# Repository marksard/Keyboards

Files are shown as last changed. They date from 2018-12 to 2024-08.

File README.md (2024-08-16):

# Keyboards

This repository is warehouse of my keyboard architecture.  

## About Firmware

[Release firmware](https://github.com/marksard/qmk_firmware_hex/releases)  
[Keymap editing web service REMAP](https://remap-keys.app/)  

## WARNING
<b>Note that for these keyboards, the design is older and also less likely to support the latest firmware and architecture.<b>  
<b>Also, KICAD files may be incomplete, they are not going to be perfect.<b>

## Rhymestone

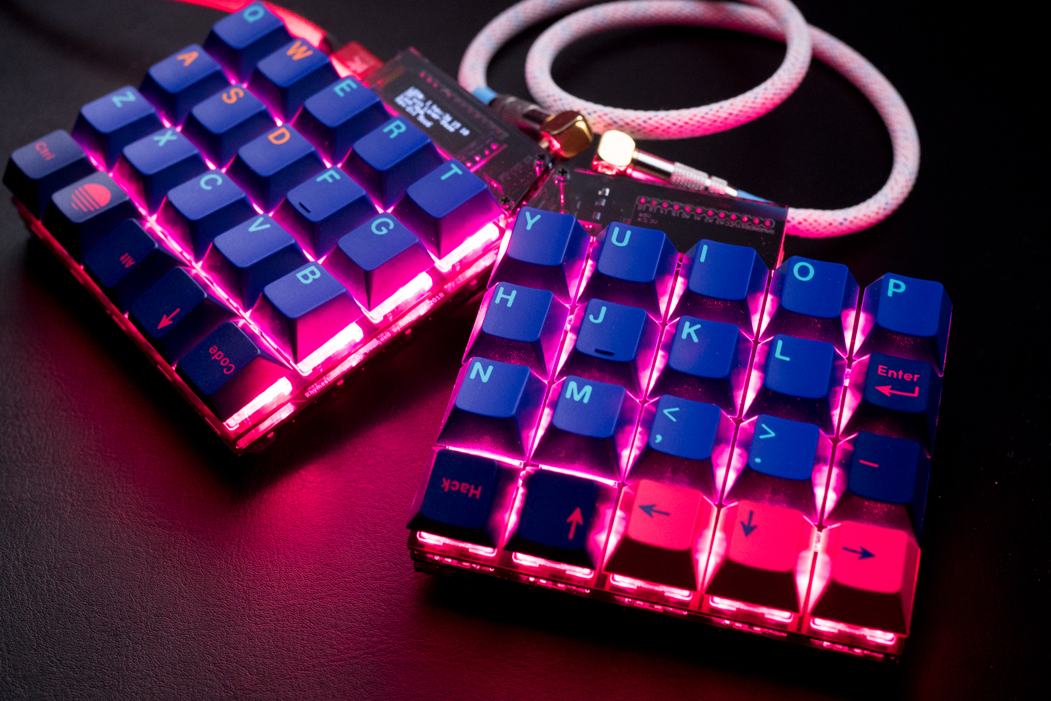
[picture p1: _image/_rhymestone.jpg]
  

### About Rhymestone

The Rhymestone is 40-key (40%) ortholinear keyboard. It is based on [The crkbd](https://github.com/foostan/crkbd) and [The Helix keyboard](https://github.com/MakotoKurauchi/helix). Thank you so much makoto kurauchi-san and foostan-san.😊  

[Build guide](./rhymestone/documents/rhymestone_buildguide.md)  
[Firmware](https://github.com/marksard/qmk_firmware/tree/own_build/keyboards/marksard/)  
[Hardware data](https://github.com/marksard/Keyboards/tree/master/rhymestone/)  

## Treadstone48

rev1  
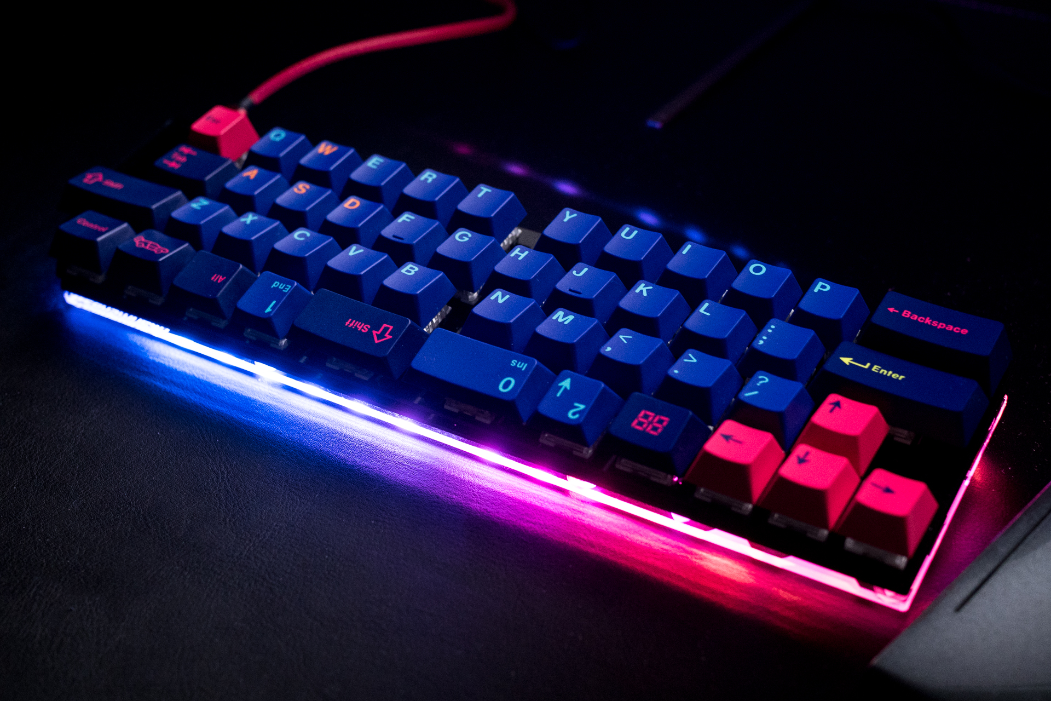
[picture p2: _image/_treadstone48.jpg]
  

rev2  
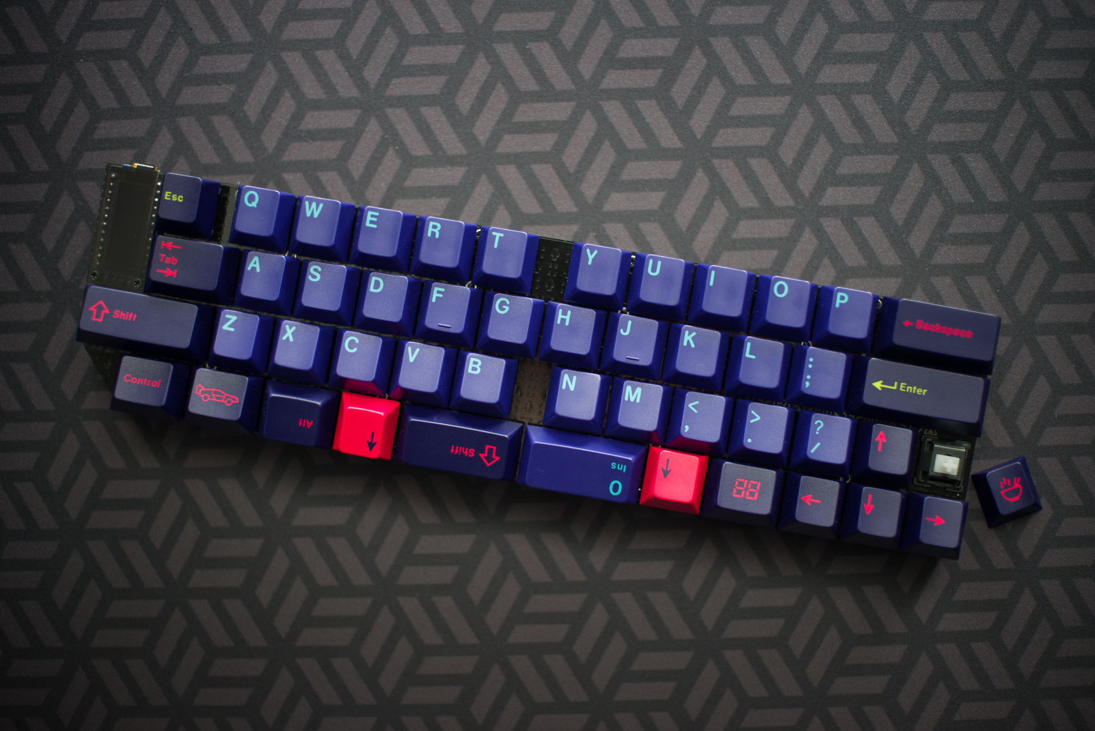
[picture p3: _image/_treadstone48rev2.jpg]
  

### About Treadstone48

The Treadstone48 is 47 or 48-key (50%) Symmetric staggered keyboard. It is based on the Rhymestone. Therefore, The Rhymestone can connect to the Treadstone48 as Numpad or lefthand keyboard. (rev1 only)  

This Symmetrical Staggered is designed to be easy to use in a natural posture and easy for your fingers to reach.  
And more one topic, this key arrangement can use general ansi 104 keycaps.

[Build guide (rev.2)](./treadstone48/documents/treadstone48rev2_buildguide.md)  

[Build guide](./treadstone48/documents/treadstone48_buildguide.md)  
[Build guide (En)](./treadstone48/documents/treadstone48_buildguide_en.md)  
[Firmware](https://github.com/qmk/qmk_firmware/tree/master/keyboards/treadstone48)  
[Hardware data](https://github.com/marksard/Keyboards/tree/master/treadstone48/)  
[About Treadstone48](https://marksard.github.io/2018/12/17/about-treadstone48/)  
[Case design sample](https://marksard.github.io/2019/04/11/wood-case/)  

## Stonehenge30 (deprecated)

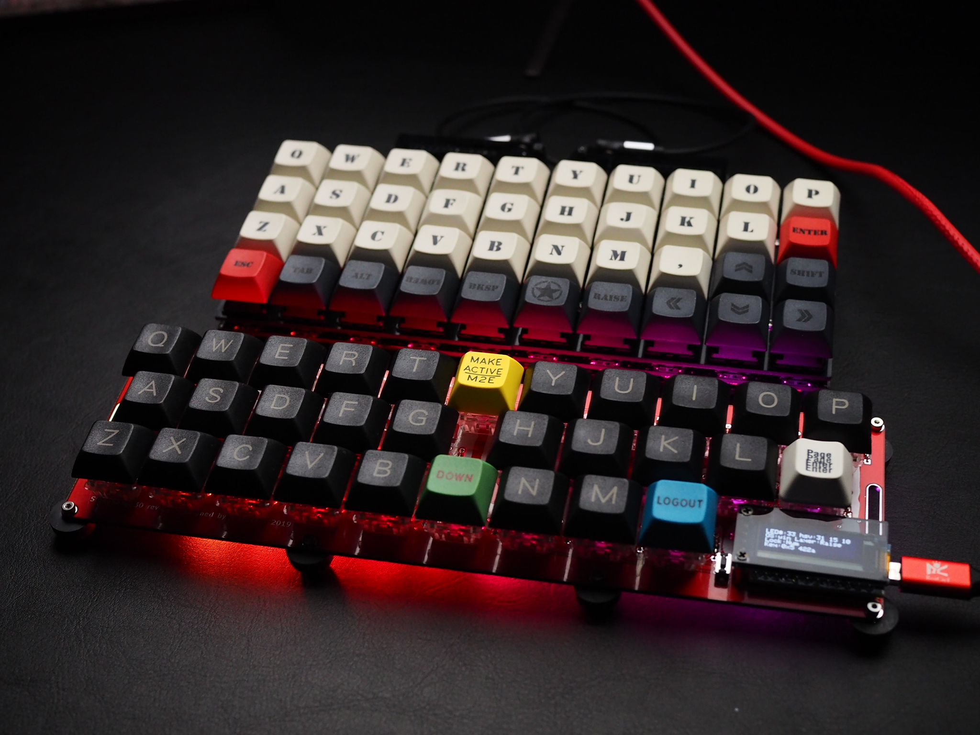
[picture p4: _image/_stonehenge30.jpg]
  

### About Stonehenge30

The Stonehenge30 is 30-key (30%) Symmetric staggered keyboard. It is based on the Treadstone48. And it is thumb-less (not use thumb) keyboard of prototype.  

[Build guide](./stonehenge30/documents/stonehenge30_buildguide.md)  
[Firmware](https://github.com/marksard/qmk_firmware/tree/own_build/keyboards/marksard/)  
[Hardware data](https://github.com/marksard/Keyboards/tree/master/stonehenge30/)  
[About Stonehenge30](https://marksard.github.io/2019/02/13/make-stonehenge30/)  
[Case design sample](https://marksard.github.io/2019/04/11/wood-case/)  

## Treadstone32

rev1  
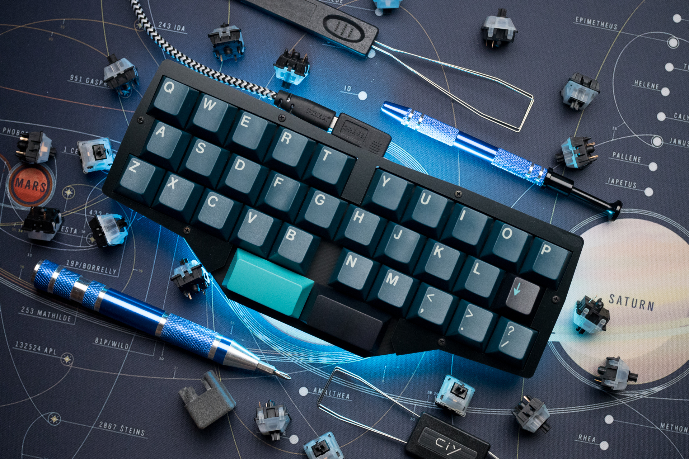
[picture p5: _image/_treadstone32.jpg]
  

lite  
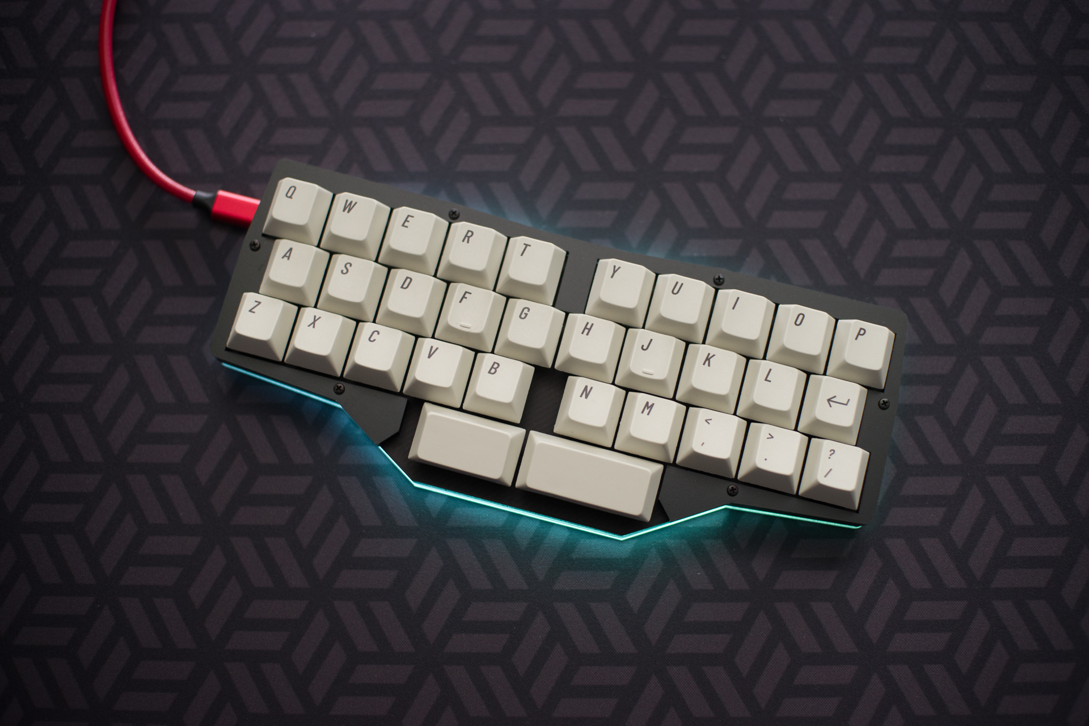
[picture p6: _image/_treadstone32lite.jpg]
  

### About Treadstone32

The Treadstone32 is 32-key (30%) Symmetric staggered keyboard. It is based on the Treadstone48 and the Stonehenge30.  
This keyboard is removing dedicated modifire-key from the Treadstone48 for more compact. But 2 thumb-key is left same as Treadtone48.  

[Build guide (lite)](./treadstone32/documents/treadstone32lite_buildguide.md)  
[Build guide](./treadstone32/documents/treadstone32_buildguide.md)  

[Build guide (En)](./treadstone32/documents/treadstone32_buildguide_en.md)  
[Firmware](https://github.com/qmk/qmk_firmware/tree/master/keyboards/treadstone32)  
[Hardware data](https://github.com/marksard/Keyboards/tree/master/treadstone32/)  
[About Treadstone32](https://marksard.github.io/2019/04/25/about-treadstone32/)  

## Treadstone60

  

### About Treadstone60

The Treadstone60 is 59-62key (60%) Symmetric staggered keyboard. It is based on the Treadstone48 and the Treadstone32.  

[Build guide](./treadstone60/documents/treadstone60_buildguide.md)  

[Firmware](https://github.com/marksard/qmk_firmware/tree/own_build/keyboards/marksard/)  
[About Treadstone60](https://marksard.github.io/2019/12/13/about-treadstone60/)  

## Leftover30

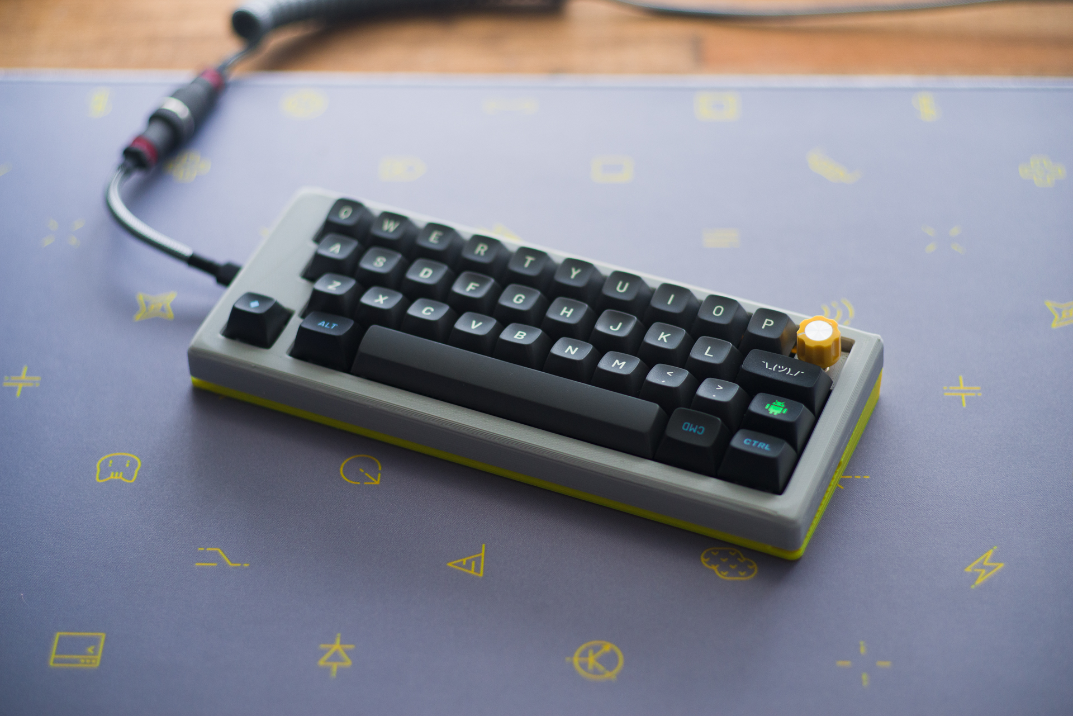
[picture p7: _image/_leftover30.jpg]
  

### About Leftover30

The Leftover30 is 34-36key (30%) Row staggered keyboard. This project was created by marksard, yohewi and hdbx.  

[Build guide](./leftover30/documents/leftover30_buildguide.md)  

[Firmware](https://github.com/marksard/qmk_firmware/tree/own_build/keyboards/marksard/)  

## Troubleshooting

[Troubleshooting](./troubleshooting.md)

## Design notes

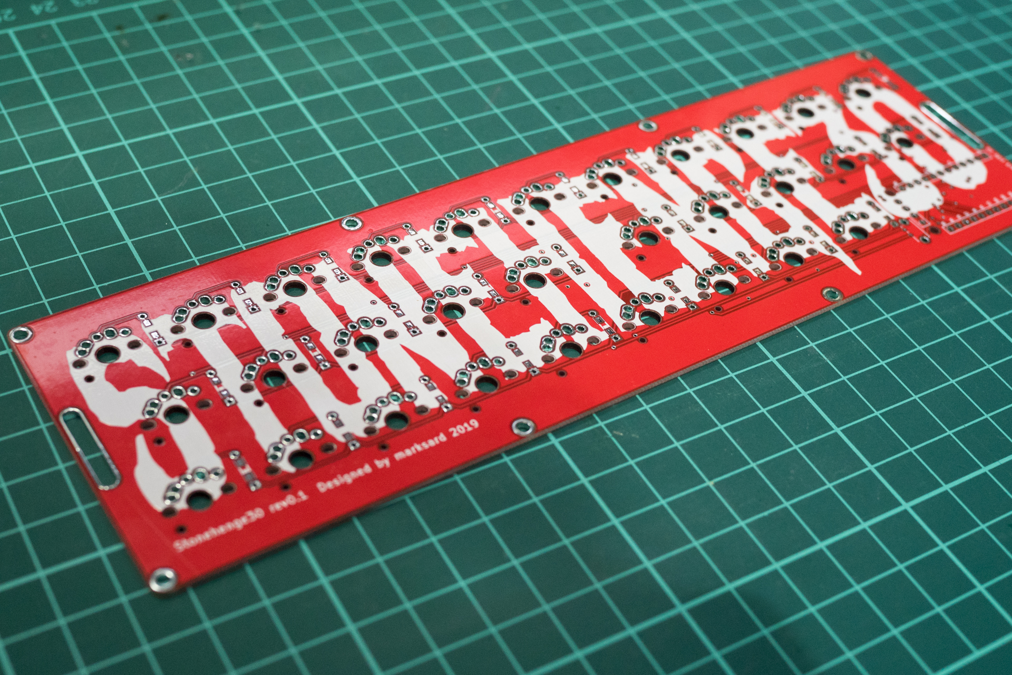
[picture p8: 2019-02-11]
stonehenge30/documents/_image/20190202-P2020237.jpg

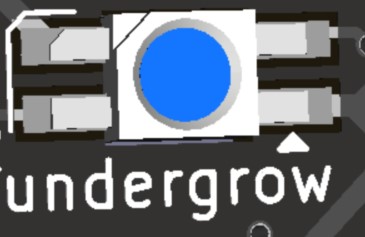
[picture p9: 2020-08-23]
leftover30/documents/_image/undergrow.jpg

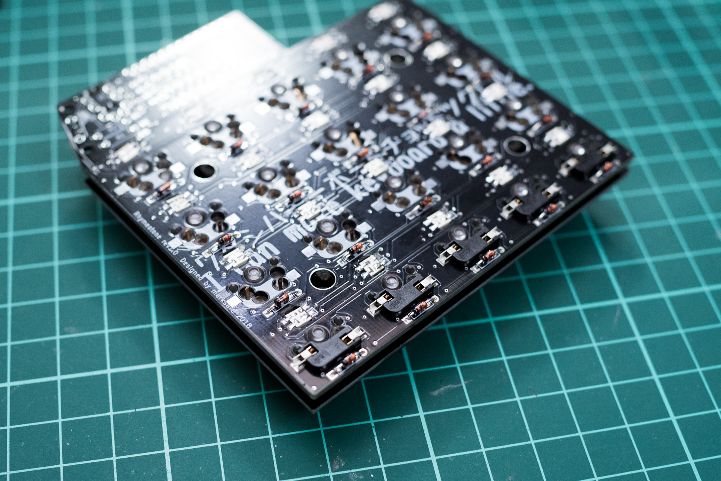
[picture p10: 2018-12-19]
rhymestone/documents/_image/20181213-PC130109.jpg

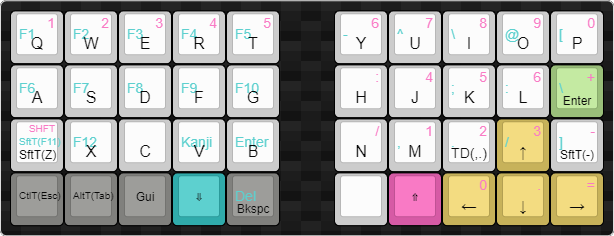
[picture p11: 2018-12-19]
rhymestone/documents/_image/rhymestone.png

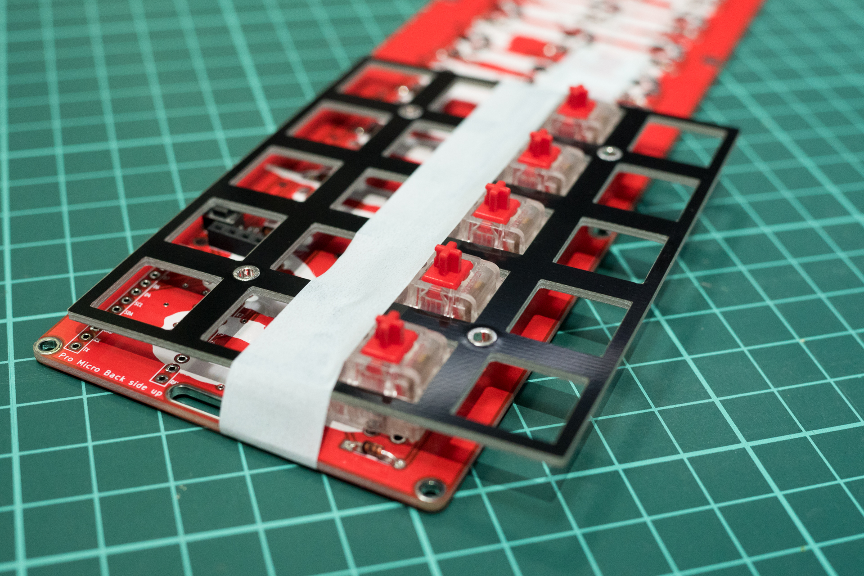
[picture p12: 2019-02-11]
stonehenge30/documents/_image/20190202-P2020240.jpg

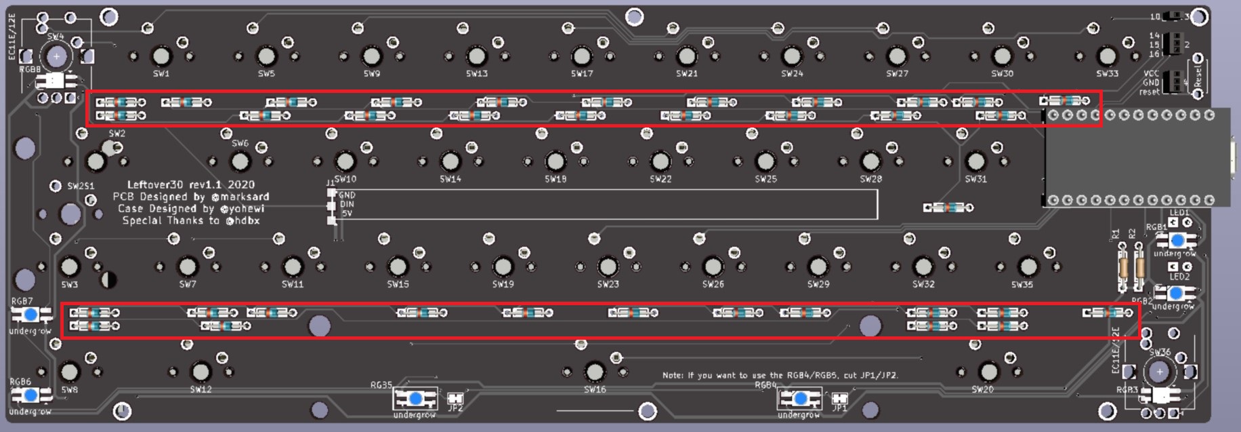
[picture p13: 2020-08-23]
leftover30/documents/_image/diode.jpg

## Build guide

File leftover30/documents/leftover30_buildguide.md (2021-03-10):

# Leftover30 ビルドガイド

## キット付属品

| 基板番号 | 数 | 名前 | 備考 |
| ---- | ---- | ---- | ---- |
| - | 1 | PCB | 基板 |
| - | 36 | 1SS178 | 1SS178（緑と黒のライン） |
| Reset | 1 | タクトスイッチ | リセットスイッチ |
| LED** | 2 | 3mm砲弾型LED | 青色と赤色 |
| R** | 2 | 抵抗 | LED用。1kΩ |
| RGB** | 6 | SK6812mini-E | アンダーグロー/バックライト用 |
| - | 1 | ケースパーツ | トップケース</br>ボトムケース</br>ロータリーエンコーダーカバー（左下用、右上用）</br>サイドアクリルパネル |
| - | 6 | M2 4mm | PCB用 |
| - | 10 | インサートナット | (Round1)ケース取り付け用 |
| - | 2 | M2 6mm | (Round1)ケース手前用 |
| - | 2 | M2 12mm | (Round1)ケース奥側用 |
| - | 12 | インサートナット | (Round2)ケース取り付け用 |
| - | 6 | M2 6mm | (Round2)ケース用 |
| - | 1 | - | ポリイミドテープ(Round2) |
| - | 4 | - | ゴム脚 |

## キット以外に必要なもの

| 名前 | 数 | 備考 |
| ---- | ---- | ---- |
| MicroUSBケーブル | 1本 | キーボードとPC接続用 |
| キースイッチ | 33～36個 | Cherry MXもしくは互換品で5pin仕様のものが必須 |
| キーキャップ | - | Cherry MXスイッチ対応品。ANSI104セット対応 |
| スタビライザー | 1～2個 | 6.25Uが1個。ISOエンターを選択した場合は2Uが1個 |
| ProMicro | 1個 | |
| コンスルー（スプリングピンヘッダ） 12P | 2個 | 推奨 |
| ロータリーエンコーダー | 0～1個 | Alps EC11/12系もしくは互換品 |
| ロータリーエンコーダー用つまみ | 0～1個 | 外径が19mm程度以下のもの（大きいとキーキャップや内枠に干渉する場合があります） |

## 注意：パーツ選択について

### MX互換スイッチについて

必ず5pinのものを用意してください。3pinのものだとそれぞれのスイッチが直角並行に並ばず、キーキャップを付けた時の見た目が悪くなります。  

### ロータリーエンコーダーについて

AlpsEC11/12互換のプッシュスイッチ付き垂直ロータリーエンコーダーに対応しています。  
互換品でよく出回っているBourns社のPEC12Rにも対応しています。  

## レイアウトの選択

### ロータリーエンコーダーとスイッチの選択

最初にレイアウトを決めます。赤枠にはMXスイッチと、AlpsEC11系シリーズ互換のロータリーエンコーダーのどちらかを選択できます。  
この位置に光を透過するタイプのMX互換スイッチを選び、バックライトLEDを取り付け、透過するアルチザンキーキャップを置いて輝かせることが可能です。  
ロータリーエンコーダーはどちらか一か所に取り付け可能です。二つ同時には取り付けられません（もし付けても両方のつまみは同じ動作となります）。  

よって選択肢は

- 左下、右上ともスイッチ
- 左下ロータリーエンコーダー、右上スイッチ
- 左下スイッチ、右上ロータリーエンコーダー

の3パターンが選択可能です。

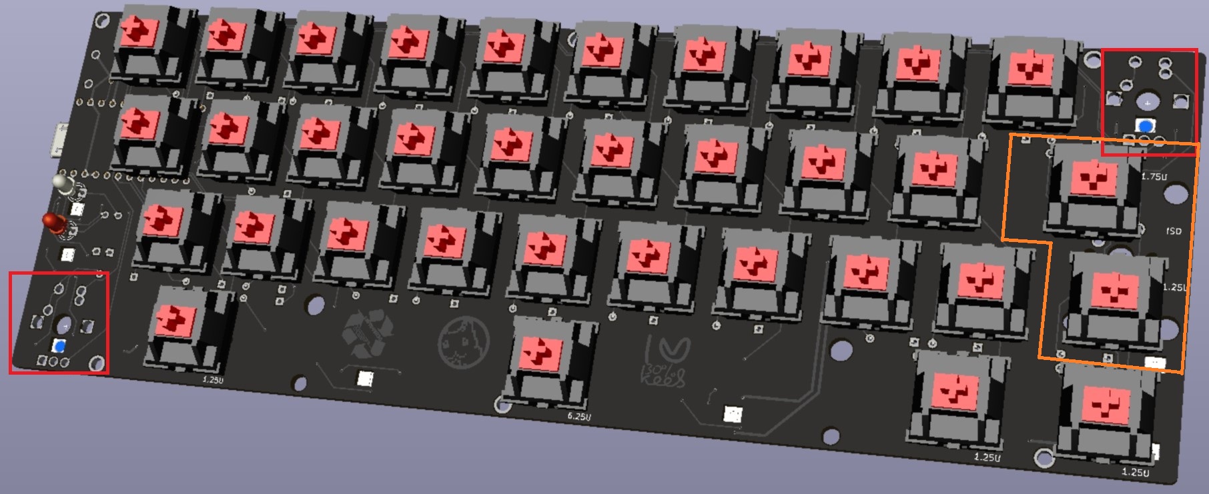
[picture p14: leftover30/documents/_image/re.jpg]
  

### エンターキーキャップの選択

橙枠は1.75Uキーと1.25Uキーの2キーを配置するか、ISOエンターの1キーを配置するかを選択出来ます。  
ISOエンターを選択した場合、LキーとISOエンターの間が0.25U隙間が出来ます。また、2Uスタビライザーが必要となります。  

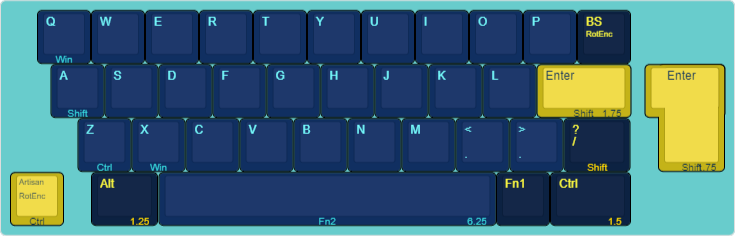
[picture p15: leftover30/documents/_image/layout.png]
  

## promicroの準備

　promicroのコネクタ補強、コンスルーピンのはんだ付けを行ってください。  
　promicroは実装されている面がキーボード基板に向くようにコンスルーを取り付けてください。  
 - promicroのコネクタ補強：[ProMicroのモゲ防止ついでにQMK_Firmwareを書き込む](https://qiita.com/hdbx/items/2f3e4ddfcadda2a5578e)
 - コンスルーピンのはんだ付け：[Helixベータ ビルドガイド](https://github.com/MakotoKurauchi/helix/blob/master/Doc/buildguide_jp.md)

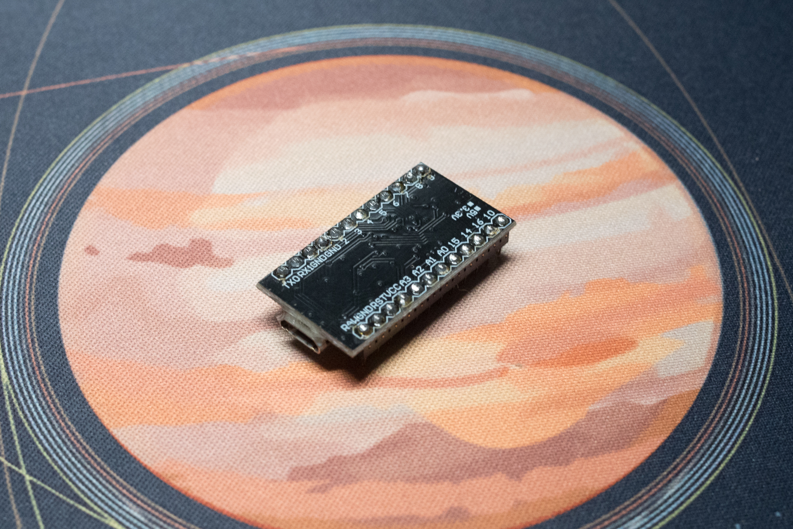
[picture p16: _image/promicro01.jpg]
  
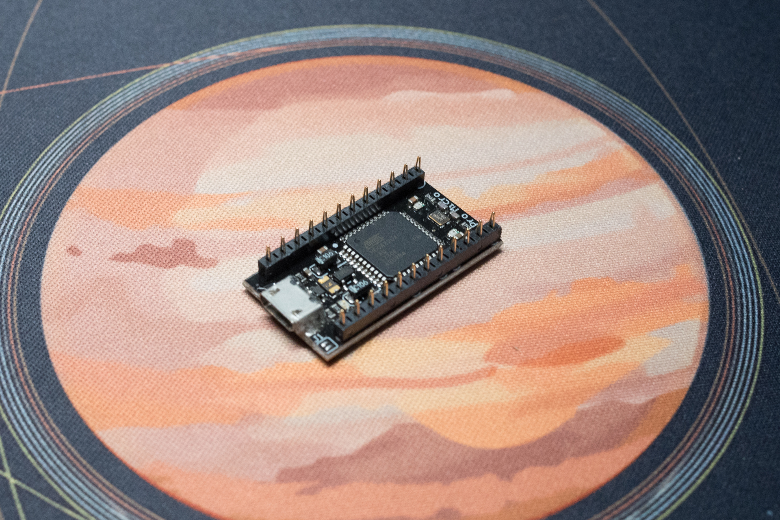
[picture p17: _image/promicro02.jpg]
  

### キーボード用ソフトウェアをpromicroに書き込む

　このキーボードはQMKというキーボード用のソフトウェアで動作します。お買い上げの時点ではこのソフトウェアが入っていない状態ですので、書き込む必要があります。  

1. [QMK Toolbox](https://github.com/qmk/qmk_toolbox/releases)をダウンロードし、インストールします
2. [marksard/qmk_firmware_hex](https://github.com/marksard/qmk_firmware_hex/releases)にある最新のhexファイルからmarksard_leftover30_via.zipをダウンロード、zipを展開します
3. QMK Toolboxの「open」ボタンをクリックして、先程展開しhexファイルを選択します
4. QMK Toolboxの「Auto-Flash」チェックボックスにチェックを入れてpromicro(直付けの場合は基板)をPCに接続し、リセットボタンを押して書き込みます。
   1. （リセットボタンをダブルクリックしないと書き込めないパターン、初回のみリセットボタンを押下しなくても書き込みが始まるのものもあります）

書き込み方法などはサリチル酸さんの[（初心者編）自作キーボードにファームウェアを書き込む](https://salicylic-acid3.hatenablog.com/entry/qmk-toolbox)の記事が参考になります。  

#### REMAPを使用する

　上記で書き込んだファイルはVIA対応ファームウェアで、ファームウェアを書き直さなくてもアプリケーション上からキー設定を変更することが出来ます。  
　ここでは国産のVIA対応キーマップ変更アプリケーションとして、WEB上からキーボードの設定が出来る[REMAP](https://remap-keys.app/)を紹介します。  
対応したキーボードを接続した状態で、「START REMAP FOR YOUR KEYBOARD」→「+KEYBOARD」ボタンを押下するとキーボード名が出ます。それを押下することでカスタマイズ画面が出てきます。  

詳しい操作方法などについてはサリチル酸さんの[（初心者編）Remapを使ってキーマップを書き換えよう](https://salicylic-acid3.hatenablog.com/entry/remap-manual)の記事が参考になります。  

　この初期状態はUSキーボード（＋日本語JISキーボードのキー配置あり）mac向けとなっていますので、適宜変更する必要があります。  
Win/Mac切り替えは(Layer3キー + E位置のキーでmac向け、Layer3キー + R位置のキー)になっています。  
漢字/英字切り替えは(Layer2キー + B位置のキー)になっています。
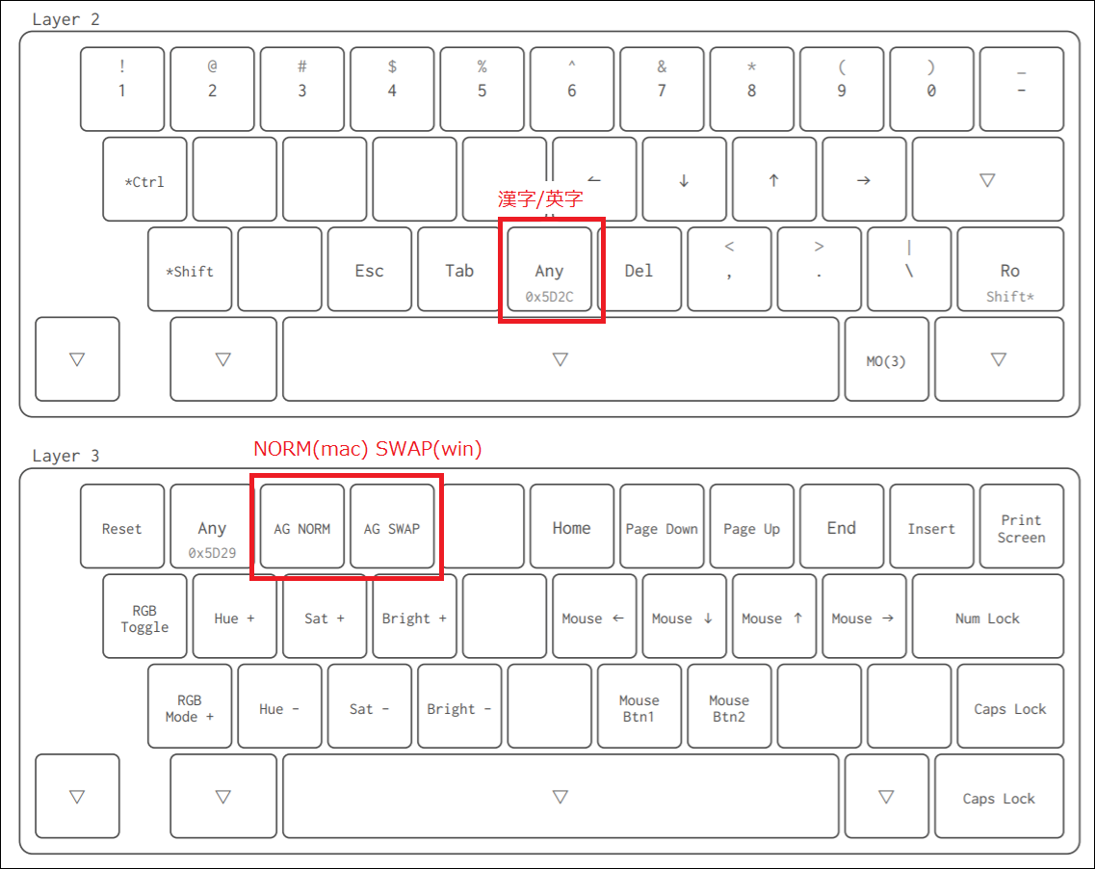
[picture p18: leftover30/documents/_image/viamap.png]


#### ビルド環境を作成する

　現状、以下のようなカスタムはソースファイルからビルドする必要があります。  

- ロータリエンコーダーの動作のカスタマイズ
- タップと長押しの判定タイミングを調整する
- OLED表示の内容を変更

　ソースからビルドが出来るようになると他の多彩な機能を扱え、細かい動作まで自在にカスタムすることが出来ます。  

[QMK　ビルド環境を準備する](https://docs.qmk.fm/#/ja/newbs_getting_started)  

　leftover30のデフォルトキーマップは  
```qmk compile -kb marksard/leftover30 -km default```
で可能です。書き込む場合は
```qmk flash -kb marksard/leftover30 -km default```  
とすると、コンパイルが完了次第書き込み待ちになるので、その状態で基板にあるリセットボタンをクリック、もしくはダブルクリックで書き込みが始まります。  

## ダイオードのはんだ付け

赤枠の位置にダイオードを向きを合わせてはんだづけします。  
向きについては以下に従ってください。  
![img](./_image/diode.jpg)  
![img](./_image/diode2.jpg)  

## 抵抗のはんだ付け（オプション）

インジケータLEDを取り付ける場合は赤枠の位置に抵抗を取り付けてください。  

![img](./_image/register.jpg)  
![img](./_image/register2.jpg)  

## フルカラーLED(SK6812mini-E)のはんだ付け（オプション）

この基板は付属のチップLEDを標準で6個取り付けることが出来ます。  
赤枠部分はアンダーグローで、ケースサイドのアクリル点灯用です。  
橙枠部分はバックライトで、BackSpace位置、アルチザン置き場位置のキーキャップ点灯用です。  
薄青枠部分は取り付けません。  
![img](./_image/sk6812mini-e.jpg)  
![img](./_image/sk6812mini-e2.jpg)  

### アンダーグロー側のはんだ付け

SK6812mini-Eは取り付ける向きがあります。点灯部分をこちらに向けて、基板に書かれた切り欠きあわせ表示（┏）にSK6812mini-Eの切り欠きを合わせてはんだ付けしてください。  
![img](./_image/undergrow.jpg)  

### バックライト側のはんだ付け

SK6812mini-Eは取り付ける向きがあります。点灯部分を反対側に向けて、基板に書かれた切り欠きあわせ表示（┏）にSK6812mini-Eの切り欠きを合わせてはんだ付けしてください。  
![img](./_image/backlight.jpg)  

### リセットボタンのはんだ付け

　リセットボタンは取り付けに向きはありません。写真のようにはんだ付けてください。  
![img](./_image/reset.jpg)  

## スイッチのはんだ付け

スイッチをはんだ付けしていきます。最初は四隅に近いところを先にはんだ付けすると作業がしやすいです。  
穴が大きめに開いている都合上はんだをドバドバ吸い込むのである程度で留めるのが吉です。  

![img](./_image/switch.jpg)  

### ロータリーエンコーダーとの選択部分にスイッチをはんだ付けする場合の注意点

ロータリーエンコーダーと選択可能な左下と右上は、基板の穴が大きいため5pinのスイッチを使っても斜めについてしまう場合があるかもしれません。  
まっすぐはんだ付け出来るように、マスキングテープなどでまっすぐな状態を維持して少量のはんだで仮固定、キャップを付けて隣同士が水平になっているか確認して大丈夫そうならスイッチをちゃんとハンダ付してください。  

### promicro上のスイッチのはんだ付けする場合の追加処理

赤枠はpromicroの上にスイッチが1キー被ります。スイッチのピンがpromicroにあたって動作が不安定になる可能性がありますので、はんだ付けした後に出っ張っているスイッチの金属ピンをカットしてください。  

![img](./_image/sw_promicro.jpg)  
![img](./_image/sw_promicro2.jpg)  

## ロータリーエンコーダーのはんだ付け（オプション）

ロータリーエンコーダーを付けたい位置に合わせてはんだ付けしてください。  

## インジケータLED(3mm砲弾型LED)のはんだ付け（オプション）

赤色と青色（LEDプラ自体は透明ですが青く光ります）LEDを付属しています。デフォルトのファームウェアではLED1はNumLock、LED2はCapsLockで点灯するようになっています。好みのほうに好みの色で取り付けてください。ケースカラーによってLEDの色が判別しにくいため、どっちでもあまり変わらないかもしれません。  
LEDは取り付ける向きがあります。脚の長いほう（アノード、＋）を丸い銀枠の穴（基板端側）に差し込みます。  

基板から、LEDの発光部のプラスチック底面までを4mm程度浮かせてはんだ付けしてください（LEDのリード線の太さがちょっと違う所あたりで約4mm程度です）。  
はんだ付けが終わったら写真のように少し傾きを付けて、トップフレームのインジケータLEDが収まるくぼみの位置を合わせておきます。  
![img](./_image/led.jpg)  
![img](./_image/led2.jpg)  
![img](./_image/led3.jpg)  
![img](./_image/led4.jpg)  

## スタビライザーの取り付け

　赤枠の位置にスタビライザーを針金が黄色い線側になるように取り付けます。  
　ISOエンターのレイアウトを選択した場合は青枠内の位置に同様にスタビライザーを取り付けてください。  
![img](./_image/stab.jpg)  
![img](./_image/stab2.jpg)  

## インサートナットの埋め込み

　はんだごての熱を利用して、ケースのビス留め位置にインサートナットを埋め込みます。取り付け位置は赤丸位置で10個所あります。  

- PCBとケースのネジ留め：6個所
- ケース同士のネジ留め：4個所
- (Round2ケースはケース同士のネジ止め箇所が中央手前と奥が増えて全部で6個所になっています)

![img](./_image/case_top.jpg)  
![img](./_image/case_bottom.jpg)  

　PCBとケースのネジ留めに使うインサートナットは、ケースの挿入面に対して垂直に。  
　ケース同士のネジ留めに使うインサートナットは下図を観てもわかるように少し傾いていますので、気持ちケース手前方向に傾けてインサートナットを挿入してください。  

![img](./_image/case.png)  

　はんだごてのこて先ははんだごてを買うと付属してくる円錐状のものを利用します。もし温度調整可能なはんだごてを利用している場合は一番低い温度に設定してください。  
　インサートナットの向きは穴の広いほう（座グリされてるほう）からネジを入れるので、そちらがケースから顔をのぞかせる方向になるように注意してください。  
　ピンセットも必要ですのですぐに使えるように準備してください。

　やりかたは以下の通りです。頭でシミュレーションしてから実施してください。  

- あらかじめケースの穴にはんだごてを直接差し込んで、穴をほんの少し広げておく（ネジ穴にケース材が入るのを防ぐ）
- インサートナットの穴の狭い方に黄色いポリイミドテープを小さく切って穴をふさぐ（ネジ穴にケース材が入るのを防ぎますが、ポリイミドテープは400度付近で溶けますので温度設定には注意してください）
- 穴位置を確認して、インサートナットを穴の広いほう（座グリされてるほう）を上に向けて置く
- こて先をキレイにして、温度調節可能なら270度などの低い温度に設定して、インサートナットにはんだごてをあてる（3Dプリントケースは200度程度で溶けだします）
- 上からゆっくりとケースの穴の周りを溶かしながら入れる
- ケース面まで埋めたらはんだごてをはずす
- 冷えるまで30～60秒は待つ

![img](./_image/case_ins1.jpg)  
![img](./_image/case_ins2.jpg)  

[![insertnut](http://img.youtube.com/vi/4Yi3AIbshDU/0.jpg)](http://www.youtube.com/watch?v=4Yi3AIbshDU)

　ケースの素材がナットの周辺に盛り上がってしまった場合、冷えてからニッパーなどで切り落としてください。  
　もし斜めだったり、穴位置がずれていたりする場合はもう一度はんだごてを当てて修正してください。  
　修正しすぎて穴が広がった場合、穴の周辺にはんだごてをあてて穴を少し狭めてからやりなおしてください。  

　インサートナットを取り付けたら一度トップケースとボトムケースを合わせてネジ留め出来るか仮組確認してください。ケース奥側は12mm、ケース手前側は6mmのネジで留めます。  

## ロータリーエンコーダーカバーの取り付け

　ロータリーエンコーダーを取り付けた場合はカバーを取り付けてください。  
　左下用はケースにハメ込めるようになっています。  
　右上用はロータリーエンコーダーの外装にハメ込めるようになっています。  

![img](./_image/re_cover.jpg)  
![img](./_image/re_cover2.jpg)  

## ケースの組み立て

### PCBをボトムケースに取り付ける

　PCBをボトムケースのネジ穴に合わせて置き、4mmのネジで留めてください。  

### トップケースをボトムケースに取り付ける

　トップケースをボトムに合わせます。ケース手前にはスリットが設けられており、ここにアクリルを挟みます。挟んだら6mmのネジで留めます。ケース奥側は12mmのネジで留めます。  

![img](./_image/sidegrow.jpg)  

### ゴム脚について

　このキーボードはソフトな打鍵感を意識して設計しています。ゴム脚を装着するとケースとデスクの間に空間が生まれさらに柔らかくなりますので、特にデスクマット上での使用を前提とする場合は取り付けないほうが良い打鍵感を得られる場合があります。ゴム脚を付ける前に打鍵感をチェックしてみてください。  

## キーキャップ、つまみを取り付けて完成です

　お好きなキーキャップと、ロータリーエンコーダーを取り付けている場合は好きなつまみを取り付ければ完成です！

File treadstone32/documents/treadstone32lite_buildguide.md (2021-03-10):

# Treadstone32 Liteビルドガイド

## キット付属品

| 基板番号 | 定数 | 数 | 名前 | 備考 |
| ---- | ---- | --- | --- | --- |
| - | - | 1 | PCB | 基板 |
| - | - | 32 | 1N4148 or 1SS178 | ロットにより1N4148（黒ライン）か1SS178（緑と黒のライン）どちらか |
| - | - | 1 | リセットスイッチ |  |
| - | - | 1 | マウントプレート | スイッチをはめ込むプレート |
| - | - | 1式 | アクリルケースパーツ | </br>2mmボトムプレート</br>2mmボトムミドル</br>5mmボトムミドル</br>5mmトップカバー |
| - | M2 8mm | 6 | 低頭ネジ |
| - | M2 4mm | 6 | 低頭ネジ |
| - | M2 スペーサー 7mm | 6 | 丸型 全ねじスペーサー |
| - | 2mm | 5 | ゴム脚 |  |

## キット以外に必要なもの

| 名前 | 数 | 備考 |
| ---- | ---- | --- |
| MicroUSBケーブル | 1本 | キーボードとPC接続用 |
| キースイッチ | 32個 | MX互換のもの |
| キーキャップ | 1U 30個、2U 2個 | MX互換のもの |
| ProMicro | 1個 | |
| コンスルー（スプリングピンヘッダ） 12P | 2個 | 推奨 |

### オプション

オプションでイルミネーション用LEDを取り付け可能です。  

| 名前 | 数 | 備考 |
| ---- | ---- | --- |
| LEDストリップ（WS2812B 6個付き） | 1個 | Underglow用（オプション） |

## 必要な道具

| 名前 | 備考 |
| ---- | ---- |
| はんだごて | |
| 糸ハンダ | 0.8mm程度のものを推奨します |
| ハンダ吸い取り線 | 失敗したとき用 |
| ニッパー | ダイオードのリード線などの切断用です |
| ピンセット | ProMicroリセットしたりチップLEDのはんだづけで使用します |
| フラックス除去剤 | 必須ではありませんがはんだ付け後のベタつきを除去出来、はんだによる黄色い変色も拭き取れてキレイな仕上がりになります |
| マスキングテープ | しるし付け、仮固定に使用。100均の柄付きでもOK |

　mteiさんの[Helix キーボードキットの製作に必要な工具メモ](https://gist.github.com/mtei/6957107a676ddfa85bde0ae41f8fa849)
やhdbxさんの[自作キーボードを始めるにあたって用意すべきツール](https://hdbx.hateblo.jp/entry/2018/06/01/215401)も参考になります。  

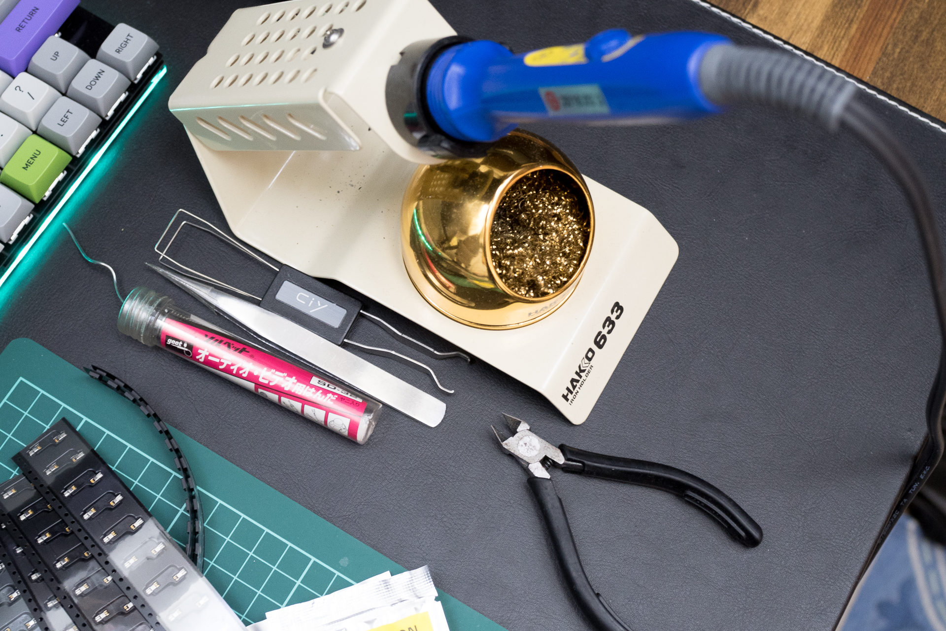
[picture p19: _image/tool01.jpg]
  
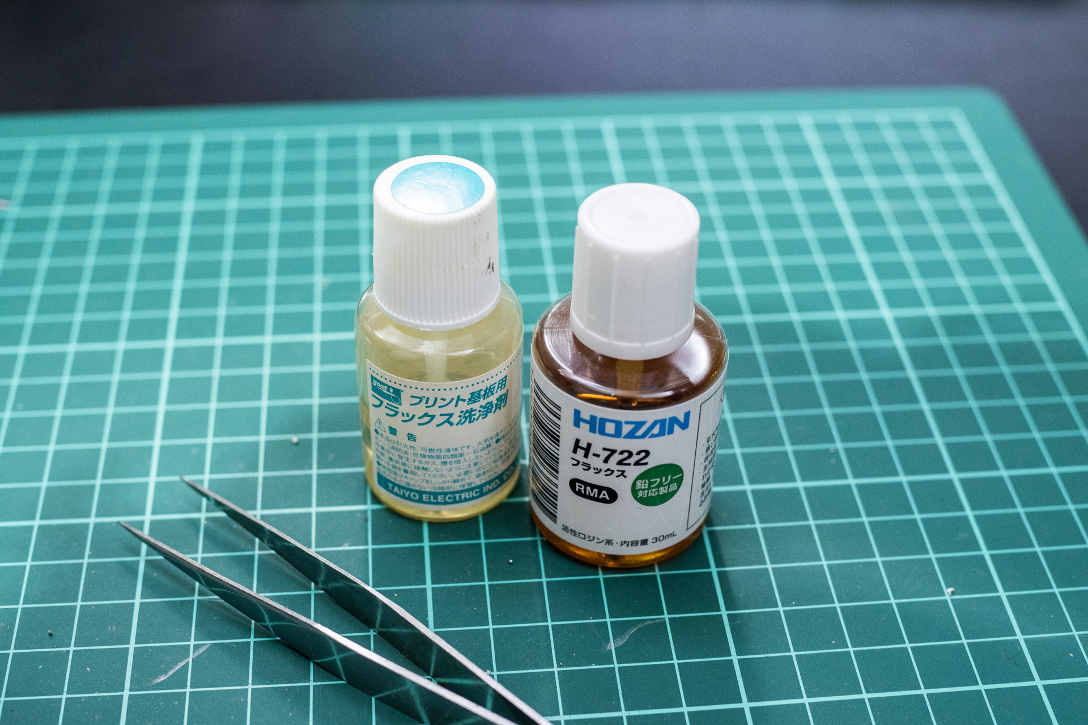
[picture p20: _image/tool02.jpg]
  

## promicroの準備

　promicroのコネクタ補強、コンスルーピンのはんだ付けを行ってください。  
　promicroは実装されている面がキーボード基板に向くようにコンスルーを取り付けてください。  
 - promicroのコネクタ補強：[ProMicroのモゲ防止ついでにQMK_Firmwareを書き込む](https://qiita.com/hdbx/items/2f3e4ddfcadda2a5578e)
 - コンスルーピンのはんだ付け：[Helixベータ ビルドガイド](https://github.com/MakotoKurauchi/helix/blob/master/Doc/buildguide_jp.md)

  
  

### キーボード用ソフトウェアをpromicroに書き込む

　このキーボードはQMKというキーボード用のソフトウェアで動作します。お買い上げの時点ではこのソフトウェアが入っていない状態ですので、書き込む必要があります。  

1. [QMK Toolbox](https://github.com/qmk/qmk_toolbox/releases)をダウンロードし、インストールします
2. [marksard/qmk_firmware_hex](https://github.com/marksard/qmk_firmware_hex/releases)にある最新のhexファイルからtreadstone32_lite_via.zipをダウンロード、zipを展開します
3. QMK Toolboxの「open」ボタンをクリックして、先程展開しhexファイルを選択します
4. QMK Toolboxの「Auto-Flash」チェックボックスにチェックを入れてpromicro(直付けの場合は基板)をPCに接続し、リセットボタンを押して書き込みます。
   1. （リセットボタンをダブルクリックしないと書き込めないパターン、初回のみリセットボタンを押下しなくても書き込みが始まるのものもあります）

書き込み方法などはサリチル酸さんの[（初心者編）自作キーボードにファームウェアを書き込む](https://salicylic-acid3.hatenablog.com/entry/qmk-toolbox)の記事が参考になります。  

#### REMAPを使用する

　上記で書き込んだファイルはVIA対応ファームウェアで、ファームウェアを書き直さなくてもアプリケーション上からキー設定を変更することが出来ます。  
　ここでは国産のVIA対応キーマップ変更アプリケーションとして、WEB上からキーボードの設定が出来る[REMAP](https://remap-keys.app/)を紹介します。  
対応したキーボードを接続した状態で、「START REMAP FOR YOUR KEYBOARD」→「+KEYBOARD」ボタンを押下するとキーボード名が出ます。それを押下することでカスタマイズ画面が出てきます。  

詳しい操作方法などについてはサリチル酸さんの[（初心者編）Remapを使ってキーマップを書き換えよう](https://salicylic-acid3.hatenablog.com/entry/remap-manual)の記事が参考になります。  

　この初期状態はUSキーボード（＋日本語JISキーボードのキー配置あり）mac向けとなっていますので、適宜変更する必要があります。  
Win/Mac切り替えは(Layer3キー + E位置のキーでmac向け、Layer3キー + R位置のキー)になっています。  
漢字/英字切り替えは(Layer1キー + B位置のキー)になっています。
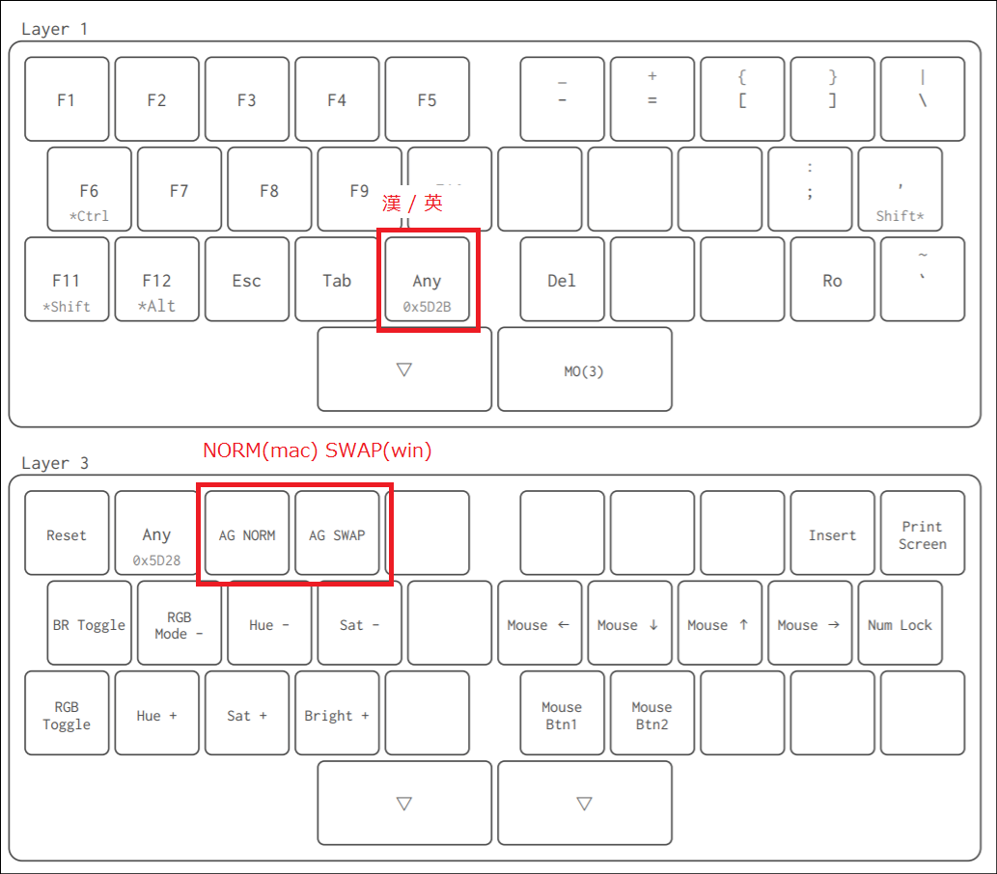
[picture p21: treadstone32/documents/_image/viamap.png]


#### ビルド環境を作成する

　現状、以下のようなカスタムはソースファイルからビルドする必要があります。  

- ロータリエンコーダーの動作のカスタマイズ
- タップと長押しの判定タイミングを調整する
- OLED表示の内容を変更

　ソースからビルドが出来るようになると他の多彩な機能を扱え、細かい動作まで自在にカスタムすることが出来ます。  

[QMK　ビルド環境を準備する](https://docs.qmk.fm/#/ja/newbs_getting_started)  

　treadstone32liteのデフォルトキーマップは  
```qmk compile -kb treadstone32/lite -km default```
で可能です。書き込む場合は
```qmk flash -kb treadstone32/lite -km default```  
とすると、コンパイルが完了次第書き込み待ちになるので、その状態で基板にあるリセットボタンをクリック、もしくはダブルクリックで書き込みが始まります。  

## 基板の裏と表について

　キースイッチが乗り、通常使用する際上を向く面を表、逆を裏とします。  
　Treadstone32Liteはロゴマークがシルク印刷されているほうが裏面です。  

## ダイオードをはんだ付けする

### ダイオードの脚を曲げる

　基板に付ける前にダイオードの脚を全部曲げてしまいます。基板の穴の間隔を見極めて曲げるための冶具を探してみてください。繋がったままの割りばしなどでも良いと思います。  

![img](../../_image/diode01.jpg)  

### ダイオードのはんだ付け

　ダイオードの取り付け向きは同じ方向なので、一つ確認して取り付けたら残りはすべて同じ方向で取り付けられます。ダイオードの黒や緑の帯側を基板のダイオード取り付け穴の四角いほうに向けて取り付けてください。  

![img](../../_image/diode02.png)  

　基板のウラ面からダイオードを差し込んでいきます。差し込んだらダイオードの足同士をネジって仮留めします。横一列ずつ差し込んでまとめてハンダ付けするとラクに速く出来ます。ハンダ付けしたら足を根元からカットしてください。  

## リセットボタンのはんだ付け

　スイッチがシルク印刷に収まる方向にはんだ付けしてください。  

![img](_image/lite_reset.jpg)  

## スイッチのはんだ付け

　スイッチの向きに注意してマウントプレートにはめこみます。そのあと、写真のように合わせてはんだ付けしてください。  
※写真は動作検証のためソケット化するカスタムをしています。

![img](_image/20200509-P5090001.jpg)  

## *(オプション)UnderglowLEDをはんだ付けする*

　テープLEDの剥離紙の両端数cmだけハサミなどでカットします。これはテープLEDの背面の端子と、キーボード基板のスルーホールなどの端子が接触して動作不良を起こすことを防ぐ意味合いがあります。  

![img](../../_image/led_tape.jpg)  

　テープLEDは向きがありテープLEDの端子と基板の端子が合う向きにします。
![img](_image/20200509-P5090001.jpg)  

## 動作確認をこの時点で行う

　あとはケースを組み立ててキーキャップをつけるだけですが、ケースを組み立てるのと分解するのが若干面倒なのと、ダイオードがキチンと半田付けされているかの動作確認を済ませておくとケース組み立てが一回で済むので「ファームウェアの準備と書き方」を見てファームウェアを書き込んで動作確認をしてください。  

### 動作確認

　デフォルトキーマップの場合、Lower、Raise（左親指キー、右親指キー）の順で押下するとAdjustレイヤーになります。押下したまま、Aキーを押下するとLEDのON/OFFです。光らない場合はLEDの取り付け向きやはんだ箇所をチェックしてください。  

## キーキャップの取り付け

　ケースの組み立て時、トップレイヤーとキーキャップが干渉しないように取り付ける必要があるので、先にキーキャップをハメ込んでください。  

## ケースの組み立て

　ケースのパーツは2mm厚のものと、5mm厚のものがあります。  
　2mmボトムプレートと2mmボトムレイヤーを合わせてみて、ボトムレイヤーにスペーサーをはめ込む場所が6箇所あります。その位置にボトムプレートへM2 4mmのネジで取り付けてください。  
　ProMicro用の切り欠きがあるので、写真のように2mmのフレームを合うように組み合わせてください。  

![img](_image/20200509-P5090002.jpg)  

以下の順番で乗せていきます。  

| 層名 | 厚み | 上 |
| --- | --- | --- |
| トップレイヤー | 5mm |  |
| マウントプレート(PCB付) | 1.2mm |  |
| ミドルレイヤー | 5mm |  |
| ボトムレイヤー | 2mm |  |
| ボトムプレート | 2mm | 下 |

　全部乗せたら、トップレイヤーの位置をキーキャップに干渉しないように位置を合わせながらM2 8mmネジで6箇所留めてください。  
　ゴム脚は四隅と、2つの親指キーの間手前に一つ貼ってください。  
　添付のゴム脚の厚みは1.6mmのものです。気になるようでしたら追加でゴム脚を貼ってみてください。  
　左奥側はProMicroに干渉するので、ゴム脚をカットして貼り付けてください。  
　また、ProMicroのピン部分が机に干渉する場合があるので、ニッパーでキレイにカットしておいてください。  

![img](_image/20200509-P5090002a.jpg)  

## 完成

　チェックして問題なさそうなら完成です！あなただけの一台に仕上げてください！  

![img](_image/20200119-P1190029.jpg)  

## キースイッチの交換方法

　手では取り外しにくいため、amazonなどで販売されているキースイッチ引き抜き工具を使用して交換してください。

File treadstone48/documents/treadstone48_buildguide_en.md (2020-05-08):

# Treadstone48 Build Guide

## List of parts

### Parts included when buying the TS48 kit

| Name | Quantity | Note |
| ---- | ---- | --- |
| PCB | 1 | |
| Mount Plate | 1 | FR4(PCB plate) |
| Acrylic Bottom Plate | 1 | |
| Acrylic Pro Micro Cover | 1 | |
| M2 spacer 8mm | 2 | use with Acrylic Pro Micro Cover |
| M2 spacer 7mm | 8 | use with Acrylic Bottom Plate |
| Plastic spacer 2mm | 8 | use with Acrylic Bottom Plate |
| M2 Screw 4mm | 18 | |
| M2 Black Screw 4mm| 2 | Top use with Acrylic Pro Micro Cover |
| Rubber Feet | 8 |  |
| 1N4148 diode | 48 |  |
| TRRS Jack | 1 | not use |
| Reset Switch | 1 | |

### Please purchase separately (not included)

| Name | Quantity | Note |
| ---- | ---- | --- |
| MicroUSB cable | 1 | |
| Key Switches | 47～48 | Compatible for MX |
| Key Caps | 47～48 | compatible for MX stem, Better than ANSI104 keysets |
| Pro Micro | 1 | |
| Pin  12P | 2 | For use with Pro micro |
| Kailh MX Socket | 47〜48 | Kailh socket |
| *Stabilizer* | *1～2* | *PlateMount* |
| *LED strip（WS2812B x6）* | *2* | *Underglow* |

### Firmware

[Treastone48 QMK Directory](https://github.com/qmk/qmk_firmware/tree/master/keyboards/treadstone48)

Make example for this keyboard (after setting up your build environment):

    make treadstone48:default

See the [build environment setup](https://docs.qmk.fm/#/getting_started_build_tools) and the [make instructions](https://docs.qmk.fm/#/getting_started_make_guide) for more information. Brand new to QMK? Start with our [Complete Newbs Guide](https://docs.qmk.fm/#/newbs).

## Soldering of Diodes

Steps.  

 - Lead Forming
 - Insert in the through hole (Be careful of the direction of the diode)
 - Soldering

  
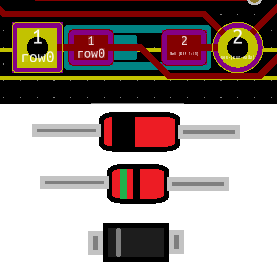
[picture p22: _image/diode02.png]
  

## Insert key switches to Mount Plate

The parts of the picture can be installed according to your preference.  

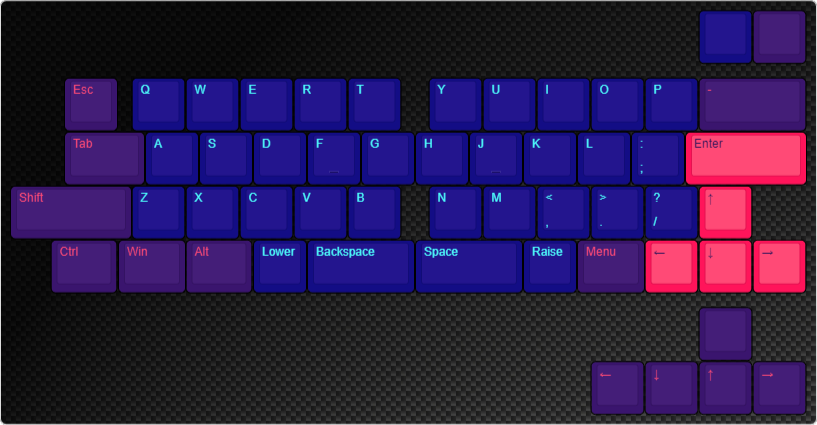
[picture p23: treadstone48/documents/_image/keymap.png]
  
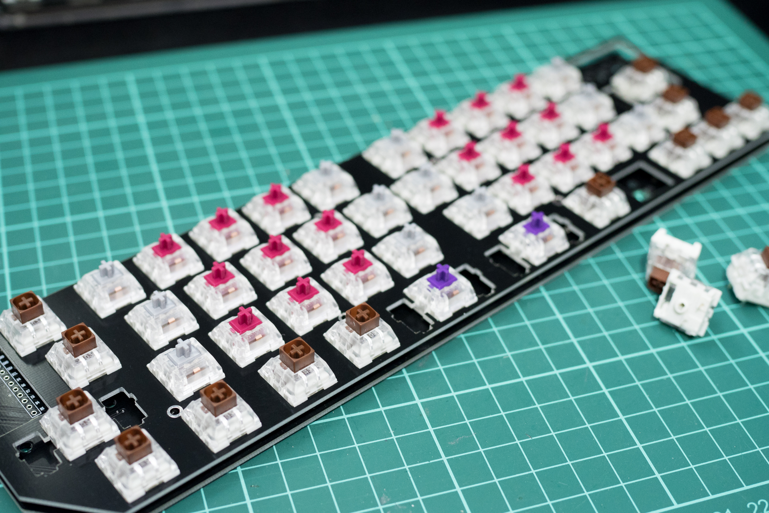
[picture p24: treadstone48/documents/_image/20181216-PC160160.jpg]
  
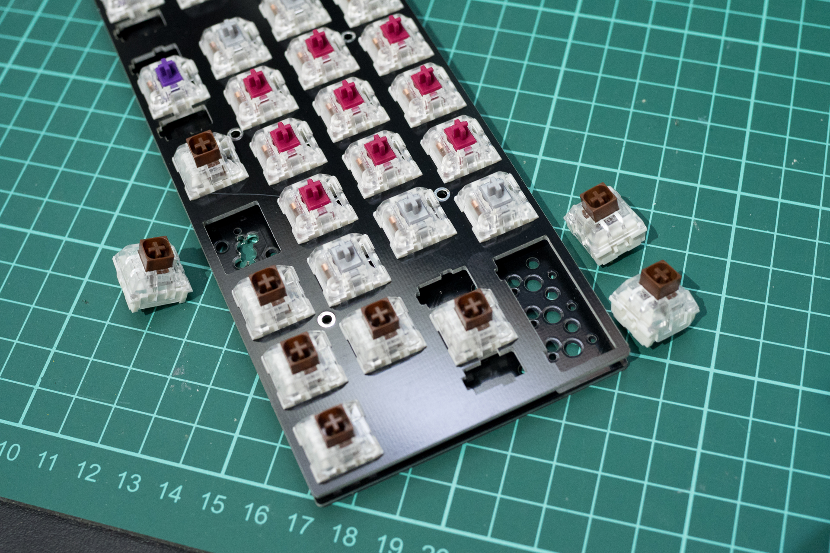
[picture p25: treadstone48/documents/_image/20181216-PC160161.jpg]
  

## Soldering of Sockets

 A first, Combine the PCB and the mounting plate.  
 And then Insert the socket into the pin of the switch protruding from the PCB. (be careful with the orientation)  
 Solder the terminal and PCB of both ends of the socket.  

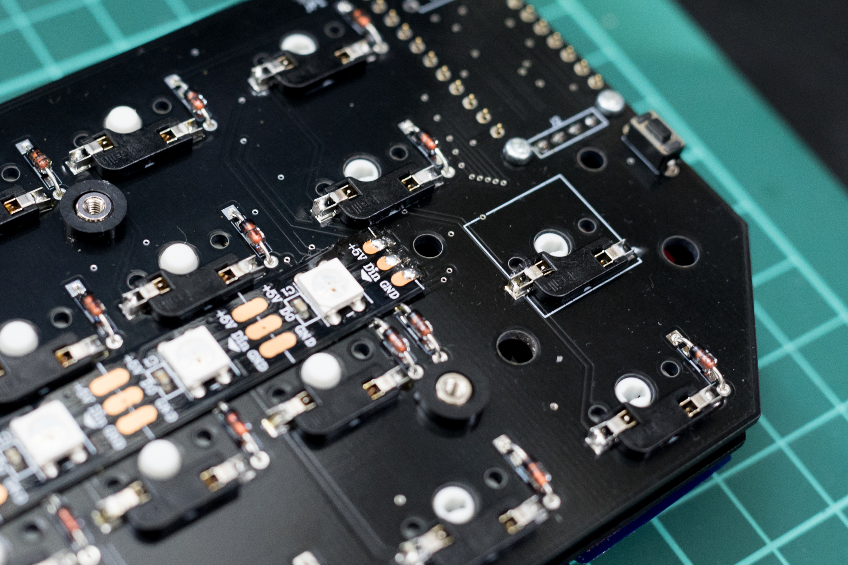
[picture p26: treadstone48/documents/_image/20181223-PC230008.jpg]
  

### Soldering of Pro micro

　Be careful with the orientation.  

  
  

### Soldering of Reset Switch

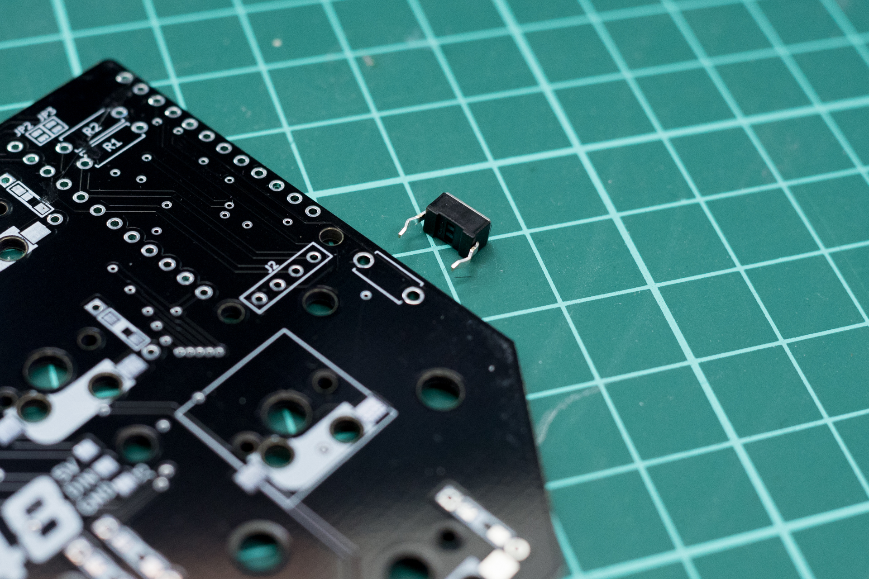
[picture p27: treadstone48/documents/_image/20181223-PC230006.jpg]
  

### SOldering of LED Strip

　Be careful with the orientation.  

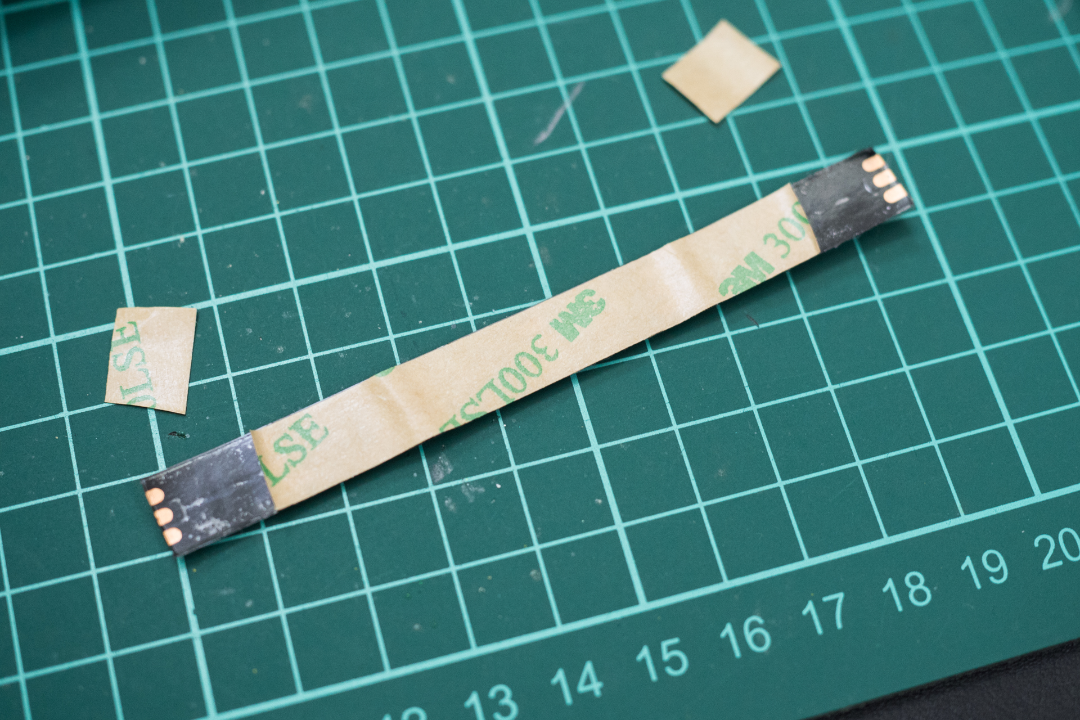
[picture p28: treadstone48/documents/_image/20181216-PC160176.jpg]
  
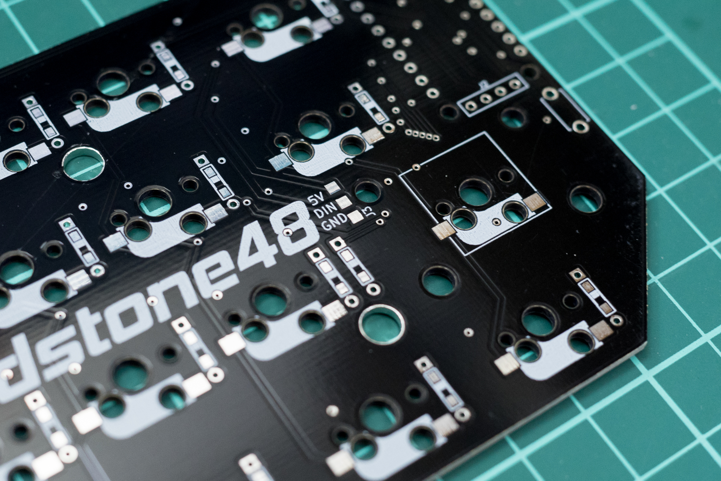
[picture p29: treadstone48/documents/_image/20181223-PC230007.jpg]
  
  

## Attach the Acrylic Cover

Use an 8 mm spacer, 2 4 mm screws and 2 4 mm black screws. Attach the cover to the PCB.

## Install Acrylic Bottom Plate

　Use 8 spacers of 7 mm, 8 spacers of plastic and 16 screws of 4 mm. Remove the bottom plate protective paper and attach the PCB.

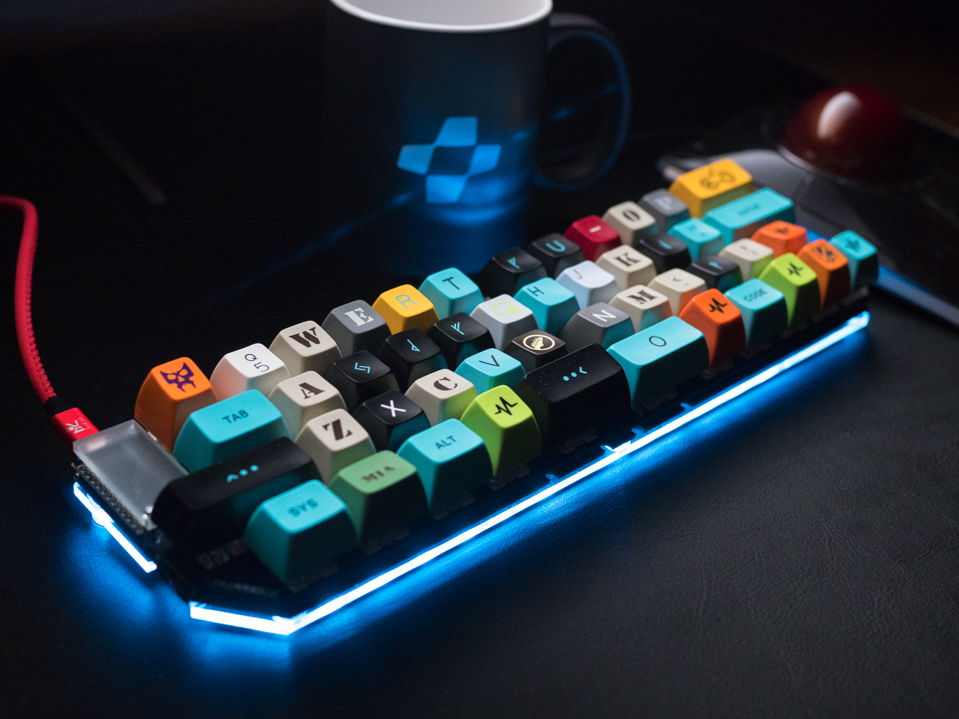
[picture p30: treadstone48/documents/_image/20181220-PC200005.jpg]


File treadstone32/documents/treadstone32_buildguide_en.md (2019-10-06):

# Treadstone32 Build Guide

## List of parts

### Parts included when buying the TS48 kit

Small surface mount components are include spares.  

| Name | Quantity | Note |
| ---- | ---- | --- |
| PCB | 1 | |
| Mount Plate | 1 | FR4(PCB plate) |
| Acrylic Bottom Plate | 1 | 2mm Frost |
| Acrylic Middle Layer | 1set | 2mm Frost |
| Acrylic Middle Layer | 1set | 5mm Mat Black |
| Acrylic Top Cover | 1 | 5mm Mat Black |

| Name | Quantity | Note |
| ---- | ---- | --- |
| Screw | 6 | M2 8mm |
| Screw | 6 | M2 4mm |
| Spacer | 6 | M2 7mm |
| Rubber Feet | 5 | |

| Name | Quantity | Note |
| ---- | ---- | --- |
| C1 | 2 | Capacitor 0.1uF 1206size (In Plastic case) |
| C2-C3 | 3 | Capacitor 1uF 1206size  |
| C4-C5 | 3 | Capacitor 22pF 1206size (Thin height) |
| R1-R2 | 3 | Resister 22ohm 1206size (22R0) |
| R3-R4 | 3 | 10Kohm 1206size (1002) |
| F1 | 1 | Fuse 500mA 0805size ("4" is written on the body) |
| X1 | 1 | Crystal FA-238 16MHz ("1600" is written on the body) |
| U1 | 1 | MCU atmel ATMEGA32U4-AU |
| J1 | 1 | micro USB Connector |
| (D1-D32) | 33 | 1N4148 SOD-123 |
| (SW1-SW32) | 32 | Kailh MX Socket |
| Reset1 | 1 | ResetSw |

### Please purchase separately (not included)

| 名前 | 数 | 備考 |
| ---- | ---- | --- |
| Key Switches | 32 | Compatible for MX |
| Key Caps | 32 | compatible for MX stem, Better than ANSI104 keysets |
| MicroUSB cable | 1 | |
| *LED strip（WS2812B x6）* | *1* | *Underglow* |

### Firmware

[Treastone32 QMK Directory](https://github.com/qmk/qmk_firmware/tree/master/keyboards/treadstone32)

Make example for this keyboard (after setting up your build environment):

    make treadstone32:default

See the [build environment setup](https://docs.qmk.fm/#/getting_started_build_tools) and the [make instructions](https://docs.qmk.fm/#/getting_started_make_guide) for more information. Brand new to QMK? Start with our [Complete Newbs Guide](https://docs.qmk.fm/#/newbs).

## Soldering of micro USB connector

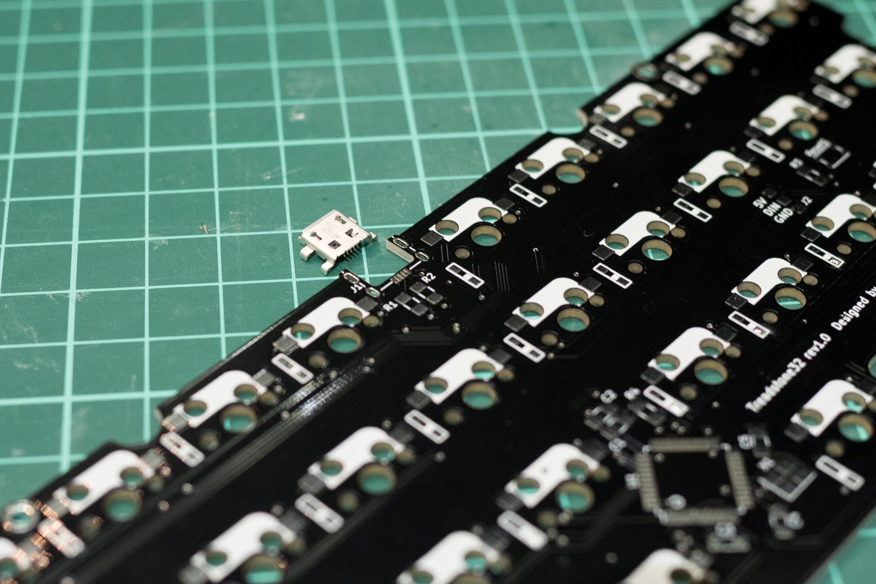
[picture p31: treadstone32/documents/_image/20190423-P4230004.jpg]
  

## Soldering of atmega32u4

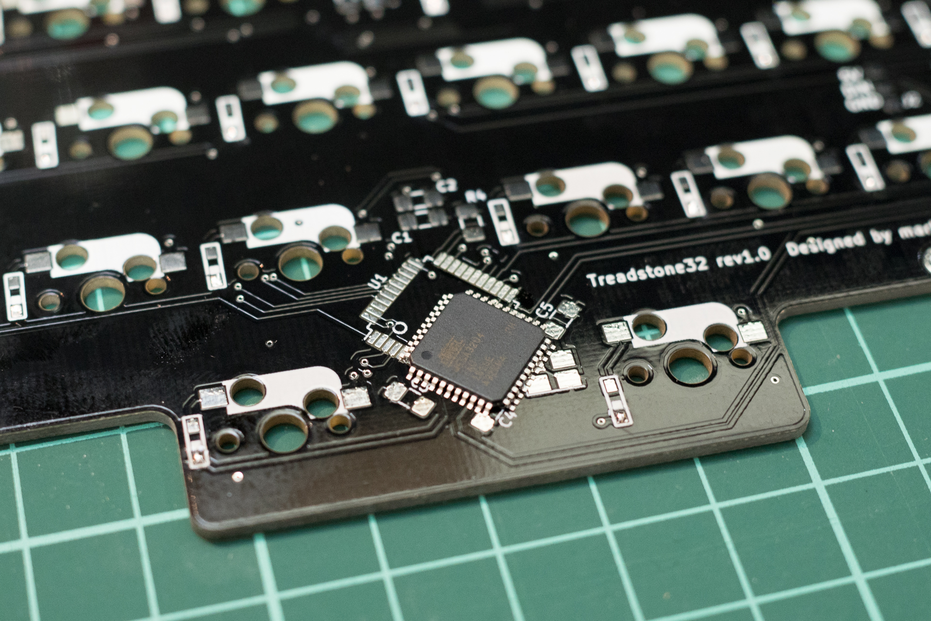
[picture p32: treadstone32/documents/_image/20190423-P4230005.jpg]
  

## Soldering of Crystal

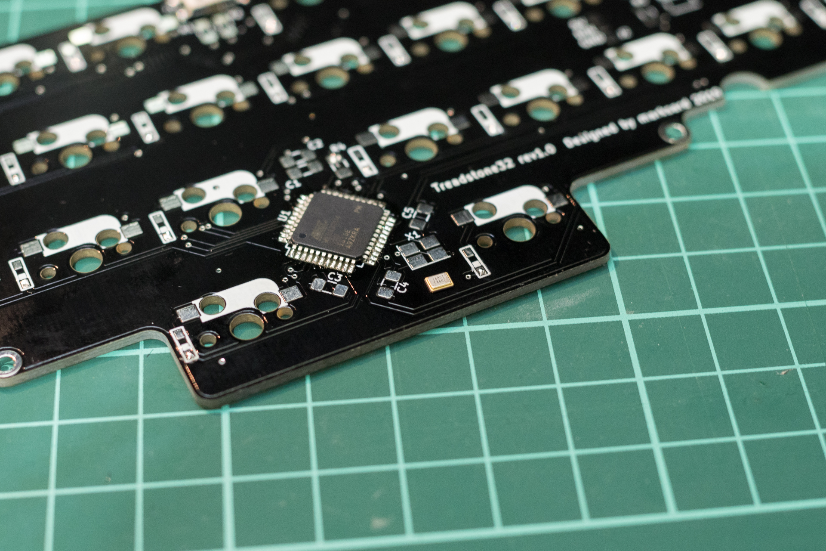
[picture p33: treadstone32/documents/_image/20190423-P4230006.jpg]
  

## Soldering of Capacitor

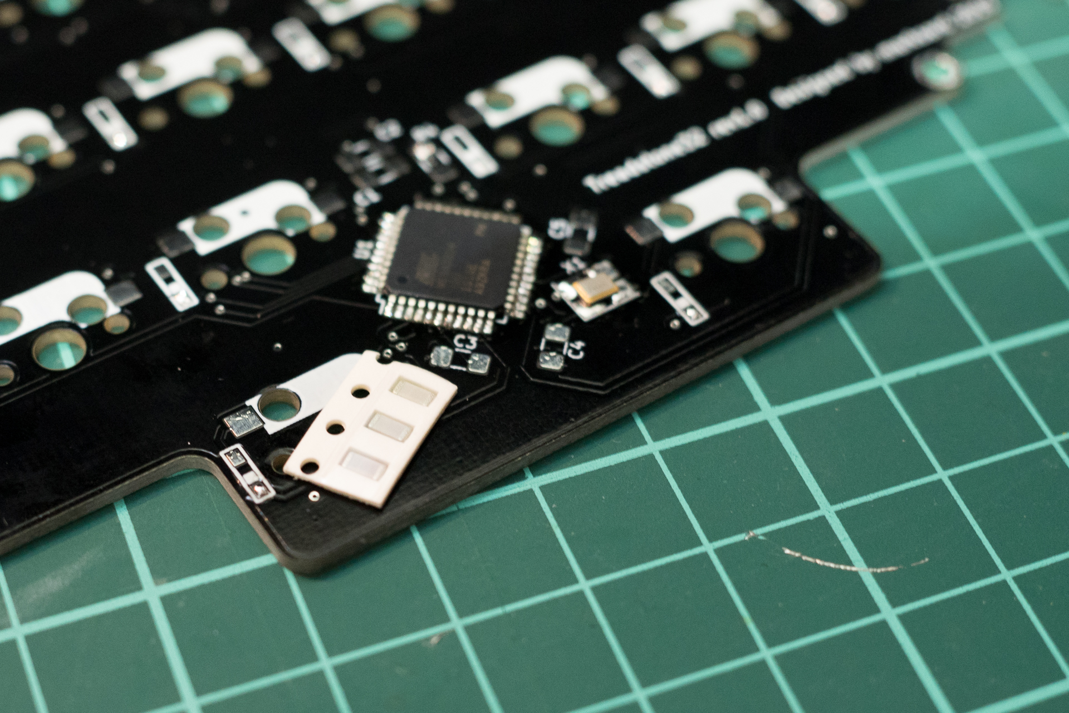
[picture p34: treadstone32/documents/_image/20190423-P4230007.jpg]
  

## Soldering of Resister

## Soldering of Reset Button

## Soldering of Fuse

## Soldering of Diode

## Soldering of MX Socket

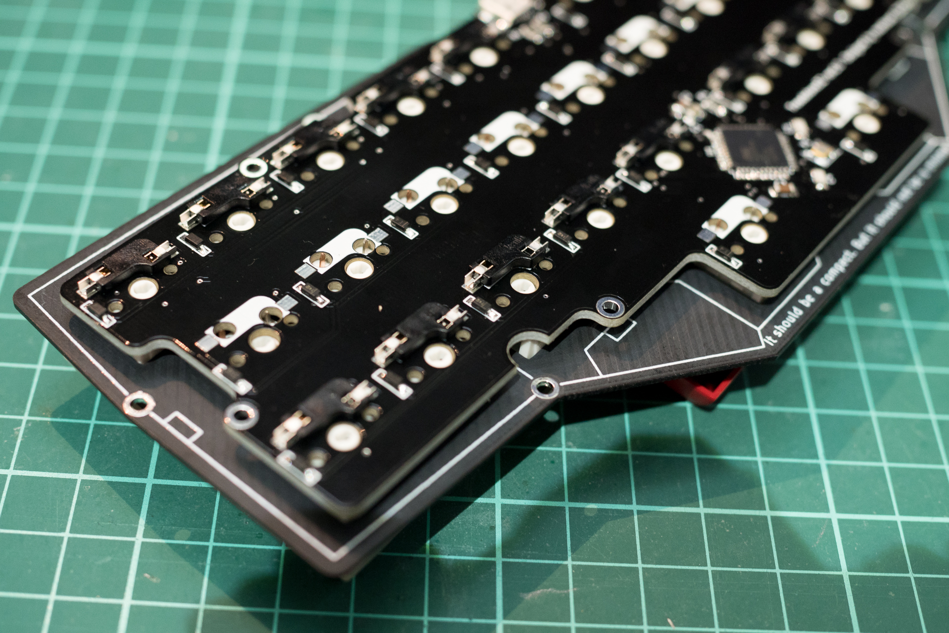
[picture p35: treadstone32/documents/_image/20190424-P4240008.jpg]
  
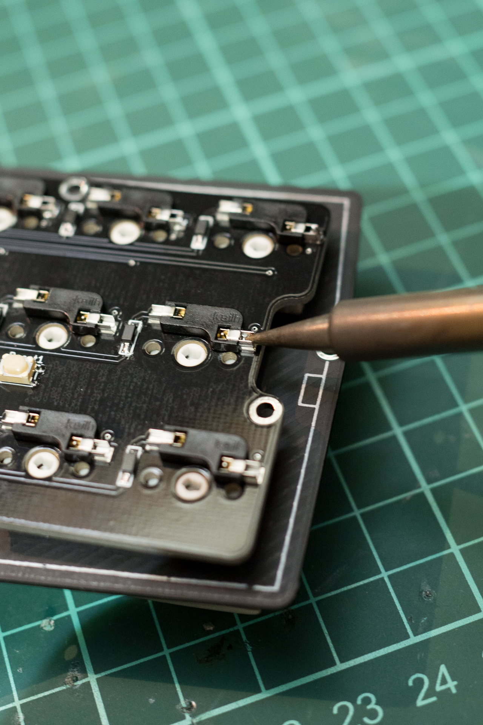
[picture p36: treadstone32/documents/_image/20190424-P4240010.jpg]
  
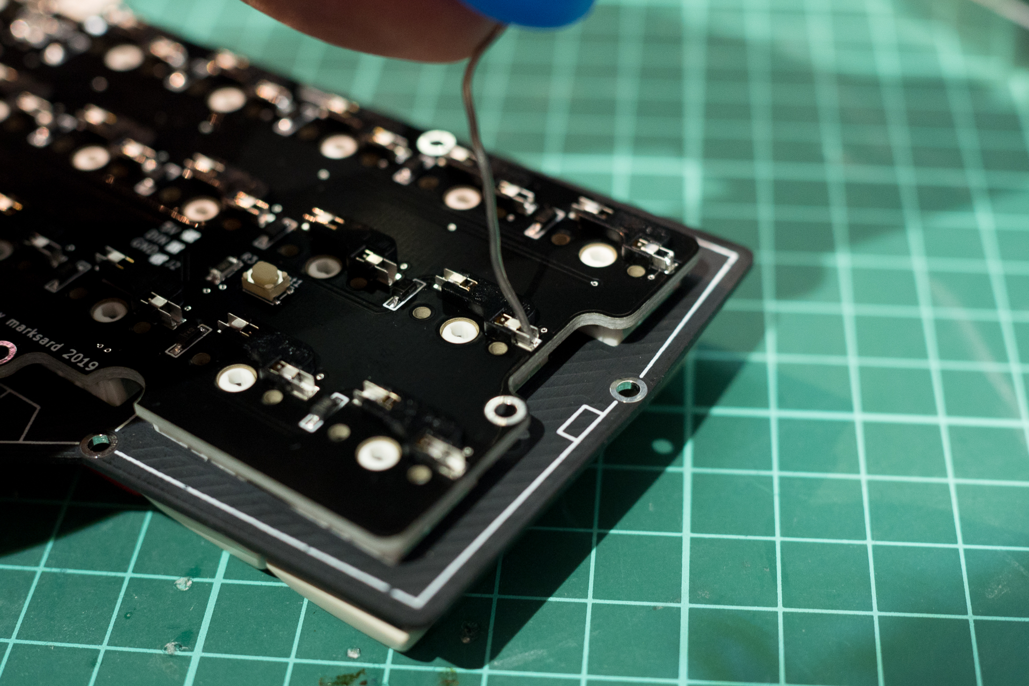
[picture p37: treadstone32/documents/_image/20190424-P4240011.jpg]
  

## Confirm of ATm32U4DFU in PC

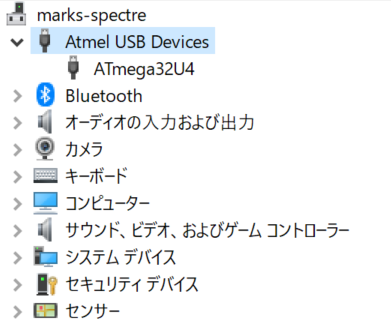
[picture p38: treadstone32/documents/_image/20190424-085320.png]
  
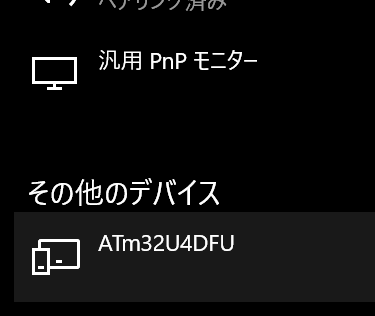
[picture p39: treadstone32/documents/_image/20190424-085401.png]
  

## *Soldering of UnderglowLED*

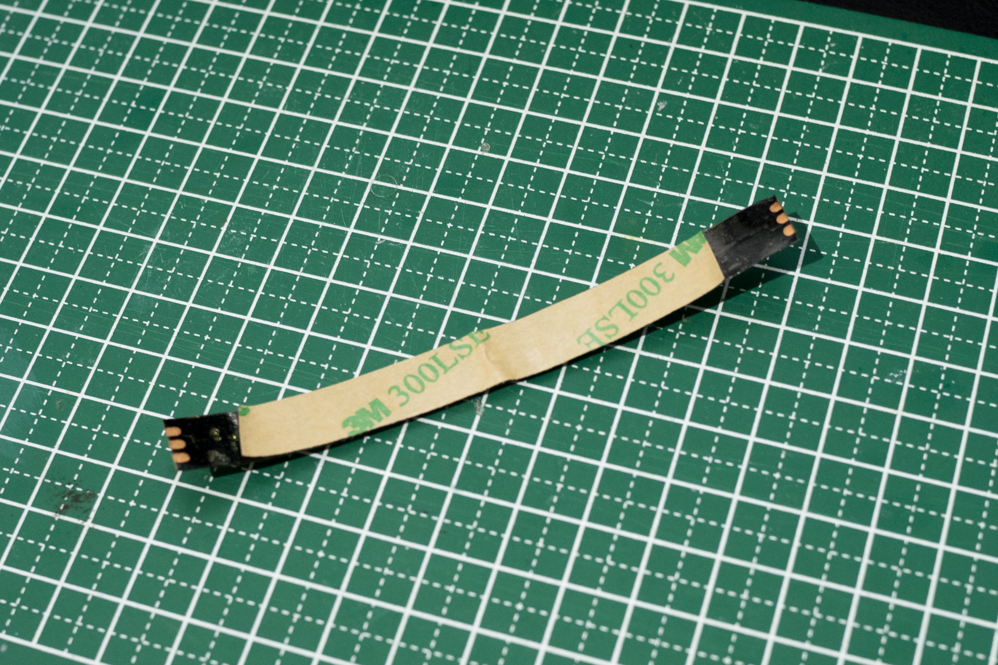
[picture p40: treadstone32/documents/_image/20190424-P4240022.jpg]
  
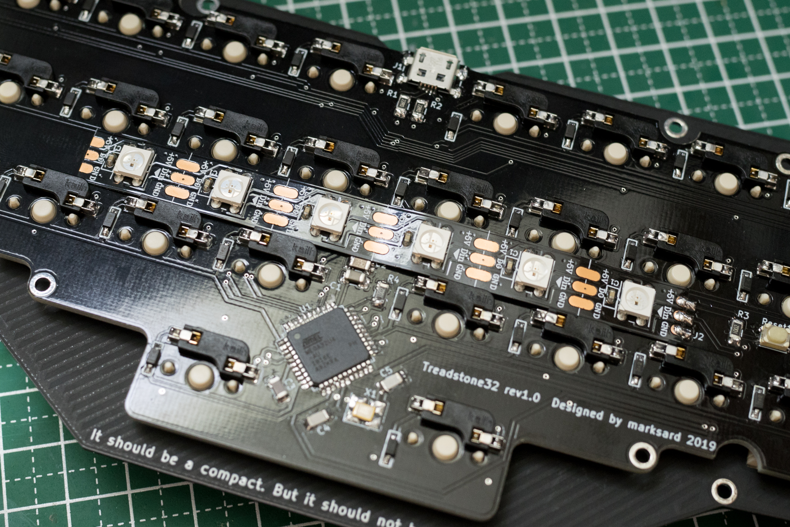
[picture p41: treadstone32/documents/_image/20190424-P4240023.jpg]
  

## Build of case

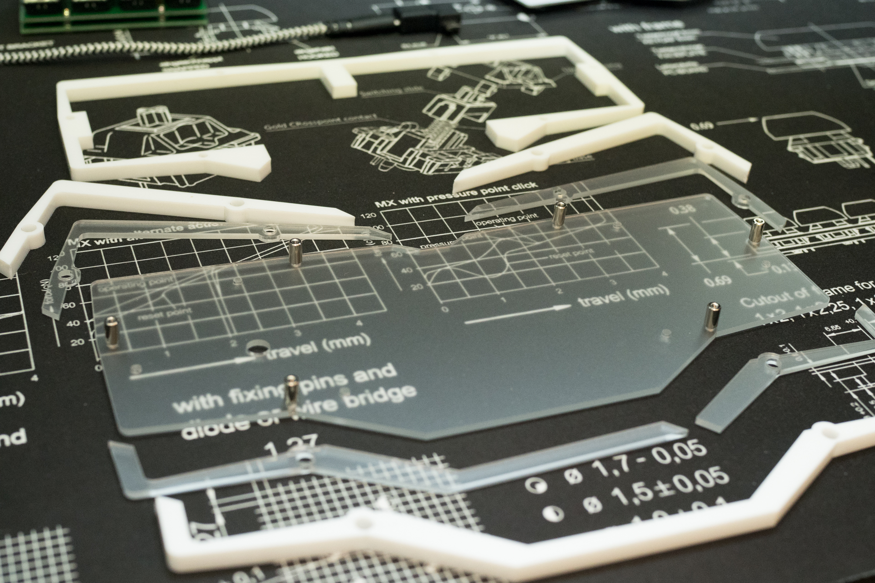
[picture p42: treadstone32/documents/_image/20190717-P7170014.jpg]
  
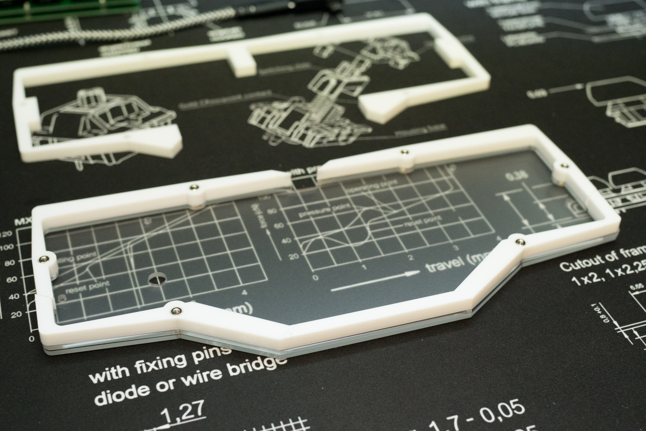
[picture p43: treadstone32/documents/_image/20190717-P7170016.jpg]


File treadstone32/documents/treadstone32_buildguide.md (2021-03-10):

# Treadstone32ビルドガイド

## はじめに

　Treadstone32はすべてチップ部品を使っており、ピッチの細かい部品のはんだ付けがあるため自作キーボードの中でも難易度は高いです。まず使用する道具はちゃんとそろえてくださいますようお願いいたします。  
　また特にmicroUSBのピンとMCUのピンはピッチが狭いため、慣れないとハンダで隣のピンをブリッジすることがあります。これを気づかずに電源を入れると最悪部品をを破損しますので重ねてご注意くださいますようお願いいたします。  

## キット付属品

| 基板番号 | 定数 | 数 | 名前 | 備考 |
| ---- | ---- | --- | --- | --- |
| C1 | 0.1uF | 2 | コンデンサ(1206size) | プラスチックのリールケースに入っていて1uFよりも色が薄く、一番厚みがある |
| C2-C3 | 1uF | 3 | コンデンサ(1206size) | 一番色が濃い |
| C4-C5 | 22pF | 3 | コンデンサ(1206size) | 一番色が薄く、厚みも薄い |
| R1-R2 | 22ohm | 3 | 抵抗(1206size) | 22R0と書いてある |
| R3-R4 | 10Kohm | 3 | 抵抗(1206size) | 1002と書いてある |
| F1 | 500mA | 1 | リセッタブルヒューズ(0805size) | 4て書いてるもの |
| X1 | 16MHz | 1 | 水晶振動子 EPSON FA-238 | 裏にパッドが4つあって、表に薄く1600とか書いてある |
| U1 | - | 1 | MCU atmel ATMEGA32U4-AU |  |
| J1 | - | 1 | micro USB MOLEX 47642-0001 |  |
| (D1-D32) | - | 33 | 1N4148 SOD-123 | うっすらとシルク印刷されている |
| (SW1-SW32) | - | 32 | Kailh MX ソケット |  |
| Reset1 | - | 1 | リセットスイッチ |  |
| - | M2 8mm | 6 | 低頭ネジ（黒または銀） |
| - | M2 4mm | 6 | 低頭ネジ（銀） |
| - | M2 スペーサー 7mm | 6 | 丸型 全ねじスペーサー |
| - | 2mm | 5 | ゴム脚 |  |
| - | - | 1 | PCB | 基板 |
| - | - | 1 | マウントプレート | スイッチをはめ込むプレート |
| - | - | 1式 | アクリルケースパーツ | </br>2mmボトムプレート</br>2mmボトムミドル</br>5mmボトムミドル</br>5mmトップカバー |

※以下はアーリーバード版に含まれるネジとボルトです

| 基板番号 | 定数 | 数 | 名前 | 備考 |
| ---- | ---- | --- | --- | --- |
| - | M2 1.6mm | 6 | ナット |  |
| - | M2 17mm- | 6 | ボルト |  |

## キット以外に必要なもの

| 名前 | 数 | 備考 |
| ---- | ---- | --- |
| キースイッチ | 32個 | MX互換のもの |
| キーキャップ | 32個 | MX互換のもの |
| MicroUSBケーブル | 1個 |  |

### オプション

オプションでイルミネーション用LEDを取り付け可能です。  

| 名前 | 数 | 備考 |
| ---- | ---- | --- |
| LEDストリップ（WS2812B 6個付き） | 1個 | Underglow用（オプション） |

## 必要な道具

| 名前 | 備考 |
| ---- | ---- |
| 温調はんだごて | チップ部品は熱に弱いので温調はんだごてが必須です |
| 細めのこて先 | C型やD型で2φ以下のものを推奨。慣れている人ならなんでも |
| 糸ハンダ | 半田ブリッジを低減するため0.5mm程度の細いものを推奨します |
| フラックス | 必須です |
| フラックス除去剤 | フラックスを塗るのでそれの除去に使用します |
| ハンダ吸い取り線 | 失敗したとき、ハンダブリッジしたときに吸い取ります |
| ピンセット | 必須です |
| テスター | 接続確認、ブリッジしていないかの確認に必須です |
| キズミ、ルーペなど | MicroUSBやAtmega32U4のハンダブリッジを目視で確認する際に必要 |

## 組み立て

　組み立ての順序は出来れば難しいパーツから取り掛かります（最後に難しいパーツを取り付けて失敗したときの徒労感が半端ないので）。ただ最初からは厳しいと思いますので、素振りとしてダイオードを数個付けて身体と半田ごてを慣らしてからでも良いかと思います。  
　もし失敗してパーツや基板をダメにしてどうしようもない場合はBoothやTwitter、Discord等からご連絡ください。補修部品を販売いたします。  

## micro USBのはんだ付け

  

　写真の向きで取り付けてください。  
　ハンダ付けするピンのピッチがかなり狭く、屋根の内側にピンがあるため難易度は高めです。  
　ここがショートしているとPCのUSBポートやUSBハブにダメージが出るおそれがあるので、ルーペやキズミでの目視確認し、テスターでの検査の両方で隣のピンと導通していないことを確認してください。（回路の設計上、隣同士のピンが導通しているのははんだをミスしています）  
　もし隣のピンと半田ブリッジている場合は半田吸い取り線などで除去してください。  

## atmega32u4のはんだ付け

  

　写真の向きのように、atmega32u4のくぼんだ丸印と基板のシルクの丸印を同じ位置にします。  
　次にatmega32u4のピンが綺麗に載るように調整します。このとき、基板の銀色のパッドのどこか一辺にフラックスを軽く塗布しておくとちょっと吸いつくようになるので位置決めがしやすいと思います。  
　電源ピン回りがショートしているとPCのUSBポートやUSBハブにダメージが出るおそれがあるので、ルーペやキズミでの目視確認し、テスターでの検査の両方で隣のピンと導通していないことを確認してください。（回路の設計上、隣同士のピンは導通していないため、導通しているとハンダミスを疑ってください）  

　もし隣のピンとはんだブリッジている場合は半田吸い取り線などで除去してください。吸い取りにくい場合は、はんだを敢えて少し盛ってから一気に吸わせることで吸いやすくなる場合もあります。  

## 水晶振動子のはんだ付け

  

　水晶振動子の印刷と、基板のX1が双方正しく読める位置にあわせてハンダ付けしてください。  

## コンデンサのはんだ付け

  

　何も字が書いてなくて、グレーまたは茶色っぽい地味色なのがコンデンサです。  
　コンデンサはすべて積層セラミックで方向はありません。  

　22pFは色が薄く一番平たいものです。水晶振動子の両サイドC4,C5の二か所に取り付けます。  
　0.1uFはプラスチックケースに2個入っているものです。C1に取り付けます。
　残ったのは1uFです。C2,C3に取り付けます。  

## 抵抗のはんだ付け

　黒地に白で何か書いてあるのが抵抗です。これも方向はありません。  
　22R0(22Ω)はmicro USBの下にあるR1,R2に取り付けます。  
　1002(10kΩ)はリセットボタン付近とAtmega32U4付近にあるR3,R4に取り付けます。  

## リセットボタンのはんだ付け

　スイッチがReset1下の四角に収まる方向に取り付けてください。  

## リセッタブルヒューズのはんだ付け

　他と同様、方向はありません。F1に取り付けてください。  

## ダイオードのはんだ付け

　チップダイオードのシルクが薄く見えにくいですが、線が入っている方を基板の線が入っている方に向きを合わせて取り付けてください。  
　取り付け向きはすべて一定なので、一つ取り付けたら残りも同じ方向で取り付けていってください。  

  

## MXソケットのはんだ付け

　先にトッププレートにスイッチをすべてはめこみます。つぎにトッププレートとPCBを合わせます。スイッチ裏の中央の出っ張りをPCBの穴に合わせて取り付けてください。  
　MXソケットをPCBのシルクの白いマークに合わせて取り付けます。スイッチのピンがMXソケットにちゃんと刺さっている事を確認しながらパチパチと全部付けてください。  
　こうすることでMXソケットが浮かずに確実にはんだ付け出来ます。  

  

　はんだごてを270℃程度に設定し、写真のようにMXソケットの端子に当てて3秒ほど温めます。  
  

　はんだを写真のように差し込んで、横から同じ温度ではんだごてを差し込んで、はんだを溶かします。はんだが基板とMXソケットの間にスーッと入ったらはんだごてを離します。

  

## ATm32U4DFUとして認識することを確認する

　ここまで出来たらもう一度、ルーペやキズミでの目視確認、テスターでの検査の両方で隣のピンと導通していないことmicroUSBとATMEGA32U4を対象によく確認してください。  
　確認出来たらPCとUSBケーブルで接続します。接続すると最初は(PCのOS問わず)ATm32U4という名前で認識します。  

windows10 デバイスマネージャでの表示  
  

windows10 設定→デバイス→Bluetoothとその他のデバイスでの表示  
  

　認識出来たらファームウェアを書き込むことが出来ます。  

　認識しない場合はどこかがハンダ不良で接続されていない可能性が高いです。以下を目視でチェックしてください。  

- 水晶振動子(X1)、コンデンサ(C1-C5)、抵抗(R1-R4)がキチンとはんだ付けされているか
- microUSBのピンがキチンとはんだ付けされているか
- ATMEGA32U4のピンがキチンとはんだ付けされているか

　付いていると思ってもいわゆるイモはんだっぽくなっていて接合されていないかもしれませんので、はんだを温めなおす、はんだを吸い取ってやり直してみてください。  

## *(オプション)UnderglowLEDをはんだ付けする*

　写真のようにテープLEDの剥離紙の両端数cmだけハサミなどでカットします。これはテープLEDの背面の端子と、キーボード基板のスルーホールなどの端子が接触して動作不良を起こすことを防ぐ意味合いがあります。  

  

　テープLEDは向きがありテープLEDの端子と基板の端子が合う向きにします。
  

### キーボード用ソフトウェアをatmega32u4に書き込む

　このキーボードはQMKというキーボード用のソフトウェアで動作します。お買い上げの時点ではこのソフトウェアが入っていない状態ですので、書き込む必要があります。  

1. [QMK Toolbox](https://github.com/qmk/qmk_toolbox/releases)をダウンロードし、インストールします
2. [marksard/qmk_firmware_hex](https://github.com/marksard/qmk_firmware_hex/releases)にある最新のhexファイルからtreadstone32_rev1_via.zipをダウンロード、zipを展開します
3. QMK Toolboxの「open」ボタンをクリックして、先程展開しhexファイルを選択します
4. QMK Toolboxの「Auto-Flash」チェックボックスにチェックを入れてpromicro(直付けの場合は基板)をPCに接続し、リセットボタンを押して書き込みます。
   1. （リセットボタンをダブルクリックしないと書き込めないパターン、初回のみリセットボタンを押下しなくても書き込みが始まるのものもあります）

書き込み方法などはサリチル酸さんの[（初心者編）自作キーボードにファームウェアを書き込む](https://salicylic-acid3.hatenablog.com/entry/qmk-toolbox)の記事が参考になります。  

#### REMAPを使用する

　上記で書き込んだファイルはVIA対応ファームウェアで、ファームウェアを書き直さなくてもアプリケーション上からキー設定を変更することが出来ます。  
　ここでは国産のVIA対応キーマップ変更アプリケーションとして、WEB上からキーボードの設定が出来る[REMAP](https://remap-keys.app/)を紹介します。  
対応したキーボードを接続した状態で、「START REMAP FOR YOUR KEYBOARD」→「+KEYBOARD」ボタンを押下するとキーボード名が出ます。それを押下することでカスタマイズ画面が出てきます。  

詳しい操作方法などについてはサリチル酸さんの[（初心者編）Remapを使ってキーマップを書き換えよう](https://salicylic-acid3.hatenablog.com/entry/remap-manual)の記事が参考になります。  

　この初期状態はUSキーボード（＋日本語JISキーボードのキー配置あり）mac向けとなっていますので、適宜変更する必要があります。  
Win/Mac切り替えは(Layer3キー + E位置のキーでmac向け、Layer3キー + R位置のキー)になっています。  
漢字/英字切り替えは(Layer1キー + B位置のキー)になっています。


#### ビルド環境を作成する

　現状、以下のようなカスタムはソースファイルからビルドする必要があります。  

- ロータリエンコーダーの動作のカスタマイズ
- タップと長押しの判定タイミングを調整する
- OLED表示の内容を変更

　ソースからビルドが出来るようになると他の多彩な機能を扱え、細かい動作まで自在にカスタムすることが出来ます。  

[QMK　ビルド環境を準備する](https://docs.qmk.fm/#/ja/newbs_getting_started)  

　treadstone32のデフォルトキーマップは  
```qmk compile -kb treadstone32 -km default```
で可能です。書き込む場合は
```qmk flash -kb treadstone32 -km default```  
とすると、コンパイルが完了次第書き込み待ちになるので、その状態で基板にあるリセットボタンをクリック、もしくはダブルクリックで書き込みが始まります。  

## 動作確認を行う

　あとはケースを組み立ててキーキャップをつけるだけですが、ケースを組み立てるのと分解するのが若干面倒なのと、MXソケットやダイオードがキチンと半田付けされているかの動作確認を済ませておくとケース組み立てが一回で済むので、この時点でキースイッチやオプションのLEDが動作することを確認してください。  

### 動作確認

　デフォルトキーマップの場合、Lower、Raise（左親指キー、右親指キー）の順で押下するとAdjustレイヤーになります。押下したまま、Aキーを押下するとLEDのON/OFFです。光らない場合はLEDの取り付け向きやはんだ箇所をチェックしてください。  

## キーキャップの取り付け

　ケースの組み立て時、トップレイヤーとキーキャップが干渉しないように取り付ける必要があるので、先にキーキャップをハメ込んでください。  

## ケースの組み立て

　ケースのパーツは2mm厚のものと、5mm厚のものがあります。  
　2mmボトムプレートと2mmボトムレイヤーを合わせてみて、ボトムレイヤーにスペーサーをはめ込む場所が6箇所あります。その位置にボトムプレートへM2 4mmのネジで取り付けてください。  

![img](_image/20190717-P7170014.jpg)  

以下の順番で乗せていきます。  

| 層名 | 厚み | 上 |
| --- | --- | --- |
| トップレイヤー | 5mm |  |
| マウントプレート(PCB付) | 1.2mm |  |
| ミドルレイヤー | 5mm |  |
| ボトムレイヤー | 2mm |  |
| ボトムプレート | 2mm | 下 |

![img](_image/20190717-P7170016.jpg)  

　全部乗せたら、トップレイヤーの位置をキーキャップに干渉しないように位置を合わせながらM2 8mmネジで6箇所留めてください。
　ゴム脚は四隅と、2つの親指キーの間手前に一つ貼ってください。  
　添付のゴム脚の厚みは1.6mmのものです。気になるようでしたら追加でゴム脚を貼ってみてください。  

## 完成

　チェックして問題なさそうなら完成です！あなただけの一台に仕上げてください！  

![img](_image/20190424-P4240024.jpg)  

## キースイッチの交換方法

　手では取り外しにくいため、amazonなどで販売されているキースイッチ引き抜き工具を使用して交換してください。

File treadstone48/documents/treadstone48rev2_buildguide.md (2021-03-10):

# Treadstone48 rev2 ビルドガイド

## パーツ一覧

## キット付属品

| 名前 | 数 | 備考 |
| ---- | ---- | --- |
| PCB | 1枚 | 基板 |
| マウントプレート | 1枚| スイッチをはめ込むプレート |
| ボトムプレート | 1枚| アクリル製 |
| OLED・ProMicro保護プレート | 1枚 | アクリル製 |
| M2スペーサー 8mm | 2個 | 基板・保護プレート接続用 |
| M2スペーサー 7mm | 8個 | トップ・ボトムプレート接続用 |
| M2ネジ 4mm| 20個 |  |
| ゴム足 | 8個 | 小8個 |
| ダイオード | 48個 | ロットにより1N4148（黒ライン）か1SS178（緑と黒のライン）どちらか |
| タクトスイッチ | 1個 | リセットスイッチ用 |

## キット以外に必要なもの

| 名前 | 数 | 備考 |
| ---- | ---- | --- |
| MicroUSBケーブル | 1本 | キーボードとPC接続用 |
| キースイッチ | 48個 | MX互換のもの |
| キーキャップ | 48個 | MX互換のもの |
| MXソケット | 48個 | MXスイッチ用ソケット |
| ProMicro | 1個 | |
| コンスルー（スプリングピンヘッダ） 12P | 2個 | 推奨 |
| スタビライザー | 5個 | PCBマウント用のもの。シフト、分割スペースx2、エンター、バックスペース用 |

### オプション

オプションでイルミネーション用LEDと情報表示用のOLEDが取り付け可能です。  

| 名前 | 数 | 備考 |
| ---- | ---- | --- |
| LEDストリップ（WS2812B 6個付き） | 2個 | Underglow用（オプション） |
| OLEDモジュール | 1個 | OLED用（オプション）取り付け高難易度のため非推奨 |
| ピンソケット 4P | 1個 | OLED用（オプション）取り付け高難易度のため非推奨<br/>2.54mmピッチ、ロープロファイル（低背）基板取り付け高さ3.5mm、1x4のもの<br/>秋月電子かヒロスギネットで購入可能 |
| ピンヘッダ 4P | 1個 | OLED用（オプション）取り付け高難易度のため非推奨 |

## 必要な道具

| 名前 | 備考 |
| ---- | ---- |
| はんだごて | |
| 糸ハンダ | 0.8mm程度のものを推奨します |
| ハンダ吸い取り線 | 失敗したとき用 |
| ニッパー | ダイオードのリード線などの切断用です |
| ピンセット | ProMicroリセットしたりチップLEDのはんだづけで使用します |
| フラックス除去剤 | 必須ではありませんがはんだ付け後のベタつきを除去出来、はんだによる黄色い変色も拭き取れてキレイな仕上がりになります |
| マスキングテープ | しるし付け、仮固定に使用。100均の柄付きでもOK |

　mteiさんの[Helix キーボードキットの製作に必要な工具メモ](https://gist.github.com/mtei/6957107a676ddfa85bde0ae41f8fa849)
やhdbxさんの[自作キーボードを始めるにあたって用意すべきツール](https://hdbx.hateblo.jp/entry/2018/06/01/215401)も参考になります。  

  
  

## promicroの準備

　promicroのコネクタ補強、コンスルーピンのはんだ付けを行ってください。  
　promicroは実装されている面がキーボード基板に向くようにコンスルーを取り付けてください。  
 - promicroのコネクタ補強：[ProMicroのモゲ防止ついでにQMK_Firmwareを書き込む](https://qiita.com/hdbx/items/2f3e4ddfcadda2a5578e)
 - コンスルーピンのはんだ付け：[Helixベータ ビルドガイド](https://github.com/MakotoKurauchi/helix/blob/master/Doc/buildguide_jp.md)

  
  

### キーボード用ソフトウェアをpromicroに書き込む

　このキーボードはQMKというキーボード用のソフトウェアで動作します。お買い上げの時点ではこのソフトウェアが入っていない状態ですので、書き込む必要があります。  

1. [QMK Toolbox](https://github.com/qmk/qmk_toolbox/releases)をダウンロードし、インストールします
2. [marksard/qmk_firmware_hex](https://github.com/marksard/qmk_firmware_hex/releases)にある最新のhexファイルからtreadstone48_rev2_via.zipをダウンロード、zipを展開します
3. QMK Toolboxの「open」ボタンをクリックして、先程展開しhexファイルを選択します
4. QMK Toolboxの「Auto-Flash」チェックボックスにチェックを入れてpromicro(直付けの場合は基板)をPCに接続し、リセットボタンを押して書き込みます。
   1. （リセットボタンをダブルクリックしないと書き込めないパターン、初回のみリセットボタンを押下しなくても書き込みが始まるのものもあります）

書き込み方法などはサリチル酸さんの[（初心者編）自作キーボードにファームウェアを書き込む](https://salicylic-acid3.hatenablog.com/entry/qmk-toolbox)の記事が参考になります。  

#### REMAPを使用する

　上記で書き込んだファイルはVIA対応ファームウェアで、ファームウェアを書き直さなくてもアプリケーション上からキー設定を変更することが出来ます。  
　ここでは国産のVIA対応キーマップ変更アプリケーションとして、WEB上からキーボードの設定が出来る[REMAP](https://remap-keys.app/)を紹介します。  
対応したキーボードを接続した状態で、「START REMAP FOR YOUR KEYBOARD」→「+KEYBOARD」ボタンを押下するとキーボード名が出ます。それを押下することでカスタマイズ画面が出てきます。  

詳しい操作方法などについてはサリチル酸さんの[（初心者編）Remapを使ってキーマップを書き換えよう](https://salicylic-acid3.hatenablog.com/entry/remap-manual)の記事が参考になります。  

　この初期状態はUSキーボード（＋日本語JISキーボードのキー配置あり）mac向けとなっていますので、適宜変更する必要があります。  
Win/Mac切り替えは(Layer3キー + E位置のキーでmac向け、Layer3キー + R位置のキー)になっています。  
漢字/英字切り替えは(Layer1キー + B位置のキー)になっています。
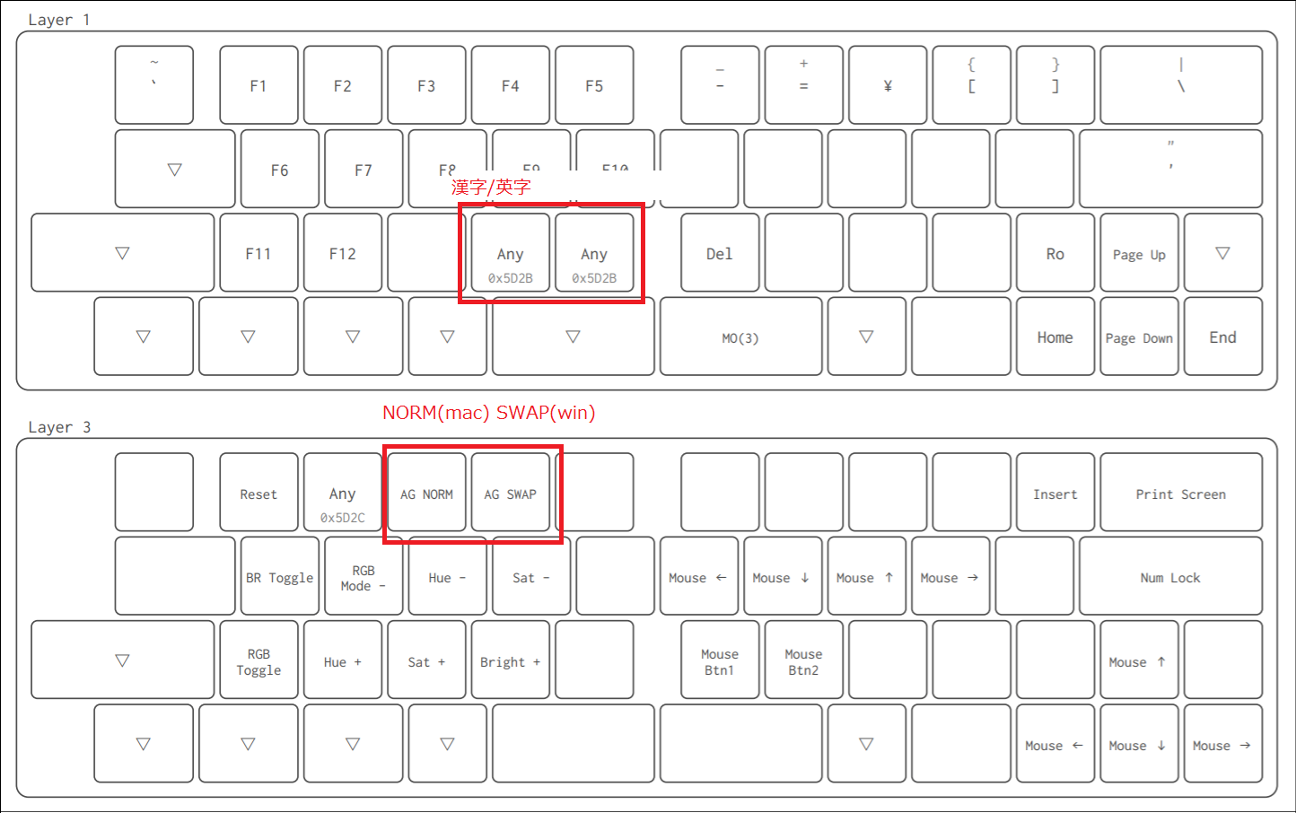
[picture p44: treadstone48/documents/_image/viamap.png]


#### ビルド環境を作成する

　現状、以下のようなカスタムはソースファイルからビルドする必要があります。  

- ロータリエンコーダーの動作のカスタマイズ
- タップと長押しの判定タイミングを調整する
- OLED表示の内容を変更

　ソースからビルドが出来るようになると他の多彩な機能を扱え、細かい動作まで自在にカスタムすることが出来ます。  

[QMK　ビルド環境を準備する](https://docs.qmk.fm/#/ja/newbs_getting_started)  

　treadstone48のデフォルトキーマップは  
```qmk compile -kb treadstone48/rev2 -km default```
で可能です。書き込む場合は
```qmk flash -kb treadstone48/rev2 -km default```  
とすると、コンパイルが完了次第書き込み待ちになるので、その状態で基板にあるリセットボタンをクリック、もしくはダブルクリックで書き込みが始まります。  

## 基板の裏と表について

　キースイッチが乗り、通常使用する際上を向く面を表、逆を裏とします。  
　Treadstone48は基板中心付近に横長に四角くシルクが刷られているほうが裏面です。  

## ダイオードをはんだ付けする

### ダイオードの脚を曲げる

　基板に付ける前にダイオードの脚を全部曲げてしまいます。基板の穴の間隔を見極めて曲げるための冶具を探してみてください。繋がったままの割りばしなどでも良いと思います。  

![img](../../_image/diode01.jpg)  

### ダイオードのはんだ付け

　ダイオードの取り付け向きは同じ方向なので、一つ確認して取り付けたら残りはすべて同じ方向で取り付けられます。ダイオードの黒や緑の帯側を基板のダイオード取り付け穴の四角いほうに向けて取り付けてください。  

![img](../../_image/diode02.png)  

　基板のウラ面からダイオードを差し込んでいきます。差し込んだらダイオードの足同士をネジって仮留めします。横一列ずつ差し込んでまとめてハンダ付けするとラクに速く出来ます。ハンダ付けしたら足を根元からカットしてください。  

## リセットスイッチをはんだ付けする

　リセットスイッチをウラ面に取り付けます。パチッとはめ込んで裏返してはんだ付けします。  

![img](_image/20200426-P1010005.jpg)  

## スタビライザーの取り付け

　スタビライザーを写真の向きに取り付けてください。  
※写真はバンドエイドMODというスタビ下面にテーピングを貼るカスタムをしています。  

![img](_image/20200508-P5080006.jpg)  

## MXソケットをはんだ付けする

　先にトッププレートにスイッチをすべてはめこみます。つぎにトッププレートとPCBを合わせます。スイッチ裏の中央の出っ張りをPCBの穴に合わせて取り付けてください。  
　MXソケットをPCBのシルクの白いマークに合わせて取り付けます。スイッチのピンがMXソケットにちゃんと刺さっている事を確認しながらパチパチと全部付けてください。  
　こうすることでMXソケットが浮かずに確実にはんだ付け出来ます。  

![img](_image/20200508-P5080004.jpg)  

　さいごにハンダ付けです。MXソケットを取り付けるとスイッチの交換は可能になりますが、ソケットと基板の保持をハンダに頼っているため交換後スイッチが効かないなどのハンダ不良が発生する可能性があります。ただ厚く盛っても意味がないので、基板のパッドとソケットの間にしっかりハンダを流します。  
　コツは、ソケットの脚と基板の境目にコテを3～5秒程度あてて温めて、半田を上部からMXソケットの脚に開いているスリットに押し当てて溶かします。そうすると溶けたハンダがスリットから基板のパッドに流れます。溶けたなと思ったらハンダごてと半田をはなして1～3秒程度で固着します。良し悪しの目安はソケットのハンダ部分を側面から観て、基板のパッドとソケットが接合されていることです。  

## *(オプション)UnderglowLEDをはんだ付けする*

　テープLEDの剥離紙の両端数cmだけハサミなどでカットします。これはテープLEDの背面の端子と、キーボード基板のスルーホールなどの端子が接触して動作不良を起こすことを防ぐ意味合いがあります。  

![img](../../_image/led_tape.jpg)  

　テープLEDは向きがありテープLEDの端子と基板の端子が合う向きにします。
![img](_image/20200426-P1010006.jpg)  
![img](_image/20200426-P1010007.jpg)  

　ProMicroに近い一枚目はテープLED両端をはんだ付けする必要があるので、基板の両端のランドに少し被るくらいの位置にテープLEDを貼り付けてはんだ付けしてください。  

![img](_image/20200426-P1010010.jpg)  

　二枚目は片側だけですが、同じように向きに注意して貼り付けてはんだ付けしてください。  

## *(オプション)OLED用のピンソケット・ピンヘッダをはんだ付けする*

　オモテ面に取り付けます。ラクにまっすぐ取り付けるため、マスキングテープでまっすぐつくように仮押さえしてから裏返してはんだ付けします。  

![img](_image/20200426-P1010002.jpg)  

## *(オプション)OLEDの取り付け*

　Treadstone48ではProMicro取り付け部周辺に余裕がなく、OLEDの基板の一部をカットして取り付ける必要があります。  

### OLED基板のカット

　ProMicro直下に取り付けるスペーサーと、OLEDの基板が左右1mm x 3mmくらい干渉しますので、写真のようにカットしてください。左が加工後です。
![img](../../_image/oled01.jpg)  

　スペーサーをゆるく仮止めしつつ現物合わせで削り込んでいってください。  
![img](_image/20181223-PC230004.jpg)  

## 保護パネルの取り付け

　ProMicro周りの目隠しとOLEDを保護するためのプレートを取り付けます。8mmスペーサー2つをネジでProMicroの下にある穴に取り付けます。  
　プレートの保護紙を両方剥がして、ネジでPCBに付けたスペーサーに取り付けてください。  
　少し遊びがありますので、キーキャップを取り付けた時にキーキャップと干渉する場合は少しずらしてください。  

## スペーサーの取り付け

　ボトムプレートの彫刻の入ってるの保護紙を剥がします。彫刻の細かい部分の保護紙はピンセットなどで剥がします。剥がした方にゴム脚を取り付けてください。標準でチルトするように大きいものと小さいものが入っていますので、小さいほう４つを手前に、大きいほう４つを奥に貼り付けてください。  

　残りの保護紙も剥がして、**7mm**スペーサー8つとネジを8つ使ってボトムプレートにねじ止めしてください。次にPCBの付いたマウントプレートを載せてネジ留めしてください。  

![img](_image/20200426-P1010011.jpg)  

## キーキャップの取り付け

　お好みのキーキャップを取り付けてください。  

## テスト

　PCに接続して動作チェックしてください。[QMK Keytest](https://config.qmk.fm/#/test)やキーボードテスターアプリでキーが認識されているかチェックしてください。OLEDを取り付けている場合は、OLEDの四段目の表示がスイッチのステータスです。何かしら変化していればOKです。  

## 完成

　チェックして問題なさそうなら完成です！あなただけの一台に仕上げてください！

![img](_image/20200118-P1180017.jpg)  

## キースイッチの交換方法

　手では取り外しにくいため、amazonなどで販売されているキースイッチ引き抜き工具を使用して交換してください。  

## トラブルシューティング

[トラブルシューティング](../../troubleshooting.md)ページを参考にしてください。

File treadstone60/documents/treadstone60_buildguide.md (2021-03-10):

# Treadstone60 ビルドガイド(γ版)

## キット付属品

| 名前 | 数 | 備考 |
| ---- | ---- | --- |
| PCB | 1枚 | いわゆる基板です |
| トッププレート | 1枚 | スイッチを取り付ける穴があいてます |
| MXソケット | 59～62個 | MXスイッチ用ソケット |

## キット以外に必要なもの

| 名前 | 数 | 備考 |
| ---- | ---- | --- |
| 60%トレイケース | 1台 | GH60系の60%キーボードケース |
| キースイッチ | 59～62個 | MX互換のもの |
| キーキャップ | 59～62個 | MX互換のもの |
| USB-Cケーブル | 1本 |  |

　トレイケースについてはGH60系の60%キーボードケースに装着可能です。ただしHキーのMXソケットを加工する必要があります。設計者が動作確認したものはKBDFans TOFUアルミニウムケースです。詳しくは後述します。  
　ソケット、スイッチ、キャップについてはレイアウトの選択により変化します。詳しくは後述します。  

## 必要な道具

| 名前 | 備考 |
| ---- | ---- |
| はんだごて | |
| 糸ハンダ | 0.8mm程度のものを推奨します |
| ハンダ吸い取り線 | 失敗したとき用 |
| ピンセット | ダイオードをつまむときなどに使います |
| フラックス除去剤 | 必須ではありませんがはんだ付け後のベタつきを除去出来、はんだによる黄色い変色も拭き取れてキレイな仕上がりになります |

　mteiさんの[Helix キーボードキットの製作に必要な工具メモ](https://gist.github.com/mtei/6957107a676ddfa85bde0ae41f8fa849)
やhdbxさんの[自作キーボードを始めるにあたって用意すべきツール](https://hdbx.hateblo.jp/entry/2018/06/01/215401)も参考になります。  

  
  

### キーボード用ソフトウェアをatmega32u4に書き込む

　このキーボードはQMKというキーボード用のソフトウェアで動作します。お買い上げの時点ではこのソフトウェアが入っていない状態ですので、書き込む必要があります。  

1. [QMK Toolbox](https://github.com/qmk/qmk_toolbox/releases)をダウンロードし、インストールします
2. [marksard/qmk_firmware_hex](https://github.com/marksard/qmk_firmware_hex/releases)にある最新のhexファイルからtreadstone32_rev1_via.zipをダウンロード、zipを展開します
3. QMK Toolboxの「open」ボタンをクリックして、先程展開しhexファイルを選択します
4. QMK Toolboxの「Auto-Flash」チェックボックスにチェックを入れてpromicro(直付けの場合は基板)をPCに接続し、リセットボタンを押して書き込みます。
   1. （リセットボタンをダブルクリックしないと書き込めないパターン、初回のみリセットボタンを押下しなくても書き込みが始まるのものもあります）

書き込み方法などはサリチル酸さんの[（初心者編）自作キーボードにファームウェアを書き込む](https://salicylic-acid3.hatenablog.com/entry/qmk-toolbox)の記事が参考になります。  

#### REMAPを使用する

　上記で書き込んだファイルはVIA対応ファームウェアで、ファームウェアを書き直さなくてもアプリケーション上からキー設定を変更することが出来ます。  
　ここでは国産のVIA対応キーマップ変更アプリケーションとして、WEB上からキーボードの設定が出来る[REMAP](https://remap-keys.app/)を紹介します。  
対応したキーボードを接続した状態で、「START REMAP FOR YOUR KEYBOARD」→「+KEYBOARD」ボタンを押下するとキーボード名が出ます。それを押下することでカスタマイズ画面が出てきます。  

詳しい操作方法などについてはサリチル酸さんの[（初心者編）Remapを使ってキーマップを書き換えよう](https://salicylic-acid3.hatenablog.com/entry/remap-manual)の記事が参考になります。  

　この初期状態はUSキーボード（＋日本語JISキーボードのキー配置あり）mac向けとなっていますので、適宜変更する必要があります。  
Win/Mac切り替えは(Layer3キー + E位置のキーでmac向け、Layer3キー + R位置のキー)になっています。  
漢字/英字切り替えは(Layer1キー + B位置のキー)になっています。
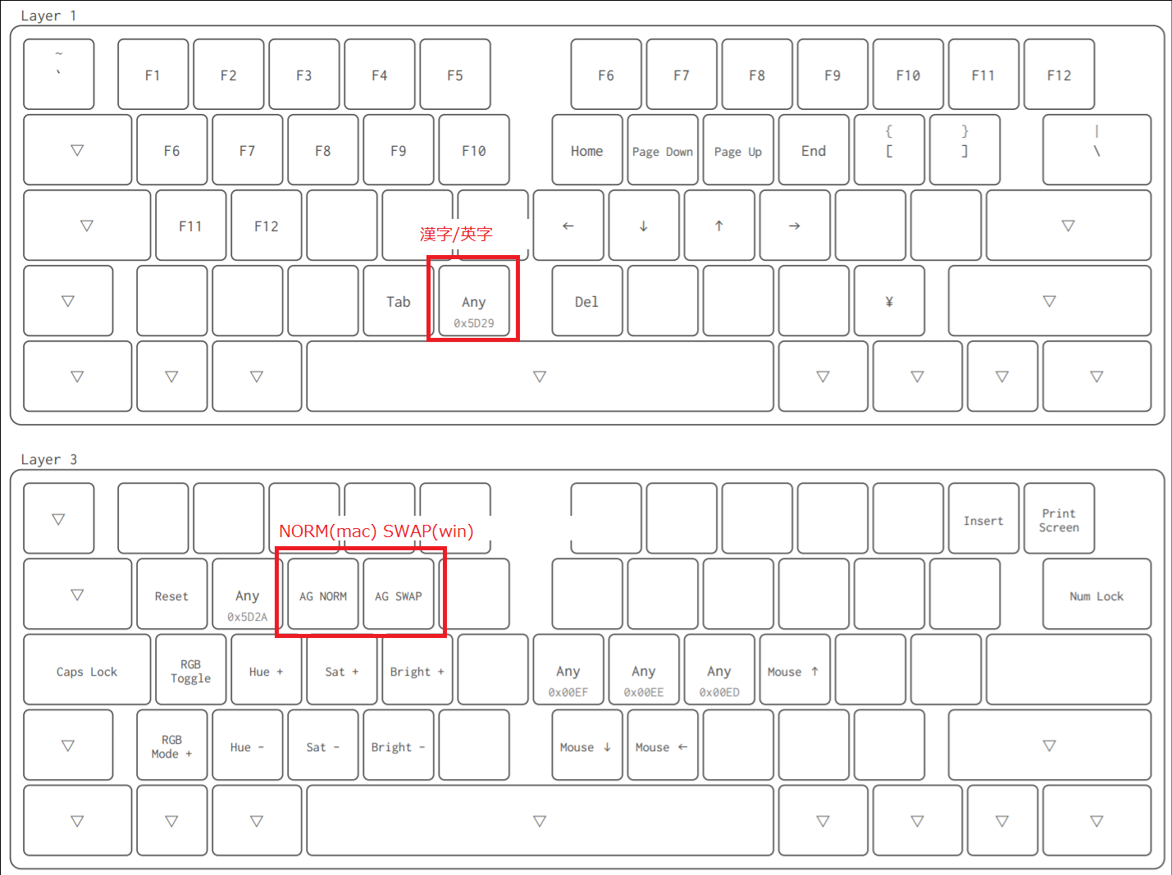
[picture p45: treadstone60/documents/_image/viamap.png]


#### ビルド環境を作成する

　現状、以下のようなカスタムはソースファイルからビルドする必要があります。  

- ロータリエンコーダーの動作のカスタマイズ
- タップと長押しの判定タイミングを調整する
- OLED表示の内容を変更

　ソースからビルドが出来るようになると他の多彩な機能を扱え、細かい動作まで自在にカスタムすることが出来ます。  

[QMK　ビルド環境を準備する](https://docs.qmk.fm/#/ja/newbs_getting_started)  

　treadstone60のデフォルトキーマップは  
```qmk compile -kb marksard/treadstone60 -km default```
で可能です。書き込む場合は
```qmk flash -kb marksard/treadstone60 -km default```  
とすると、コンパイルが完了次第書き込み待ちになるので、その状態で基板にあるリセットボタンをクリック、もしくはダブルクリックで書き込みが始まります。  

## 基板の裏と表について

　キースイッチが乗り、通常使用する際上を向く面を表、逆を裏とします。  
　Treadstone60の場合、名前とリビジョンが書かれた方が裏面となります。  

## レイアウトとキーキャップ

![img](_image/keymap.png)  

　γ基板ではいくつかのレイアウトを選択できます。

- CapsLock：SteppedかNormalかをどちらか選択可能（どちらもSocket対応）
- 右シフト：通常（Socket対応）分割右シフト(Socket未対応)を選択可能
- スペースバー：通常、スプリットスペースバーを選択可能（どちらもSocket対応）

　基本的にMXソケットに対応していますが、分割右シフトの場合は場所の都合上ソケットに対応していません。分割右シフトにする場合は基板にスイッチを直付けしてください。  
**1.25UのCtrlとWinキーのためのスイッチ穴がありますが、γ基板での配布分ではマウントプレートが対応していないため不可です。**  

　キーキャップで若干特殊なのが左シフトキーに使用する1.25Uキーです。  
　Ctrlが1.5U、Winが1U、Backspaceキーが1.5Uですので、ANSI104キーセットではカバー出来ません。60%に対応しているキーキャップセットを購入してください。  
　Shiftの刻印のある1.25Uキーが採用されているのはISOキーボードで、そのため販売されているキーセットによっては含まれていない可能性もありますのでよく確認してください。  
**刻印と打鍵したキーが多少一致しなくても良い、隙間が空いてもいい、という場合はこの限りではありません**

## スタビライザーを取り付ける

　2U以上のキーにはPCBマウントのスタビライザーを取り付けられる穴が空いていますので取り付けてください。  

## MXソケットをはんだ付けする

　レイアウトが決まったら、トッププレートとPCBを重ね合わせて、スイッチの取り付け向きを確認します。Escと数字の1キー、CapslockのNormal位置、スペースバーなどが他のキーと違って逆向きになっています。注意しながら取り付けてください。  
　次にPCBをスイッチを取り付けたマウントプレートとスイッチの向きがあっているかどうか注意深く観ながら合わせます。スイッチ裏の中央の出っ張りをPCBの穴に合わせて取り付けてください。  
　MXソケットをPCBのシルクの白いマークに合わせて取り付けます。スイッチのピンがMXソケットにちゃんと刺さっている事を確認しながらパチパチと全部付けてください。  
　こうすることでMXソケットが浮かずに確実にはんだ付け出来ます。  
　ハンダごてのこて先に気持ち多めにハンダを付けて、ソケットの金具の隙間に見えるPCBに付ける気持ちで、ソケットの隙間を少しこじ開ける感じで熱を与えながら流し込みます。  

## 分割右シフトキーの場合の注意点

MXソケット未対応ですので、基板にスイッチを直付けするか、mill-maxソケットなどを使って装着してください。また2.75UのKailhMXソケットと干渉する位置にあるため 1.75U + 1Uを選択する場合はkailh mxソケットを取り付けないでください。

![img](_image/right_shift.jpg)  

## ケースへの取り付けとHキーのソケット加工

　USB-Cのコネクタをさきにケースのコネクタ口に入れる感じでケースに置いてください。トレイケースには6個所のビス留め用の台座がありますが、Hキー位置のソケットのパーツと、トレイケースの脚が干渉するものがありますので、ケースに合わせて削ってください。  

![img](_image/hkey_socket1.jpg)  

試作なので穴形状が違いますが、ソケットのカットは以下も参考にしてみてください。

![img](_image/hkey_socket2.jpg)  

## キーキャップの取り付け

　お好みのキーキャップを取り付けてください。  

## テスト

　PCに接続して動作チェックしてください。[QMK Keytest](https://config.qmk.fm/#/test)やキーボードテスターアプリでキーが認識されているかチェックしてください。

## 完成！

　チェックして問題なさそうなら完成です！あなただけの一台に仕上げてください！

## キースイッチの交換方法

　手では取り外しにくいため、amazonなどで販売されているキースイッチ引き抜き工具を使用して交換してください。

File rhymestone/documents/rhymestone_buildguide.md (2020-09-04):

# Rhymestone ビルドガイド

## パーツ一覧

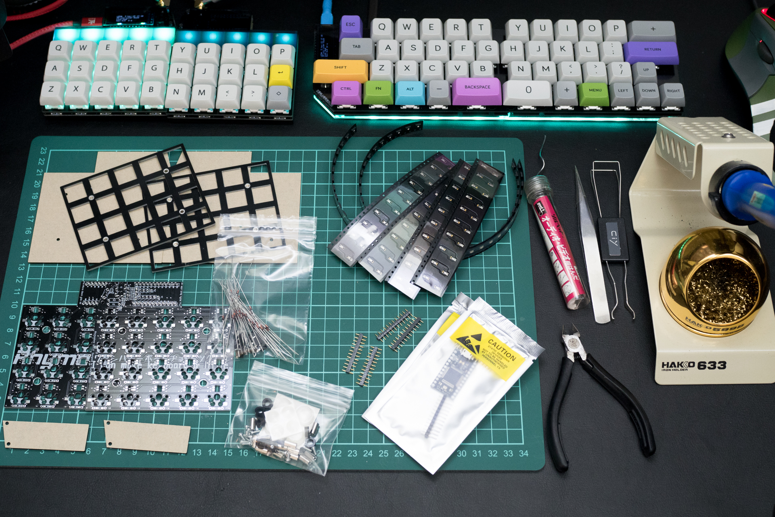
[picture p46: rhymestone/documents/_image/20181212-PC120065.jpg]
  

## キット付属品

| 名前 | 数 | 備考 |
| ---- | ---- | --- |
| PCB | 2枚 | |
| トッププレート | 2枚 | 四角い穴がいっぱい空いたほうです |
| ボトムプレート | 2枚 | ビス穴しかあいてないほう |
| OLED・Pro Micro保護プレート | 2枚 | |
| *30キーチャレンジ用OLED・Pro Micro保護プレート* | *2枚* | *オプション* |
| M2スペーサー 8mm | 12個 | |
| プラスペーサー 3mm | 8個 | M2スペーサーと組み合わせて使います |
| M2ネジ 5mm | 20個 | |
| M2黒皿ネジ 4mm| 4個 | 保護プレートに取り付けるネジです |
| ゴム足 | 8個 | 大小4個ずつ |
| ダイオード | 40個 |  |
| TRRSジャック | 2個 | |
| タクトスイッチ | 2個 | |

## キット以外に必要なもの

| 名前 | 数 | 備考 |
| ---- | ---- | --- |
| 3.5mmステレオケーブル(3極) | 1本 | キーボード間接続用 |
| MicroUSBケーブル | 1本 | キーボードとPC接続用 |
| キースイッチ | 40個 | MX互換のもの |
| キーキャップ | 40個 | MX互換のもの |
| Pro Micro | 2個 | |
| スプリングピンヘッダ 12P | 4個 | 交換や確認にも便利なので必須と言っていいくらい推奨 |
| MXソケット | 40個 | MXスイッチ用ソケット |
| *SK6812mini* | *40個* | *バックライト用（オプション）* |
| *OLEDモジュール* | *1～2個* | *OLED用（オプション）* |
| *ピンソケット 4P* | *1～2個* | *OLED用（オプション）* |
| *ピンヘッダ 4P* | *1～2個* | *OLED用（オプション）* |

### 補足

#### pro micro

　大抵ProMicro買うとピンヘッダが付属しているから買わなくてもいいやって考えがちですが、ちょっとお高いコンスル―用スプリングピンヘッダにすると

- キーボード基板の裏表間違ってはんだ付けしてしまった時のリカバリ
- もげマイクロ対策
- Pro Microの文鎮化(異常なデータを書いた時)の交換、復元対策
- Pro Microを再利用可能

など、メリットしかないので超オススメします。どうしても直付けしたい玄人さんでOLEDを取り付ける場合は先に「OLED取り付けのためのPCBのランドショート」の項を先に済ませておいてください。  

#### OLEDとOLED用ピンソケット

　OLEDは両手に付けることが出来ます。左手側に各種動作確認用のステータスを表示しますので、片側だけの購入でも十分機能します。  

　AliExpressや遊舎工房でOLEDだけ買った場合はピンソケットが無いので別途秋月電子かヒロスギネットなどで別途購入してください。色々種類があるのですが、ソケットは

- 2.54mmピッチ  
- ロープロファイル（低背）基板取り付け高さ3.5mm  
- ピンソケット  
- 1x4(4P)  

　のものが必要です。

#### SK6812mini

　バックライト用SK6812miniはハンダ熱に弱く温度調節機能付きのハンダごてでないと失敗が多く時間がかかり部品をダメにしてしまいます。中華製の温度調節機能付きのハンダごては安いのですが、モノによっては温度が正確でなく部品を壊す場合もありますので、可能な限りHAKKOなど日本のメーカーが出している温調ハンダごてを使ってください。またハンダのチップ（こて先）も標準で付いてくる鉛筆上のものではなく、斜めにカットされたタイプを別途購入するとめちゃくちゃ捗りますのでオススメです。  

## 必要な道具

| 名前 | 備考 |
| ---- | ---- |
| はんだごて | バックライトLEDを取り付ける場合は温度調整が出来るものが必須です<br/>(温度調整が出来ないとLED破損率がかなり高いです) |
| フラックス | バックライトLEDを取り付ける場合はあるとメッチャ捗るので必須です |
| 糸ハンダ | 0.8mm程度のものを推奨します |
| ハンダ吸い取り線 | 失敗したとき用 |
| ニッパー | ダイオードのリード線などの切断用です |
| ピンセット | ProMicroリセットしたりチップLEDのはんだづけで使用します |
| フラックス除去剤 | 必須ではありませんがはんだ付け後のベタつきを除去出来、はんだによる黄色い変色も拭き取れてキレイな仕上がりになります |
| マスキングテープ | しるし付け、仮固定に使用。100均の柄付きでもOK |

　mteiさんの[Helix キーボードキットの製作に必要な工具メモ](https://gist.github.com/mtei/6957107a676ddfa85bde0ae41f8fa849)
やhdbxさんの[自作キーボードを始めるにあたって用意すべきツール](https://hdbx.hateblo.jp/entry/2018/06/01/215401)も参考になります。  

  
  

## promicroの準備

　promicroのコネクタ補強、コンスルーピンのはんだ付けを行ってください。  
　promicroは実装されている面がキーボード基板に向くようにコンスルーを取り付けてください。  
 - promicroのコネクタ補強：[ProMicroのモゲ防止ついでにQMK_Firmwareを書き込む](https://qiita.com/hdbx/items/2f3e4ddfcadda2a5578e)
 - コンスルーピンのはんだ付け：[Helixベータ ビルドガイド](https://github.com/MakotoKurauchi/helix/blob/master/Doc/buildguide_jp.md)

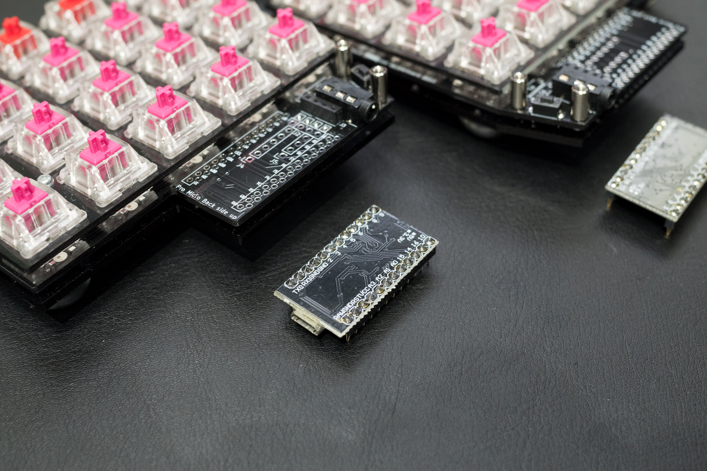
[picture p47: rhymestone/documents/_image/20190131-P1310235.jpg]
  

### QMKを準備する

　このキーボードはQMKというキーボード用のソフトウェアで動作するようにプログラミングしています。あらかじめ登録してあるdefaultキーマップは作者が実際に使用しているもので、ほぼ何不自由なく使えるように工夫しています。

1. 下記リンクのQMK Toolboxをインストールします
2. QMK Toolboxの「Keyboard from qmk.fm」の下のリストからrhymestoneを選びます
   1. （もし見つからなければ以下のリンクのデフォルトhexファイルをDLして、「Local File」で選択してください）
3. promicro(直付けの場合は基板)をPCに接続し、リセットボタンを押して書き込みます。
   1. （リセットボタンをダブルクリックしないと書き込めないパターンのものもあります）

書き込み方法などはサリチル酸さんの[（初心者編）自作キーボードにファームウェアを書き込む](https://salicylic-acid3.hatenablog.com/entry/qmk-toolbox)の記事が参考になります。  

[デフォルトhexファイル](https://qmk.fm/compiled/marksard_rhymestone_default.hex)  
[QMK Toolbox](https://github.com/qmk/qmk_toolbox/releases)

#### キーマップを自分好みにする

　もしあなたがプログラミング未経験者なら、QMK Configuratorを使うのが早いでしょう。  

[QMK Configurator](https://docs.qmk.fm/#/ja/newbs_building_firmware_configurator)  

#### ビルド環境を作成する

　自分でソースからビルドが出来るようになるとキーを一つ一つ細かい動作まで自在にカスタムすることが出来ます。  

[QMK　ビルド環境を準備する](https://docs.qmk.fm/#/ja/newbs_getting_started)  

　rhymestoneのデフォルトキーマップは  
```qmk compile -kb marksard/rhymestone -km default```
で可能です。書き込む場合は
```qmk flash -kb marksard/rhymestone -km default```  
とすると、コンパイルが完了次第書き込み待ちになるので、その状態で基板にあるリセットボタンをクリック、もしくはダブルクリックで書き込みが始まります。  

## 基板の裏と表について

　キースイッチが乗り、通常使用する際上を向く面を表、逆を裏とします。  

## 基板の左右を決める

![img](_image/20181212-PC120073.jpg)  

　付属の基板は左右どちらでも使用できるリバーシブル基板になっています。作成途中で左右を忘れないようにマステに左右と書いて、貼ったがわをオモテ（キースイッチを付けるほう）と決めておくと迷いがなくて良いです。  

## ダイオードをはんだ付けする

### ダイオードの脚を曲げる

　基板に付ける前にダイオードの脚を全部曲げてしまいます。基板の穴の間隔を見極めて曲げるための冶具を探してみてください。  繋がったままの割りばしなどでも良いと思います。  

![img](_image/20181212-PC120071.jpg)  

　私はUSB-C to USB-Aの変換コネクタが丁度いい感じに使えたので、ダイオードを2,3個いっぺんに曲げていきました。  

![img](_image/20181212-PC120072.jpg)  

### ダイオードのはんだ付け

　ダイオードの取り付け向きは基板ごとに同じ方向なので、一つ確認して取り付けたら残りはすべて同じ方向で取り付けられます。ダイオードの黒い帯側を基板のダイオード取り付け穴の四角いほうに向けて取り付けてください。  

![img](_image/diode.png)  

![img](_image/20181212-PC120074_2.jpg)  

　左手側基板のウラ面からダイオードを差し込んでいきます。差し込んだらダイオードの足同士をネジって仮留めします。横一列ずつ差し込んでまとめてハンダ付けするとラクに速く出来ます。ハンダ付けしたら足を根元からカットしてください。  

![img](_image/20181212-PC120074.jpg)  
![img](_image/20181212-PC120075.jpg)  

　一列ずつ差し込み、ハンダ付け、カットを繰り返してください。右手側基板も同様に行ってください。  

![img](_image/20181212-PC120077.jpg)  

## *(オプション)LEDをはんだ付けする*

　フルカラーのチップLEDをキースイッチ裏に取り付けていきます。

### LEDの仕組みと接続順序

　このチップLEDは4つの端子（ランド）があり、それぞれVCC,GND,DIN,DOUTです。VCCとGNDは中学でやりましたね？それぞれ電池＋とーという認識でも良いと思います。DINとDOUTはLEDの点灯パターンを制御する線で、DINが入力、DOUTが出力になっています。このDIN、DOUTを数珠繋ぎすることによって複数のLEDを制御するようになっています。  

　Rhymestoneの接続順ですが、リセットボタンの取り付け場所のある端を起点に外側から内側へぐるっと渦巻状に配線しています。数個取り付け→点灯確認→数個取り付け…としたほうが確実で速いので、この順番で取り付けてください。  

![img](_image/ledmap.png)  

### 向きを合わせる

　基板のオモテにLEDのオモテ面が向くように取り付けます。  
　取り付ける向きは基板ごとに一定ですので、最初の一つをちゃんと間違えずにつければあとはそれを真似すれば大丈夫です。  

左手側  
![img](_image/20181212-PC120088_2.jpg)  
![img](_image/led_leftback.png)  

右手側  
![img](_image/20181213-PC130103_2.jpg)  
![img](_image/led_rightback.png)  

### 左手でピンセットでチップLEDつまんでPCBの穴にはめ込んで位置合わせ

![img](_image/20181212-PC120087.jpg)  

### つまんだまま右手でフラックスを塗る

　写真は撮影上つまんでませんが、つまんだままフラックスを塗って、次の作業に向かってください。  

![img](_image/20181212-PC120091.jpg)  

### 220度あたりに設定したハンダごてのこて先にハンダを少し付ける

　コテ先は220度あたりにしてください。270度は高いです。  
　ハンダごてにはんだを少し乗せます。  
　ハンダを少し盛る感じでランドに擦り付けてランド同士を繋げます。  
　基板のランドとチップLEDのランドが出来るだけ水平になるように4つあるランドの一つをまず付けます。付けたらピンセットを離して残り3つを同じように取り付けます。  

![img](_image/20181212-PC120092.jpg)  

### LEDの点灯確認

　事前にpro microにLED動作確認用ファームを書き込んでいると思いますので、pro microを基板のオモテ（マステを貼った方）の白い枠にピンを合わせて取り付けてください。  
　取り付ければLEDが光ると思います。光れば4つのピンのうち、VCC,GND,VINについてはキチンとはんだ付け出来ています。点灯していなければ、今付けたLEDのVCC,GND,VINのハンダがキチンとついてないか、一つ前に付けたVOUTのハンダがついていないのが主な原因です。

### 残りのランドに同じようにはんだする

　あとはこれを繰り返して片手20個、両手で合計40個を付けていきましょう。時々確認すると進捗が分かるので結構嬉しいですし、点灯しなかった時どこで何が起こったかが分かりやすいので地道にやってみてください。  

　全部取り付けた後、ハンダしたトコロがフラックスで汚れてベタ付きますので、気になるならフラックス除去剤で拭き取ってください。  

![img](_image/20181213-PC130102.jpg)  
![img](_image/20181213-PC130104.jpg)  
![img](_image/20181213-PC130101.jpg)  

## *(オプション)OLEDの取り付け*

### OLED取り付けのためのPCBのランドショート

　基板のオモテ側の、Pro Microを取り付ける下側に小さい■が8個4組あると思います。その1組みずつハンダでショートさせください。コツはフラックスを基板のハンダ面に塗って、ハンダごてにハンダを少量のせ基板に当て、4～7秒くらい当てたらスッと基板から離すこと。付かないなと思ったらハンダごてに乗ってるハンダを除去して再挑戦してください。  

![img](_image/20181213-PC130110.jpg)  

### OLED用のピンソケット・ピンヘッダをはんだ付けする

　ラクにまっすぐ取り付けるため、マスキングテープでまっすぐつくように仮押さえしてから裏返してはんだ付けします。  

## TRRSコネクタ、タクトスイッチをはんだ付けする

　ラクにまっすぐ取り付けるため、マスキングテープでまっすぐつくように仮押さえしてから裏返してはんだ付けします。  
　タクトスイッチはパチッとはめ込んで裏返してはんだ付けします。  

![img](_image/20181213-PC130111.jpg)  

## トッププレートにスイッチをはめ込む

　ソケットを先にはんだ付けしても良いのですが、先にトッププレートにスイッチを全部はめ込んで、ソケットを端子に差し込んだ後にハンダ付けしたほうが手早くキレイに取り付けられます。  
　お好みのスイッチをトッププレートにはめ込んでください。  

![img](_image/20181213-PC130105.jpg)  

## MXソケットをはんだ付けする

　まずトッププレートとPCBを合わせます。スイッチ裏の中央の出っ張りをPCBの穴に合わせて取り付けてください。  

![img](_image/20181213-PC130107.jpg)  

　MXソケットをPCBのシルクの白いマークに合わせて取り付けます。スイッチのピンがMXソケットにちゃんと刺さっている事を確認しながらパチパチと全部付けてください。  

![img](_image/20181213-PC130109.jpg)  

　あとはハンダ付けです。MXソケットを取り付けると、スイッチの交換は可能になりますが、ソケットと基板の保持をハンダに頼っているため交換後スイッチが効かないなどのハンダ不良が発生する可能性があります。ただ厚く盛っても意味がないので、PCBとソケットの間にしっかりハンダを流します。  
　ハンダごてのこて先に気持ち多めにハンダを付けて、ソケットの金具の隙間に見えるPCBに付ける気持ちで、ソケットの隙間を少しこじ開ける感じで熱を与えながら流し込みます。  

## スペーサーの取り付け

　ボトムプレートの保護紙の片側を剥がし、剥がした方にゴム脚を取り付けてください。標準でチルトするように大きいものと小さいものが入っていますので、小さいほう二つを手前に、大きいほう二つを奥に貼り付けてください。  

![img](_image/20181213-PC130114.jpg)  

　残りの保護紙も剥がして、8mmスペーサー4つと5mmネジを4つ使ってボトムプレートにねじ止めしてください。  
　ねじ止めしたら、3mmの樹脂スペーサーを8mmスペーサーに差し込んでおきます。この樹脂スペーサーはスイッチ交換時のPCB落ち込みを防止するために機能します。  

![img](_image/20181213-PC130116.jpg)  

## 保護パネルの取り付け

　Pro Micro周りの目隠しとOLEDを保護するためのプレートを取り付けます。8mmスペーサー二つを5mmのネジでPCB(写真の黄色〇の箇所)に取り付けます。  
　プレートの保護紙を両方剥がして、黒の4mmネジでPCBに付けたスペーサーに取り付けてください。  
　少し遊びがありますので、キーキャップを取り付けた時にキーキャップと干渉する場合は少しずらしてください。  

![img](_image/20181213-PC130112.jpg)  

## キーキャップの取り付け

　お好みのキーキャップを取り付けてください。  

## キーボードファームウェアの書き込み

　LEDバックライトのテストのためにled_testを書き込んでいた人は戻ってdefaultキーマップを書き込んでください。  

## テスト

　まず片方ずつPCに接続してテストしてください。片方づつ付けた場合は常に左手で認識するので、キーボードテスターアプリなどでキーが認識されているかチェックしてください。OLEDを取り付けている場合は、OLEDの四段目の表示がスイッチのステータスです。何かしら変化していればOKです。

　ProMicroとUSBを外しします。  
　左右をTRRSケーブルでつないで、左手側のProMicroとUSBを接続してPCに認識させます。  
　左右で通信が出来ているかチェックしてください。

## 完成！

　チェックして問題なさそうなら完成です！あなただけの一台に仕上げてください！

![img](_image/20181214-PC140118.jpg)  

## キースイッチの交換方法

　手では取り外しにくいため、amazonなどで販売されているキースイッチ引き抜き工具を使用して交換してください。  

## 30キーチャレンジ用OLED・Pro Micro保護プレートの使い方

　最上段1段分のキースイッチを取り外し、通常の保護プレートを取り外して、30キーチャレンジ用の保護プレートを取り付けてください。  
　キーマップについての解説は[ここにあります](https://github.com/marksard/qmk_firmware/blob/my_customize/keyboards/rhymestone/keymaps/like_jis_30keys/readme_jp.md)  
![img](_image/30key.png)  
　最初は親指の居場所が心許ないですが、慣れると面白いです！ぜひチャレンジしてみてください。  

## トラブルシューティング

[トラブルシューティング](../../troubleshooting.md)ページを参考にしてください。

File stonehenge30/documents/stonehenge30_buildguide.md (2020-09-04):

# Stonehenge30 ビルドガイド

## キット付属品

| 名前 | 数 | 備考 |
| ---- | ---- | --- |
| PCB | 1枚 | |

## キット以外に必要なもの

| 名前 | 数 | 備考 |
| ---- | ---- | --- |
| ダイオード | 30個 |  |
| タクトスイッチ | 1個 | |
| キースイッチ | 30個 | MX、LowProfile、Alps（未検証） |
| キーキャップ | 30個 | スイッチにあった規格のもの |
| Pro Micro | 1個 | |
| スプリングピンヘッダ 12P | 2個 | 交換や確認にも便利なので必須と言っていいくらい推奨 |
| *LEDストリップ（WS2812B 6個付き）* | *2個* | *Underglow用（オプション）* |
| MicroUSBケーブル | 1本 | キーボードとPC接続用 |

## promicroの準備

　promicroのコネクタ補強、コンスルーピンのはんだ付けを行ってください。  
　promicroは実装されている面がキーボード基板に向くようにコンスルーを取り付けてください。  
 - promicroのコネクタ補強：[ProMicroのモゲ防止ついでにQMK_Firmwareを書き込む](https://qiita.com/hdbx/items/2f3e4ddfcadda2a5578e)
 - コンスルーピンのはんだ付け：[Helixベータ ビルドガイド](https://github.com/MakotoKurauchi/helix/blob/master/Doc/buildguide_jp.md)

  
  

### QMKを準備する

　このキーボードはQMKというキーボード用のソフトウェアで動作するようにプログラミングしています。あらかじめ登録してあるdefaultキーマップは作者が実際に使用しているもので、ほぼ何不自由なく使えるように工夫しています。

　自分でソースからビルドが出来るようになるとキーを一つ一つ細かい動作まで自在にカスタムすることが出来ます。  

[QMK　ビルド環境を準備する](https://docs.qmk.fm/#/ja/newbs_getting_started)  

　stonehenge30のデフォルトキーマップは  
```qmk compile -kb marksard/stonehenge30 -km default```
で可能です。書き込む場合は
```qmk flash -kb marksard/stonehenge30 -km default```  
とすると、コンパイルが完了次第書き込み待ちになるので、その状態で基板にあるリセットボタンをクリック、もしくはダブルクリックで書き込みが始まります。  

## 基板の裏と表について

　キースイッチが乗り、通常使用する際上を向く面を表、逆を裏とします。  
　stonehenge30の場合、stonehenge30と印刷の入ったほうが表になります。  

![img](_image/20190202-P2020237.jpg)  
![img](_image/20190202-P2020238.jpg)  

## ダイオードをはんだ付けする

### ダイオードの脚を曲げる

　基板に付ける前にダイオードの脚を全部曲げてしまいます。基板の穴の間隔を見極めて曲げるための冶具を探してみてください。繋がったままの割りばしなどでも良いと思います。  
　私はUSB-C to USB-Aの変換コネクタが丁度いい感じに使えたので、ダイオードを2,3個いっぺんに曲げていきました。  

![img](../../treadstone48/documents/_image/20181216-PC160164.jpg)  

### ダイオードのはんだ付け

　ダイオードの実装はオモテ面をデフォルトにしています。  
　黒い帯を下側にしてはんだ付けしてください。シルク印刷がデザインでつぶれている箇所含めすべて同じ向きです。  

![img](_image/IMG_8447.jpg)  
![img](_image/20190202-P2020239.jpg)  

![img](../../treadstone48/documents/_image/diode.png)  

## タクトスイッチをはんだ付けする

　リセット用のタクトスイッチをオモテ面に取り付けてください。  

## スイッチをはんだ付けする

　プレートがないのでスイッチが斜めにつかないように注意して取り付けます。5ピンあるPCBマウント用スイッチを使用してください。

![img](_image/20190202-P2020242.jpg)  

もしご家庭にマウントプレートが余っているならこんな感じでスイッチを整列させて何個か一気にやるという手も。  

![img](_image/20190202-P2020240.jpg)  

## *(オプション)UnderglowLEDをはんだ付けする*

　ストリップLEDを付ける位置は、ウラ面の上段左側、下段右側の二か所あります。接続はpro micro→上段左→下段右の順になっていて、下段右側の取り付け位置のランドは、上段左側のLEDを取り付けないと通電しないようになっています。  

　テープLEDの剥離紙の両端数cmだけハサミなどでカットします。  

![img](../../treadstone48/documents/_image/20181216-PC160176.jpg)  

　上段左のLEDは左右端をはんだ付けします。下段右側は左端のみはんだします。  

![img](_image/20190203-P2030270.jpg)  

### 頒布試作機版の注意点

　まずシルクがないです…LED側のGND、DIN、5Vを上段左のランドにはんだします…が、5VとGNDの配線パターンにミスがあり逆になっています。うまい具合に配線剤を使ってクロスして取り付けてください。このときストリップLEDのシール側の金色の部分にハンダが接触するとショートする可能性があるので、金色の部分は剥離紙を被せておくと良いです。  

![img](_image/20190203-P2030274.jpg)  

## キーキャップの取り付け

　お好みのキーキャップを取り付けてください。  

## 脚の取り付け

　お好みの脚を付けてください。クッションゴムシートを直接取り付ける場合、ゴムの厚みが薄いと下面のハンダで机が傷付くため、ハンダした箇所をキレイに処理したうえで干渉しない厚さのゴムシートをお使いください。  
　角かそれに近い4箇所は必須で、PCB自体が結構柔らかいので打鍵感を見ながら追加で貼ると良いと思います。  

　参考までに、下の作例写真では戸当のネジ穴のあるゴムと、両端ネジ穴のある8mmスペーサーを使って8箇所脚を作っています。  

![img](_image/20190203-P2030276.jpg)  

## 完成！

　チェックして問題なさそうなら完成です！あなただけの一台に仕上げてください！

![img](_image/20190202-P2020255.jpg)  
![img](_image/20190203-P2030266.jpg)  
![img](_image/20190211-P2110297.jpg)  

## トラブルシューティング

[トラブルシューティング](../../troubleshooting.md)ページを参考にしてください。

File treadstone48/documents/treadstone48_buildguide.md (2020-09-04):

# Treadstone48 ビルドガイド

## キット付属品

*2019/07/08：パーツ構成をアップデートしました。ネジをすべて黒にしました。2mmプラスチックスペーサーとTRRSジャックは付属品から外しました。*

| 名前 | 数 | 備考 |
| ---- | ---- | --- |
| PCB | 1枚 | いわゆる基板です |
| トッププレート | 1枚| スイッチを取り付ける穴があいてます |
| ボトムプレート | 1枚| アクリル製 |
| OLED・ProMicro保護プレート | 1枚 | アクリル製 |
| M2スペーサー 8mm | 2個 | 基板・保護プレート接続用 |
| M2スペーサー 7mm | 8個 | トップ・ボトムプレート接続用 |
| M2ネジ 4mm| 20個 |  |
| ゴム足 | 8個 | 小8個 |
| ダイオード | 48個 | 1N4148 |
| タクトスイッチ | 1個 | リセットスイッチ用 |

## キット以外に必要なもの

| 名前 | 数 | 備考 |
| ---- | ---- | --- |
| MicroUSBケーブル | 1本 | キーボードとPC接続用 |
| キースイッチ | 47～48個 | MX互換のもの |
| キーキャップ | 47～48個 | MX互換のもの |
| MXソケット | 47〜48個 | MXスイッチ用ソケット |
| Pro Micro | 1個 | |
| コンスルー（スプリングピンヘッダ） 12P | 2個 | 推奨 |

### オプション

オプションでイルミネーション用LEDと情報表示用のOLEDが取り付け可能です。  

| 名前 | 数 | 備考 |
| ---- | ---- | --- |
| スタビライザー | 1～4個 | Shiftキー位置(プレートマウント、PCBマウント対応)<br/>Enter位置(プレートマウント、PCBマウント対応)<br/>スペース位置(プレートマウントのみ対応)（すべてオプション） |
| LEDストリップ（WS2812B 6個付き） | 2個 | Underglow用（オプション） |
| OLEDモジュール | 1個 | OLED用（オプション）取り付け高難易度のため非推奨 |
| ピンソケット 4P | 1個 | OLED用（オプション）取り付け高難易度のため非推奨<br/>2.54mmピッチ、ロープロファイル（低背）基板取り付け高さ3.5mm、1x4のもの<br/>秋月電子かヒロスギネットで購入可能 |
| ピンヘッダ 4P | 1個 | OLED用（オプション）取り付け高難易度のため非推奨 |
| TRRSジャック | 1個 | オプションのRhymestone接続用。繋がないなら取り付け不要 |
| 3.5mmステレオケーブル(3極) | 1本 | Rhymestoneとの接続用（オプション） |

## 必要な道具

| 名前 | 備考 |
| ---- | ---- |
| はんだごて | |
| 糸ハンダ | 0.8mm程度のものを推奨します |
| ハンダ吸い取り線 | 失敗したとき用 |
| ニッパー | ダイオードのリード線などの切断用です |
| ピンセット | ProMicroリセットしたりチップLEDのはんだづけで使用します |
| フラックス除去剤 | 必須ではありませんがはんだ付け後のベタつきを除去出来、はんだによる黄色い変色も拭き取れてキレイな仕上がりになります |
| マスキングテープ | しるし付け、仮固定に使用。100均の柄付きでもOK |

　mteiさんの[Helix キーボードキットの製作に必要な工具メモ](https://gist.github.com/mtei/6957107a676ddfa85bde0ae41f8fa849)
やhdbxさんの[自作キーボードを始めるにあたって用意すべきツール](https://hdbx.hateblo.jp/entry/2018/06/01/215401)も参考になります。  

  
  

## promicroの準備

　promicroのコネクタ補強、コンスルーピンのはんだ付けを行ってください。  
　promicroは実装されている面がキーボード基板に向くようにコンスルーを取り付けてください。  
 - promicroのコネクタ補強：[ProMicroのモゲ防止ついでにQMK_Firmwareを書き込む](https://qiita.com/hdbx/items/2f3e4ddfcadda2a5578e)
 - コンスルーピンのはんだ付け：[Helixベータ ビルドガイド](https://github.com/MakotoKurauchi/helix/blob/master/Doc/buildguide_jp.md)

  
  

### QMKを準備する

　このキーボードはQMKというキーボード用のソフトウェアで動作するようにプログラミングしています。あらかじめ登録してあるdefaultキーマップは作者が実際に使用しているもので、ほぼ何不自由なく使えるように工夫しています。

1. 下記リンクのQMK Toolboxをインストールします
2. QMK Toolboxの「Keyboard from qmk.fm」の下のリストからtreadstone48/rev1を選びます
   1. （もし見つからなければ以下のリンクのデフォルトhexファイルをDLして、「Local File」で選択してください）
3. promicro(直付けの場合は基板)をPCに接続し、リセットボタンを押して書き込みます。
   1. （リセットボタンをダブルクリックしないと書き込めないパターンのものもあります）

書き込み方法などはサリチル酸さんの[（初心者編）自作キーボードにファームウェアを書き込む](https://salicylic-acid3.hatenablog.com/entry/qmk-toolbox)の記事が参考になります。  

[デフォルトhexファイル](https://qmk.fm/compiled/treadstone48_rev1_default.hex)  
[QMK Toolbox](https://github.com/qmk/qmk_toolbox/releases)

#### キーマップを自分好みにする

　もしあなたがプログラミング未経験者なら、QMK Configuratorを使うのが早いでしょう。  

[QMK Configurator](https://docs.qmk.fm/#/ja/newbs_building_firmware_configurator)  

#### ビルド環境を作成する

　自分でソースからビルドが出来るようになるとキーを一つ一つ細かい動作まで自在にカスタムすることが出来ます。  

[QMK　ビルド環境を準備する](https://docs.qmk.fm/#/ja/newbs_getting_started)  

　treadstone48のデフォルトキーマップは  
```qmk compile -kb treadstone48/rev1 -km default```
で可能です。書き込む場合は
```qmk flash -kb treadstone48/rev1 -km default```  
とすると、コンパイルが完了次第書き込み待ちになるので、その状態で基板にあるリセットボタンをクリック、もしくはダブルクリックで書き込みが始まります。  

## 基板の裏と表について

　キースイッチが乗り、通常使用する際上を向く面を表、逆を裏とします。  
　Treadstone48の場合、ロゴとデザインの印刷の入ったほうが裏になります。  

## ダイオードをはんだ付けする

### ダイオードの脚を曲げる

　基板に付ける前にダイオードの脚を全部曲げてしまいます。基板の穴の間隔を見極めて曲げるための冶具を探してみてください。繋がったままの割りばしなどでも良いと思います。  

![img](../../_image/diode01.jpg)  

### ダイオードのはんだ付け

　ダイオードの取り付け向きは同じ方向なので、一つ確認して取り付けたら残りはすべて同じ方向で取り付けられます。ダイオードの黒や緑の帯側を基板のダイオード取り付け穴の四角いほうに向けて取り付けてください。  

![img](../../_image/diode02.png)  

　基板のウラ面からダイオードを差し込んでいきます。差し込んだらダイオードの足同士をネジって仮留めします。横一列ずつ差し込んでまとめてハンダ付けするとラクに速く出来ます。ハンダ付けしたら足を根元からカットしてください。  

## リセットスイッチをはんだ付けする

　リセットスイッチもウラ面に取り付けます。パチッとはめ込んで裏返してはんだ付けします。  

![img](_image/20181223-PC230006.jpg)  

![img](_image/20181216-PC160171.jpg)  

## トッププレートにスイッチをはめ込む

　ソケットをはんだ付けするためにレイアウトを決めます。  

![img](_image/keymap.png)  

　右下のmenuキーの個所は1.25Uのキーキャップを取り付けるか、右に寄せて1Uのキーキャップを取り付けるかの選択が出来ます。デフォルトキーマップには1.25Uをつけた場合を想定して「プロパティメニュー」キーが割り当てられています。  

　右上は2Uを1個か、1Uを2個取り付けるかの選択が出来ます。デフォルトキーマップには2Uが1個の時は「-」キー、1Uが2個の時は「-」キーと「Delete」キーが割り当てられています。  

![img](_image/20181216-PC160160.jpg)  
![img](_image/20181216-PC160161.jpg)  

## MXソケットをはんだ付けする

　まずトッププレートとPCBを合わせます。スイッチ裏の中央の出っ張りをPCBの穴に合わせて取り付けてください。  
　MXソケットをPCBのシルクの白いマークに合わせて取り付けます。スイッチのピンがMXソケットにちゃんと刺さっている事を確認しながらパチパチと全部付けてください。  
　こうすることでMXソケットが浮かずに確実にはんだ付け出来ます。  

　あとはハンダ付けです。MXソケットを取り付けると、スイッチの交換は可能になりますが、ソケットと基板の保持をハンダに頼っているため交換後スイッチが効かないなどのハンダ不良が発生する可能性があります。ただ厚く盛っても意味がないので、PCBとソケットの間にしっかりハンダを流します。  
　ハンダごてのこて先に気持ち多めにハンダを付けて、ソケットの金具の隙間に見えるPCBに付ける気持ちで、ソケットの隙間を少しこじ開ける感じで熱を与えながら流し込みます。  

## *(オプション)TRRSコネクタをはんだ付けする*

　rhymestone(販売自体は終了。基板データは公開中)と接続する場合はTRRSをウラ面に取り付けます。ラクにまっすぐ取り付けるため、マスキングテープでまっすぐつくように仮押さえしてから裏返してはんだ付けします。  

![img](_image/20181223-PC230005.jpg)  

## *(オプション)UnderglowLEDをはんだ付けする*

　写真のようにテープLEDの剥離紙の両端数cmだけハサミなどでカットします。これはテープLEDの背面の端子と、キーボード基板のスルーホールなどの端子が接触して動作不良を起こすことを防ぐ意味合いがあります。  

![img](../../_image/led_tape.jpg)  

　テープLEDは向きがありテープLEDの端子と基板の端子が合う向きにします。
![img](_image/20181223-PC230007.jpg)  

　Pro Microに近い一枚目はテープLED両端をはんだ付けする必要があるので、基板の両端のランドに少し被るくらいの位置にテープLEDを貼り付けてはんだ付けしてください。  

![img](_image/20181223-PC230008.jpg)  

　二枚目は片側だけですが、同じように向きに注意して貼り付けてはんだ付けしてください。  

## 保護パネルの取り付け

　Pro Micro周りの目隠しとOLEDを保護するためのプレートを取り付けます。8mmスペーサー2つをネジでPro Microの下にある穴に取り付けます。  
　プレートの保護紙を両方剥がして、ネジでPCBに付けたスペーサーに取り付けてください。  
　少し遊びがありますので、キーキャップを取り付けた時にキーキャップと干渉する場合は少しずらしてください。  

## *(オプション)OLED用のピンソケット・ピンヘッダをはんだ付けする*

　オモテ面に取り付けます。ラクにまっすぐ取り付けるため、マスキングテープでまっすぐつくように仮押さえしてから裏返してはんだ付けします。  

## *(オプション)OLEDの取り付け*

### OLED基板のカット

　Pro Micro直下に取り付けるスペーサーと、OLEDの基板が左右1mm x 3mmくらい干渉しますので、写真のようにカットしてください。左が加工後です。  
![img](../../_image/oled01.jpg)  

　スペーサーをゆるく仮止めしつつ現物合わせで削り込んでいってください。  
![img](_image/20181223-PC230004.jpg)  

## スペーサーの取り付け

　ボトムプレートの彫刻の入ってるの保護紙を剥がします。彫刻の細かい部分の保護紙はピンセットなどで剥がします。剥がした方にゴム脚を取り付けてください。標準でチルトするように大きいものと小さいものが入っていますので、小さいほう４つを手前に、大きいほう４つを奥に貼り付けてください。  

　残りの保護紙も剥がして、**7mm**スペーサー8つとネジを8つ使ってボトムプレートにねじ止めしてください。次にPCBの付いたマウントプレートを載せてネジ留めしてください。  

## キーキャップの取り付け

　お好みのキーキャップを取り付けてください。  

## テスト

　PCに接続して動作チェックしてください。[QMK Keytest](https://config.qmk.fm/#/test)やキーボードテスターアプリでキーが認識されているかチェックしてください。OLEDを取り付けている場合は、OLEDの四段目の表示がスイッチのステータスです。何かしら変化していればOKです。  

## 完成！

　チェックして問題なさそうなら完成です！あなただけの一台に仕上げてください！

![img](_image/20181220-PC200005.jpg)  

## キースイッチの交換方法

　手では取り外しにくいため、amazonなどで販売されているキースイッチ引き抜き工具を使用して交換してください。  

## *(オプション)Rhymestoneと組み合わせて使用する場合*

　Rhymestoneのどちらか片方をTreadstone48に接続してテンキーとして使用できるキーマップを用意しています。  
　デフォルトのキーマップではRhymestoneは左手側を接続するようにしていますが、右手側の切り替えも可能なようになっています。詳しくは[キーマップのreadmeを参照してください](https://github.com/marksard/qmk_firmware/blob/my_customize/keyboards/treadstone48/keymaps/like_jis_rs/readme_jp.md)  

## トラブルシューティング

[トラブルシューティング](../../troubleshooting.md)ページを参考にしてください。

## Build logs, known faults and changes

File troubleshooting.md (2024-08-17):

# トラブルシューティング

　有志で作成している[Self-Made Keyboards in Japan](https://scrapbox.io/self-made-kbds-ja/)の記事が役に立つと思いますのでこちらもご一読ください。  

　[動かなくて相談したいときに事前に確認する項目](https://scrapbox.io/self-made-kbds-ja/%E5%8B%95%E3%81%8B%E3%81%AA%E3%81%8F%E3%81%A6%E7%9B%B8%E8%AB%87%E3%81%97%E3%81%9F%E3%81%84%E3%81%A8%E3%81%8D%E3%81%AB%E4%BA%8B%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)  
　[キーボードを組み立てるときに陥るミスと対策](https://scrapbox.io/self-made-kbds-ja/%E3%82%AD%E3%83%BC%E3%83%9C%E3%83%BC%E3%83%89%E3%82%92%E7%B5%84%E3%81%BF%E7%AB%8B%E3%81%A6%E3%82%8B%E3%81%A8%E3%81%8D%E3%81%AB%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)  
　[動かなくて相談したいときに事前に確認する項目(はんだづけ編)](https://scrapbox.io/self-made-kbds-ja/%E5%8B%95%E3%81%8B%E3%81%AA%E3%81%8F%E3%81%A6%E7%9B%B8%E8%AB%87%E3%81%97%E3%81%9F%E3%81%84%E3%81%A8%E3%81%8D%E3%81%AB%E4%BA%8B%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)  

　わからない事があれば、[Twitter:@marksard](https://twitter.com/marksard)宛にリプライください。  

## 必要な道具

- テスター

　導通テストが出来るテスターなら導通モードに、なければ抵抗値を測るモードにしてレンジは0Ωかどうかの見分けがしやすいモードにしてください。  

## 注意事項

　テスターを端子にあてて計測するさい、計測対象は電源が入っていない状態で行ってください。  

## 各項目共通の確認事項

- pro microに適切なファームウェアを書き込んでいるか
- pro microはしっかり差し込まれているか
- ハンダを適切に付けられているか
- パーツの極性（取り付ける向き）は間違っていないか

　また左右のキーボードを接続する場合は両方のpro microに同じファームウェアが入っている必要があります。  

### はんだ付けについて

[はんだ付け基礎講座　WEB版](https://noseseiki.com/kisokouza/01.html)  
[電子工作のコツ/はんだ付け](https://www.murata.com/ja-jp/campaign/ads/japan/elekids/ele/craft/knack/soldering)  

をはじめとして探せば適切なはんだ付けについて書かれていますので一読をおすすめします。  

　ハンダごての設定温度が高く、かつ長時間あてつづけるとTRRSジャックやコンスル―ピン、OLEDのピンやソケットのプラを溶かして接続不良の原因になります。また基板のシルクやレジストにも影響し基板の剥がれも起きやすくメリットがないので、🔰ほど温度調節機能付きハンダごてをオススメします。  

## キースイッチ

### まったく動作しない

　pro microの取り付け向きを確認してください。treadstone48、rhymestone、stonehenge30についてはpro microはICの実装されていない面が下側です。  
　pro microの取り付け位置は、基板の白い枠にpro microのピンを合わせて取り付けてください。  
　pro microが浮いていないことを確認してください。  
　ダイオードの極性が間違っていないか確認してください。  

### 一部のキーが動かない

　MX Socketのハンダ不良、はんだ忘れか、スイッチの端子がソケットに正しく入っていない可能性があります。  
　ソケットでないPCBの場合、近接する基板のメッキ部分がハンダで繋がっていないかも確認してください。  

### 行単位、列単位で動作しない、押したキーとは違うキーが反応する

　pro microとピンのはんだ付けミスの可能性が高いです。よく確認して隣のピンとショートしていないことを確認して、ハンダごてを当てなおして各ピンに付けたハンダを温めなおしてみてください。  

## LED

### まったく点灯しない

　書き込んだキーマップのrules.mkのLED_BACK_ENABLEが = yesか確認してください。  
　初期状態はLEDがOFFなのでONにしてください。  
Lower + Raise + AキーでON/OFFを切り替えられます。  
　[キーマップ](https://github.com/marksard/qmk_firmware/blob/my_customize/keyboards/rhymestone/keymaps/default/readme_jp.md)  

　切り替えても点灯しない場合は先頭のLEDのDIN、GND、VCCがハンダ不良か、DINが熱で死んでいるかで起こり得ます。  
　ハンダ不良の可能性から疑ってハンダを温めなおしたりハンダを付け直してみてください。ダメならLEDチップを交換してください。  

### 途中からLEDが途切れる

　途切れたLEDのDIN、GND、VCCがハンダ不良か、DINが熱で死んでいるか、その一つ手前のDOUTががハンダ不良か、DINが熱で死んでいるかで起こり得ます。  
　ハンダ不良の可能性から疑ってハンダを温めなおしたりハンダを付け直してみてください。ダメならLEDチップを交換してください。  

### 一部のLEDだけ点灯しない

　LEDのDIN、DOUTが生きていて、GNDかVCCの端子が熱で死んでいるかハンダ不良の場合に起こり得ます。  
　ハンダ不良の可能性から疑ってハンダを温めなおしたりハンダを付け直してみてください。ダメならLEDチップを交換してください。  

### 一部違う色になる、色を変更しても変化したりしなかったりする

　該当のLEDのDINの接触不良か、該当のLEDにつないでいるDOUTの接続不良かどちらかです。  
　ハンダを温めなおしたりハンダを付け直してみてください。  

## OLED

　書き込んだキーマップのrules.mkのOLED_ENABLEが = yesか確認してください。  
　スイッチなどはないので、電源が入れば点灯、表示されるようになっています。  

　表示されない場合はOLEDとピンのハンダ不良か、RhymestoneであればOLEDの取り付けソケットとpro microの間にあるハンダブリッジ部分のハンダ不良の可能性があります。  

## キーボード同士の接続

　TRSケーブル、TRRSケーブルで左右を接続し、USBを左手側に接続した状態で、左側だけ認識して右側は反応しない、逆にUSBを右手側に繋ぐと左手側が反応しないときは、左右の接続に問題があります。  

### 電源ラインの確認

　USBを接続した側の電源をもう一方へ供給しています。USBを接続していないほうのpro microに仕込まれたLEDか、バックライトLED、OLEDの表示を確認してください。点灯していないならケーブル不良、もしくはジャックの接続不良が考えられます。  
　TRRSジャックのハンダを温めなおしたりハンダを付け直してみてください。  

### TRSケーブル、TRRSケーブル

　Rhymestone、Treadstone48はTRSケーブル、TRRSケーブルどちらでの接続でも問題なく動作することを確認しています。  
　ケーブルの導通が正しいかテスターで確認してください。両端のT,R,R,Sをそれぞれが独立して導通していることを確認してください。  

### TRRSジャックとケーブルを付けての確認

　TRRSジャックからpro microへの経路が正しいか確認します。  
　左右をケーブルで接続した状態で、両側のTRRSジャックにテスターをあてて導通しているかチェックしてください。導通しているのが確認が取れたら両側のpro microのVCC同士、GND同士、RX同士の導通確認をしてください。導通していない場合はpro microとTRRSジャックの経路があやしい（基板不良）か、TRRSジャックの接続不良、TRRSジャック自体が壊れていることも考えられます。  

### シリアル通信速度を変更する

　ここまでの検査で導通に問題なければ、なんらかの影響で信号ラインにノイズが乗っていて左右の通信がうまく出来ていない可能性があります。  

ファームウェアのキーボードフォルダのRhymestone、Treadstone48の直下にserial.cファイルがあります。この中のこの部分を見つけてください

```c
#define SELECT_SOFT_SERIAL_SPEED 1
//  0: about 189kbps
//  1: about 137kbps (default)
//  2: about 75kbps
//  3: about 39kbps
//  4: about 26kbps
//  5: about 20kbps
```

この  

```#define SELECT_SOFT_SERIAL_SPEED 1```  

を  

```#define SELECT_SOFT_SERIAL_SPEED 5```

に変更して両方のpro microに書き込み、左手、右手が動作するか確認してください。動作するのであれば5を4,3,2と速めて動かなくなる一つ手前をご使用ください。  

### まだ接続がうまくいかない…

　この「キーボード同士の接続」の項を順番にやると以下の検査を行っています。  

- TRRSケーブル/TRSケーブルの検査
- 両方のTRRSジャックの検査
- TRRSジャックからpro microまで経路検査

　接続自体は正常な事を確認出来ているので基板自体は正常なはずです。また、  

- シリアル通信速度の変更

で通信速度を落として接続が出来るかどうかも確認しています。  

TRRSケーブル/TRSケーブルを変えてみると正常動作するという報告もありますので、一度ご検討をお願いいたします。  

### I2C通信に変更する

　Rhymestone、Treadstone48ともにI2Cでの接続は未検証かつ少し基板のジャンパパッドのカット、ハンダでジャンパする、ひょっとすると抵抗が必要、みたいな改造が必要になります。ご用命があれば検証いたします。

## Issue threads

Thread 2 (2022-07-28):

Rhymestone rev V1.0 JLCPCB issues

darknessblade, 2022-07-28:
When uploading and checking it with JLC-PCB the pcb does not get uploaded correctly, If I am not mistaken, there are some issues with the substrate. causing the PCB/gerber detection to fail.

When looking at it with the JLCPCB 3D viewer the Substrate holes are not visible, the pcb is 1 solid board without any holes.

Other keyboards upload just fine without any issues. showing the substrate holes just fine

darknessblade, 2022-08-09:
Currently gotten it to work.
-----------
Though I have now a  different issue while trying to compile the QMK firmware it says there is no rules to make a target.

Closed 2022-08-30.

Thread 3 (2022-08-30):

Rhymestone VIA/VIAL definitions do not work

darknessblade, 2022-08-30:
Just as the Title says the VIA/VIAL definitons are outdated, and do not work with the current version of VIA.

the JSON file gives errors, when trying to load/sideload it.

I also have the issue that with the default layout the bottom row does not work

darknessblade, 2022-09-13:
Update: The bottom row issue seems to be caused by the arduino I used, it had a defective trace/bad connection.

darknessblade, 2022-09-25:
Is there been any update on adding VIA/VIAL support for the Rhymestone?

darknessblade, 2022-10-18:
Found the VIA version on the QMK github page.
for some reason with MSYS it did not download so i had to add the files to the keymap/firmware directory, myself.

The VIA firmware seems to be working fine. though the only Issue I encounter for now is when I try to sideload it into VIAL.
------------
File "main_window.py", line 284, in on_device_selected
  File "main_window.py", line 304, in rebuild
  File "editor\keymap_editor.py", line 125, in rebuild
  File "keycodes.py", line 870, in recreate_keyboard_keycodes

AttributeError: 'Keyboard' object has no attribute 'tap_dance_count'
---------
Since I now have the VIA_keymap.JSON, I can more easily see if I can make my own VIAL compatible version, that does not have the sideloading issue.

darknessblade, 2022-10-28:
there are a few issues with vial. it shows the RGB menu even with RGB disabled. not sure what causes this issue, gonna test a few things later to see if I can fix this,

havent found any other issues yet

marksard, 2024-08-16:
Sorry I didn't notice.
Please use the file here.
We have confirmed that it works with REMAP.
https://github.com/marksard/qmk_firmware_hex/releases
https://remap-keys.app/

Sorry about the vial support, we cannot respond.

Closed 2024-08-16.

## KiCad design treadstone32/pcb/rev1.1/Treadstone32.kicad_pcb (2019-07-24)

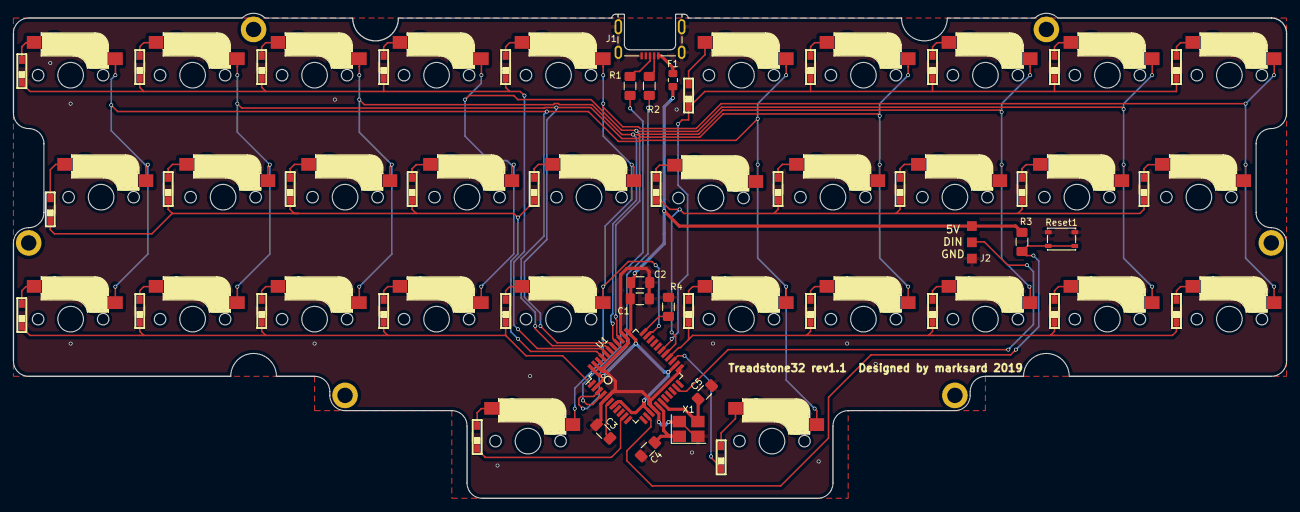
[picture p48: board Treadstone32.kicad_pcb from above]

Board: 2 copper layers, 198.8 x 75.8 mm, 79 parts (0 on the bottom side), 58 nets.

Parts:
C1: 0.1uF; C_1206_3216Metric_Pad1.42x1.75mm_HandSolder
C2, C3: 1uF; C_1206_3216Metric_Pad1.42x1.75mm_HandSolder
C4, C5: 22pF; C_1206_3216Metric_Pad1.42x1.75mm_HandSolder
D1, D2, D3, D4, D5, D6, D7, D8, D9, D10, D11, D12, D13, D14, D15, D16, D17, D18, D19, D20, D21, D22, D23, D24, D25, D26, D27, D28, D29, D30, D31, D32: D; D3_SMD_only_front
F1: 500mA; Fuse_0805_2012Metric_Pad1.15x1.40mm_HandSolder
J1: USB_mini_micro_B; MOLEX_47642-0001_HandSoldering_cuts
J2: Conn_01x03; StripLED_front
R1, R2: 22; R_1206_3216Metric_Pad1.42x1.75mm_HandSolder
R3, R4: 10k; R_1206_3216Metric_Pad1.42x1.75mm_HandSolder
Reset1: Reset; SW_SPST_PTS810
SW1, SW2, SW3, SW4, SW5, SW6, SW7, SW8, SW9, SW10, SW11, SW12, SW13, SW14, SW15, SW16, SW17, SW18, SW19, SW20, SW21, SW22, SW23, SW24, SW25, SW26, SW27, SW28, SW29, SW30, SW31, SW32: SW_PUSH; CherryMX_Hotswap_front
U1: ATMEGA32U4; TQFP-44_10x10mm_P0.8mm
X1: 16MHz; Crystal_SMD_3225-4Pin_3.2x2.5mm_HandSoldering

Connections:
GND: C1.2, C2.2, C3.1, C4.2, C5.2, J1.5, J1.6, J2.1, R4.2, Reset1.1, U1.5, U1.15, U1.23, U1.35, U1.43, X1.2, X1.4
LED: J2.2, U1.21
unnamed: C3.2, U1.6
unnamed: C4.1, U1.16, X1.1
unnamed: C5.1, U1.17, X1.3
unnamed: D1.2, SW1.2
unnamed: D2.2, SW2.2
unnamed: D3.2, SW3.2
unnamed: D4.2, SW4.2
unnamed: D5.2, SW5.2
unnamed: D6.2, SW6.2
unnamed: D7.2, SW7.2
unnamed: D8.2, SW8.2
unnamed: D9.2, SW9.2
unnamed: D10.2, SW10.2
unnamed: D11.2, SW11.2
unnamed: D12.2, SW12.2
unnamed: D13.2, SW13.2
unnamed: D14.2, SW14.2
unnamed: D15.2, SW15.2
unnamed: D16.2, SW16.2
unnamed: D17.2, SW17.2
unnamed: D18.2, SW18.2
unnamed: D19.2, SW19.2
unnamed: D20.2, SW20.2
unnamed: D21.2, SW21.2
unnamed: D22.2, SW22.2
unnamed: D23.2, SW23.2
unnamed: D24.2, SW24.2
unnamed: D25.2, SW25.2
unnamed: D26.2, SW26.2
unnamed: D27.2, SW27.2
unnamed: D28.2, SW28.2
unnamed: D29.2, SW29.2
unnamed: D30.2, SW30.2
unnamed: D31.2, SW31.2
unnamed: D32.2, SW32.2
unnamed: F1.1, J1.1
unnamed: J1.2, R2.1
unnamed: J1.3, R1.1
unnamed: R1.2, U1.4
unnamed: R2.2, U1.3
unnamed: R3.2, Reset1.2, U1.13
unnamed: R4.1, U1.33
VCC: C1.1, C2.1, F1.2, J2.3, R3.1, U1.2, U1.7, U1.14, U1.24, U1.34, U1.44
col0: SW1.1, SW2.1, SW3.1, SW17.1, SW18.1, SW19.1, SW20.1, U1.39
col1: SW4.1, SW5.1, SW6.1, SW21.1, SW22.1, SW23.1, U1.38
col2: SW7.1, SW8.1, SW9.1, SW24.1, SW25.1, SW26.1, U1.37
col3: SW10.1, SW11.1, SW12.1, SW27.1, SW28.1, SW29.1, U1.36
col4: SW13.1, SW14.1, SW15.1, SW16.1, SW30.1, SW31.1, SW32.1, U1.32
row0: D1.1, D4.1, D7.1, D10.1, D13.1, U1.40
row1: D2.1, D5.1, D8.1, D11.1, D14.1, U1.41
row2: D3.1, D6.1, D9.1, D12.1, D15.1, U1.1
row3: D16.1, U1.10
row4: D17.1, D21.1, D24.1, D27.1, D30.1, U1.28
row5: D18.1, D22.1, D25.1, D28.1, D31.1, U1.27
row6: D19.1, D23.1, D26.1, D29.1, D32.1, U1.26
row7: D20.1, U1.25

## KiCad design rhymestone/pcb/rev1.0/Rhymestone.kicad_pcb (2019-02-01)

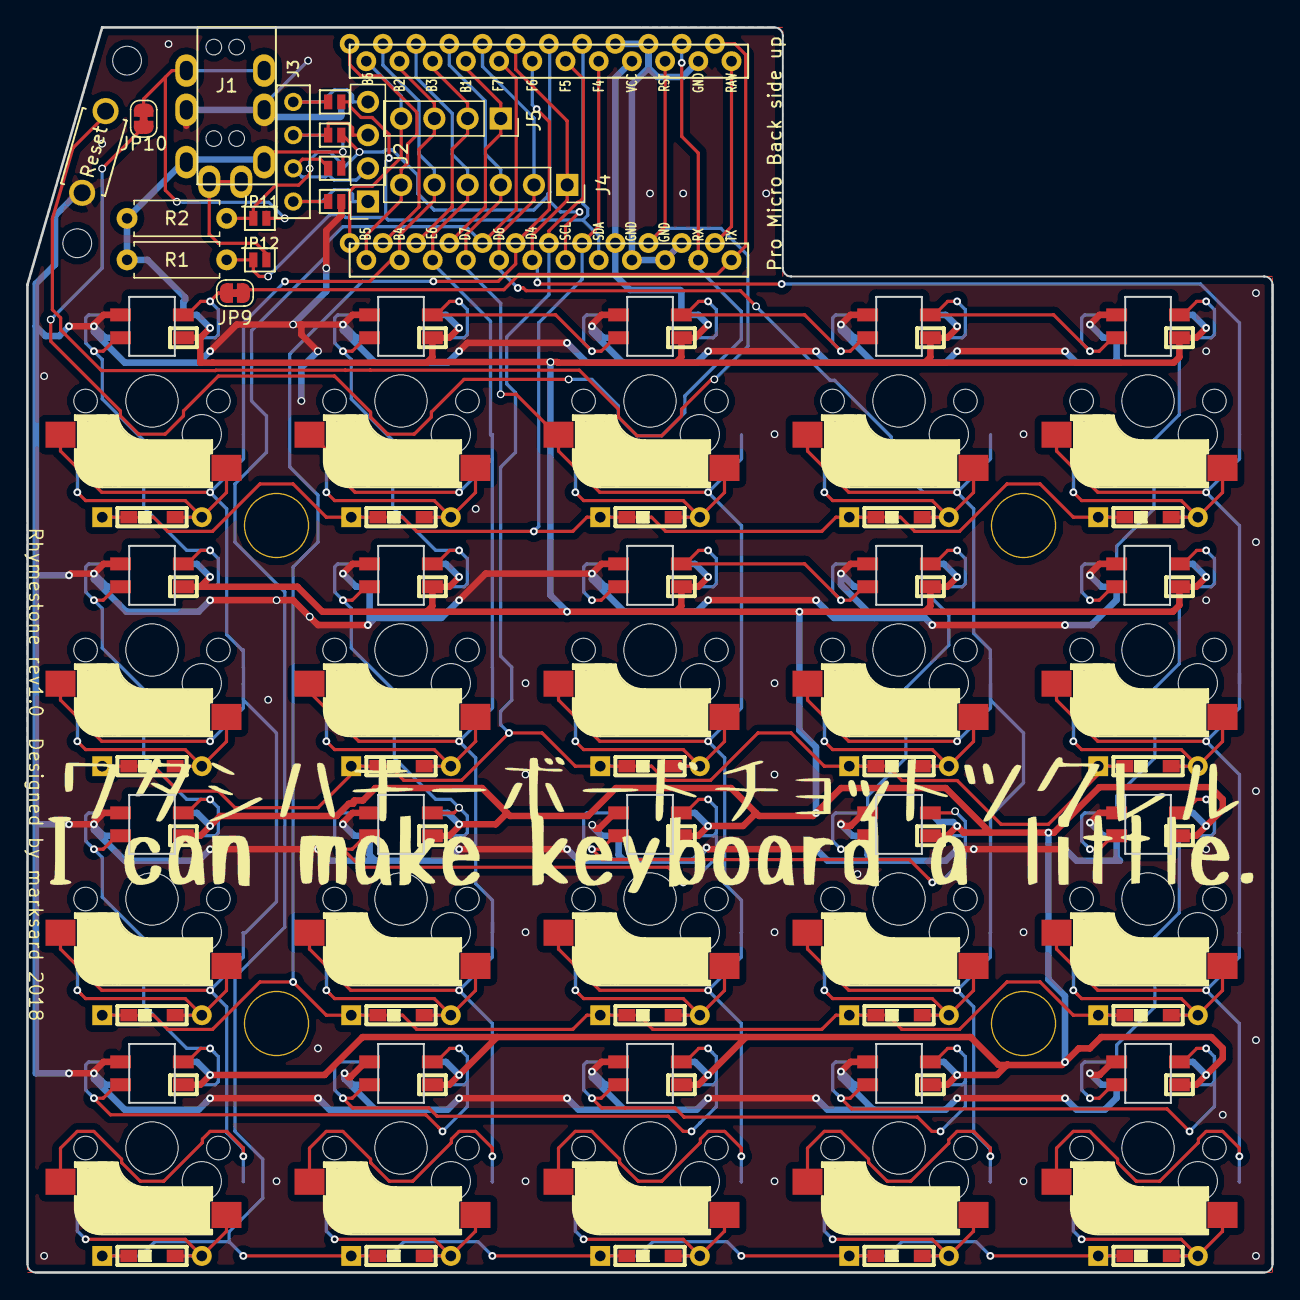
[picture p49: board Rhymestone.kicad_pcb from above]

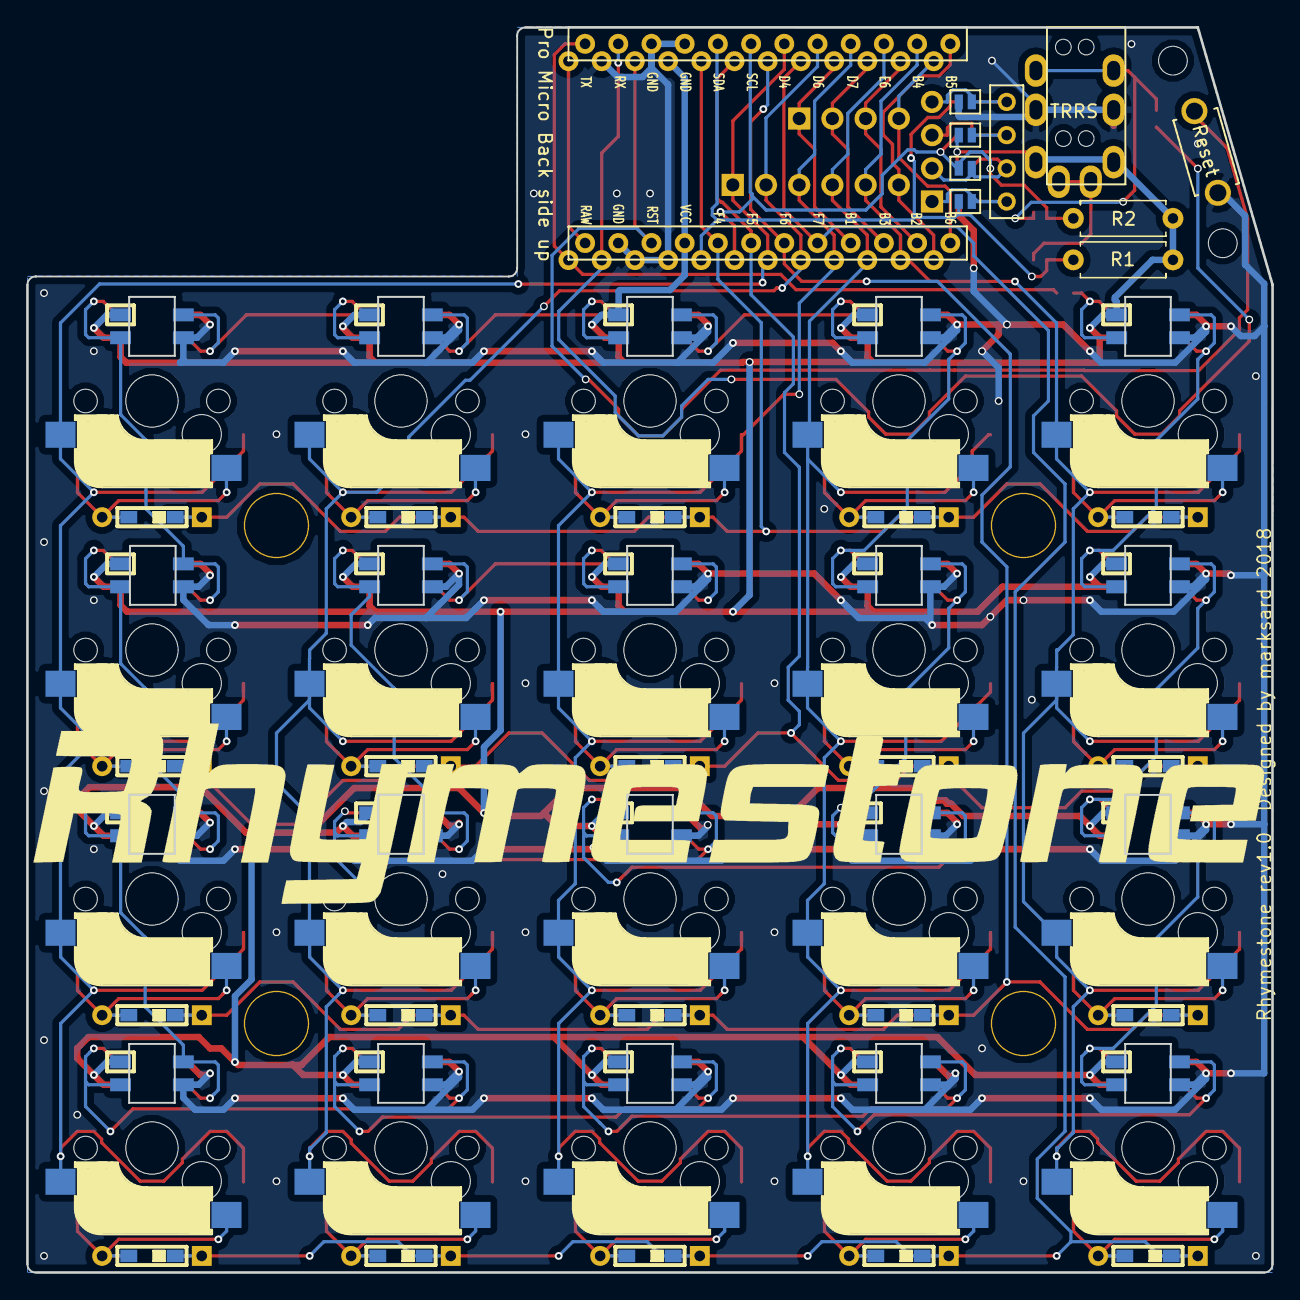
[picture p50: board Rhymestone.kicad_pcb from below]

Board: 2 copper layers, 95.3 x 95.3 mm, 87 parts (4 on the bottom side), 67 nets.

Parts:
D1, D2, D3, D4, D5, D6, D7, D8, D9, D10, D11, D12, D13, D14, D15, D16, D17, D18, D19, D20: D; D3_SMD
J1: MJ-4PP-9
J2: AUX; PinSocket_1x04_P2.54mm_Vertical
J3: OLED
J4: Columns; PinSocket_1x06_P2.54mm_Vertical
J5: Rows; PinSocket_1x04_P2.54mm_Vertical
JP1, JP2, JP3, JP4, JP5, JP6, JP7, JP8: Jumper
JP9: LED; SolderJumper-2_P1.3mm_Bridged_RoundedPad1.0x1.5mm
JP10: DataJP; SolderJumper-2_P1.3mm_Bridged_RoundedPad1.0x1.5mm
JP11: SDLJP; Jumper
JP12: SDAJP; Jumper
L1, L2, L3, L4, L5, L6, L7, L8, L9, L10, L11, L12, L13, L14, L15, L16, L17, L18, L19, L20: SK6812MINI; SK6812MINI_rev
R1, R2: R; R_TH
RSW1: Reset; ResetSW
SW1, SW2, SW3, SW4, SW5, SW6, SW7, SW8, SW9, SW10, SW11, SW12, SW13, SW14, SW15, SW16, SW17, SW18, SW19, SW20: SW_PUSH; CherryMX_Hotswap
U1: ProMicro; ProMicro_v2
h1, h2, h3, h4: hole; LEGO_HOLE
h7, h8: hole; LEGO_HOLE2

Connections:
GND: J1.C, JP1.1, JP8.1, L1.2, L2.2, L3.2, L4.2, L5.2, L6.2, L7.2, L8.2, L9.2, L10.2, L11.2, L12.2, L13.2, L14.2, L15.2, L16.2, L17.2, L18.2, L19.2, L20.2, RSW1.2, U1.3, U1.4, U1.23
LED: JP9.2, U1.1
unnamed: D1.2, SW1.2
unnamed: D2.2, SW2.2
unnamed: D3.2, SW3.2
unnamed: D4.2, SW4.2
unnamed: D5.2, SW5.2
unnamed: D6.2, SW6.2
unnamed: D7.2, SW7.2
unnamed: D8.2, SW8.2
unnamed: D9.2, SW9.2
unnamed: D10.2, SW10.2
unnamed: D11.2, SW11.2
unnamed: D12.2, SW12.2
unnamed: D13.2, SW13.2
unnamed: D14.2, SW14.2
unnamed: D15.2, SW15.2
unnamed: D16.2, SW16.2
unnamed: D17.2, SW17.2
unnamed: D18.2, SW18.2
unnamed: D19.2, SW19.2
unnamed: D20.2, SW20.2
unnamed: J1.A, JP12.2
unnamed: J1.B, JP10.2, JP11.2
unnamed: J2.1, J3.1, JP1.2, JP5.2
unnamed: J2.2, J3.2, JP2.2, JP6.2
unnamed: J2.3, J3.3, JP3.2, JP7.2
unnamed: J2.4, J3.4, JP4.2, JP8.2
unnamed: JP9.1, L1.3
unnamed: L1.1, L2.3
unnamed: L2.1, L3.3
unnamed: L3.1, L4.3
unnamed: L4.1, L5.3
unnamed: L5.1, L6.3
unnamed: L6.1, L7.3
unnamed: L7.1, L8.3
unnamed: L8.1, L9.3
unnamed: L10.1, L11.3
unnamed: L9.1, L10.3
unnamed: L11.1, L12.3
unnamed: L12.1, L13.3
unnamed: L13.1, L14.3
unnamed: L14.1, L15.3
unnamed: L15.1, L16.3
unnamed: L16.1, L17.3
unnamed: L17.1, L18.3
unnamed: L18.1, L19.3
unnamed: L19.1, L20.3
SCL: JP3.1, JP6.1, JP11.1, R2.1, U1.6
SDA: JP4.1, JP5.1, JP12.1, R1.2, U1.5
VCC: J1.D, JP2.1, JP7.1, L1.4, L2.4, L3.4, L4.4, L5.4, L6.4, L7.4, L8.4, L9.4, L10.4, L11.4, L12.4, L13.4, L14.4, L15.4, L16.4, L17.4, L18.4, L19.4, L20.4, R1.1, R2.2, U1.21
col0: J4.1, SW1.1, SW2.1, SW3.1, SW4.1, U1.7
col1: J4.2, SW5.1, SW6.1, SW7.1, SW8.1, U1.8
col2: J4.3, SW9.1, SW10.1, SW11.1, SW12.1, U1.9
col3: J4.4, SW13.1, SW14.1, SW15.1, SW16.1, U1.10
col4: J4.5, SW17.1, SW18.1, SW19.1, SW20.1, U1.11
col5: J4.6, U1.12
data: JP10.1, U1.2
reset: RSW1.1, U1.22
row0: D1.1, D5.1, D9.1, D13.1, D17.1, U1.20
row1: D2.1, D6.1, D10.1, D14.1, D18.1, U1.19
row2: D3.1, D7.1, D11.1, D15.1, D19.1, U1.18
row3: D4.1, D8.1, D12.1, D16.1, D20.1, U1.17
row4: J5.1, U1.16
row5: J5.2, U1.15
row6: J5.3, U1.14
row7: J5.4, U1.13

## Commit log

2018-12-20 rhymestone: add led
2018-12-20 rhymestone: add diode section
2019-01-29 treadstone48: added woodcase cut file
2019-02-01 rhymestone: added pcb project
    [Rhymestone.kicad_pcb, Rhymestone.sch, Rhymestone_plate.kicad_pcb]
2019-02-02 stonehenge30: added pcb data and case data
    [Stonehenge30.kicad_pcb, Stonehenge30.sch]
2019-02-02 stonehenge30: move directory
    [Stonehenge30.kicad_pcb, Stonehenge30.sch]
2019-02-03 stonehenge30: fixed led line.
    [Stonehenge30.kicad_pcb]
2019-02-04 all: update and add: case and plate file
    [Treadstone48_plate.kicad_pcb]
2019-02-06 add case readme
2019-02-12 stonehenge30: update case
2019-02-13 stonehenge30: add pcbmount
2019-02-26 stonehenge30: fixed case data
2019-03-05 rhymestone: add mount plate in case data
2019-06-06 Treadstone48: Add pcb data. Enjoy!
    [Treadstone48.kicad_pcb, Treadstone48.sch, Treadstone48_plate.kicad_pcb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]
2019-07-24 treadstone48: added pcb rev1.3
    [Treadstone48.kicad_pcb, Treadstone48.sch, Treadstone48_plate.kicad_pcb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]
2019-07-24 treadstone32: added pcb rev1.1
    [Treadstone32.kicad_pcb, Treadstone32.sch, Treadstone32_bottomplate.kicad_pcb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]
2019-07-24 treadstone32: added case data
2019-07-29 treadstone32: remove old data and rename case file
    [Treadstone32_case.kicad_pcb, Treadstone32_top_plate.kicad_pcb]
2019-08-20 treadstone32: add case photos
2020-08-31 [leftover30]add side acrylic plate
